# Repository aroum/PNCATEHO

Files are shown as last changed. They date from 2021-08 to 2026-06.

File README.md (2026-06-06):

<p align="center">
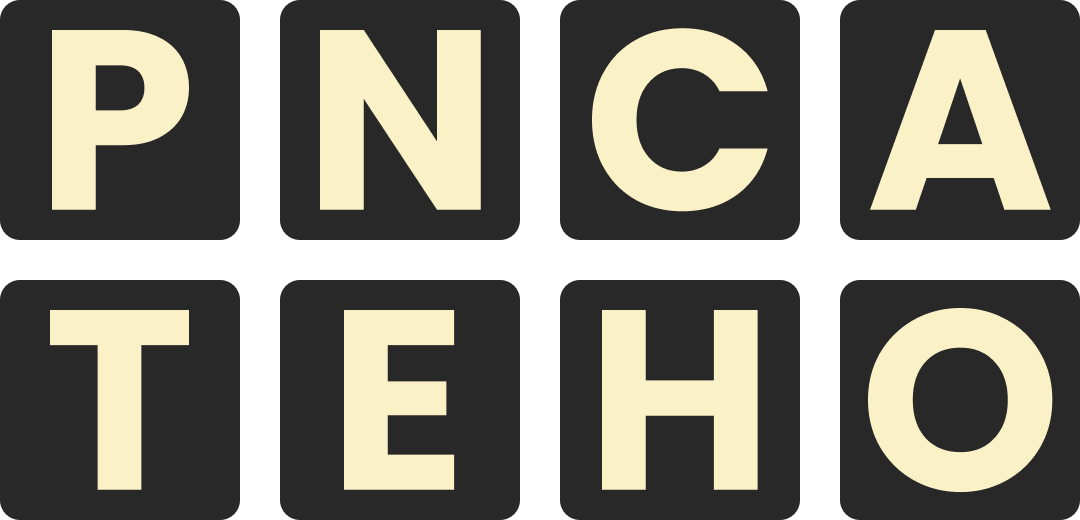
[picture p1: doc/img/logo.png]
  
</p>
<p align="center">
  
  
  
</p>
<p align="center">
  <a href="https://github.com/aroum/PNCATEHO/tree/master/firmware">Firmware | </a>
  <a href="https://github.com/aroum/PNCATEHO/releases">Gerber | </a>
  <a href="../doc/socket.md">About socket</a>
</p>

---

## About

РИСАТЕНО (__RISATENO__) - created as a rethinking of [ARTSEY](https://artsey.io/) for the Russian language. 10 keys, two for each finger. The name is made up of letters on the main layer. The letters on the base layer are selected according to the. The original idea was to create a compact keyboard for chord typing, but it can also be used as a macro pad. When using two halves of РИСАТЕНО connected via Bluetooth, you can use the [Kladenets layout](https://ibnteo.github.io/kladenets/). But over time, PNCATEHO became something more. It is a synthesizer, a sampler, a MIDI keyboard, and a vast playground for your other experiments.

## Eras

Eras are a way to classify different versions of a project. The Stone Era reflects original ideas. The Glass Era reflects the community's desires and experiments with new switches. The Light Era illuminates the vision of the creators who use this project as a platform for professional growth and attempt what others were afraid to do.

| Name | Alt Name  | Era | Swtiches | Hot-swap | LED | Wireless | MCU |
| --- | --- | ----- | --- | --- | --- | --- | --- |
| V4 | - | Stone | Choc V1 | ❌ | Per-key | Optional | proMicro like |
| V5 | - | Glass | Choc V1/V2 | ✅ | Per-key | Optional | proMicro like |
| MK_Dose | Dozateno  | Glass | MK Dose/MX | ✅ | 3 Led indication | Optional | proMicro like |
| Welcome | Nizkoteno | Light | PG1316S | ❌<br> | Per-key | ❌<br> | rp2040 |

### Stone

The standard version of PNCATEHO from the Stone era. Supports per-key backlighting, the option to use a wireless controller with an external power switch and reset button, and an open case. It does not support hot-swapping switches and only supports Choc V1. [more about stone](stone/readme.md)

> [!WARNING]  
> In version 0.3 of the board there is a bug with the backlight on the right-hand half.

#### V0.3

<p align="center">
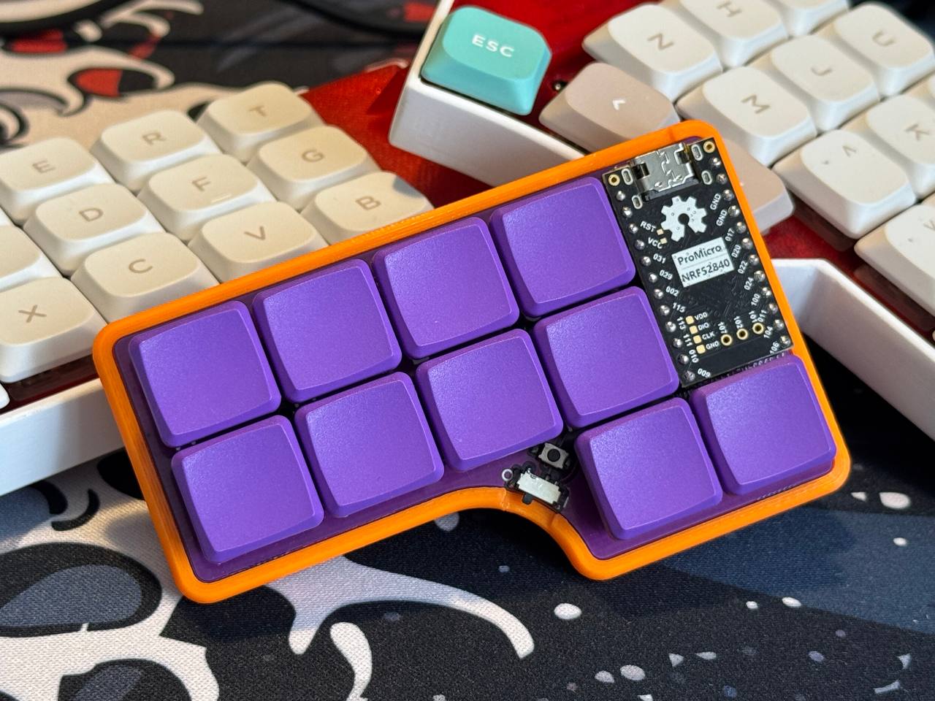
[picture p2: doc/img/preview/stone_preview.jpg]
  
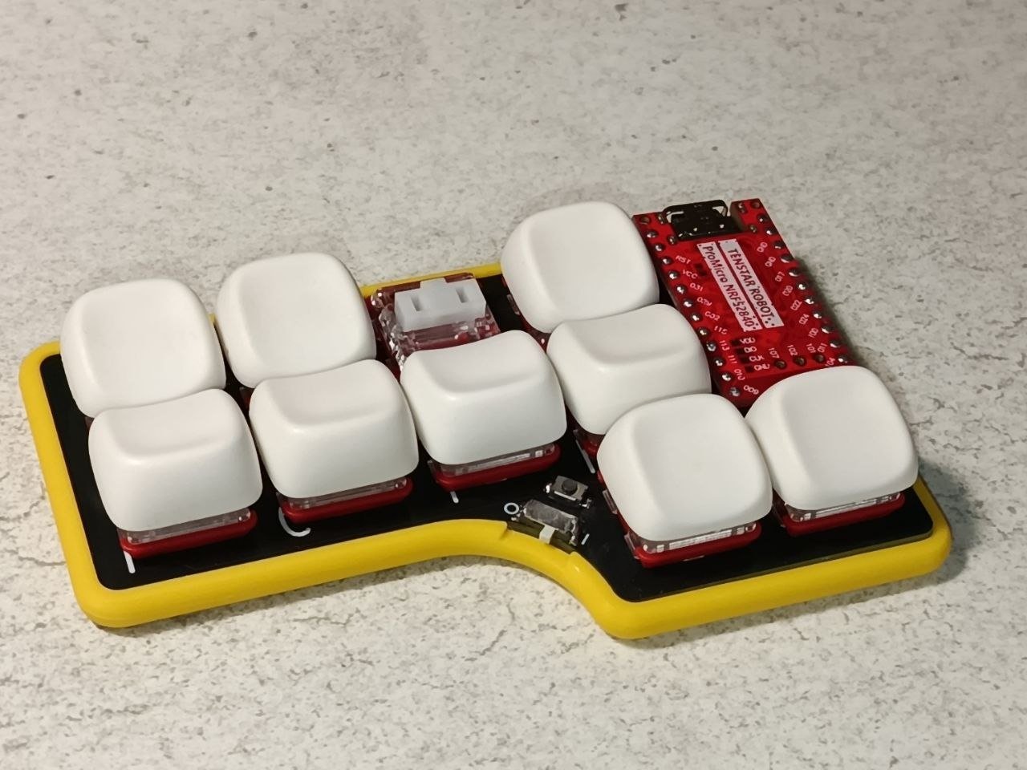
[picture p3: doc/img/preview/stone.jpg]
  
</p>

#### 3D

<p align="center">
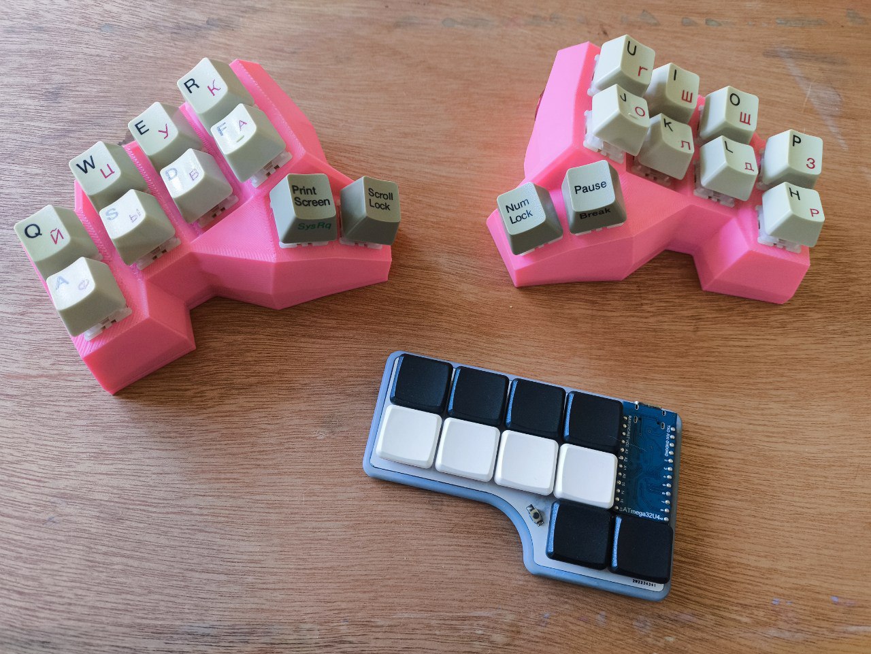
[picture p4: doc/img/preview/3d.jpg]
  
</p>

### Glass

The modern era of PNCATEHO development. It differs from the Stone era in that it supports hot-swappable keys and ChocV1/V2, MK Dose, and MX switches. It also uses closed cases and a new design approach by turtle_bazon. [more about Glass](glass/readme.md)

> [!TIP]
> If you want to build a PNCATEHO with MX switches, you can use the PCB from MK Dose.

#### V5

<p align="center">
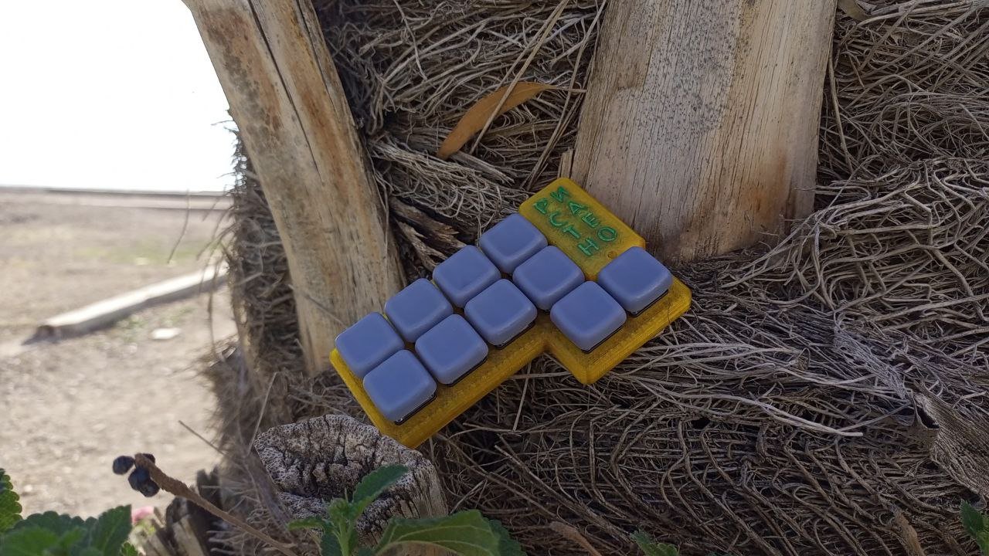
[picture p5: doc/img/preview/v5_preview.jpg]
  
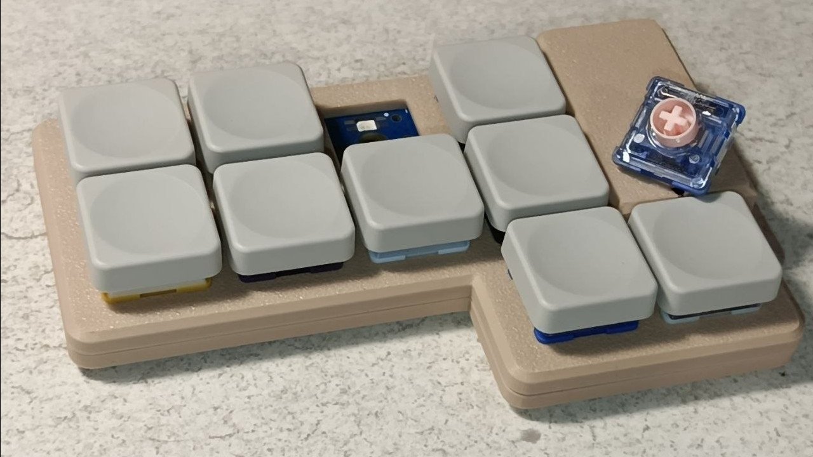
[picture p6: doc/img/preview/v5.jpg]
  
</p>

#### MK_Dose

<p align="center">
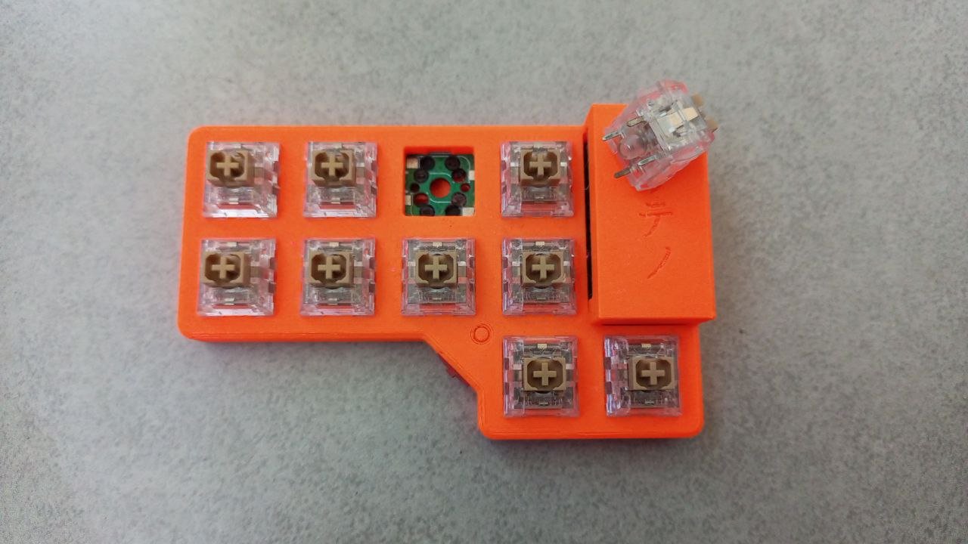
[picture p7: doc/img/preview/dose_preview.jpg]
  
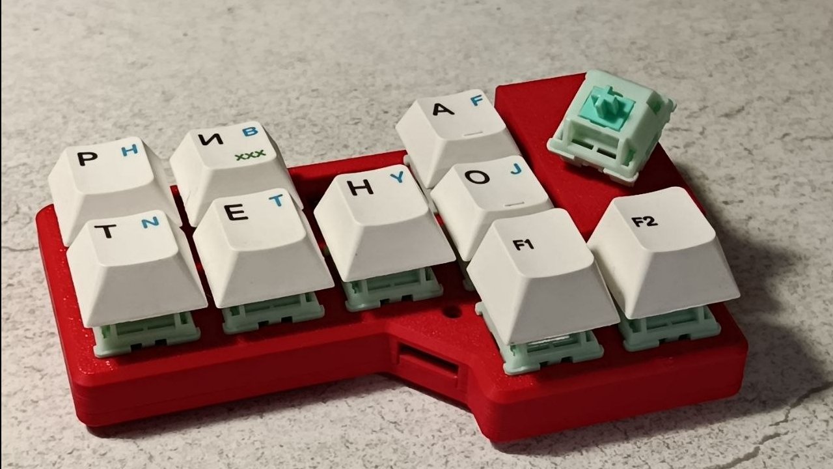
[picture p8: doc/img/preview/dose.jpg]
  
</p>

### Light

This is an era where the controller is soldered directly onto the PCB, exploring various form factors such as, for example, a PNCATEHO the size of a card. A project can become a flashlight, a development board, or even a portable gaming console. It all depends on the imagination of the community. The main contribution to this era has been made by the authors of the inpudiy community. [more about light](light/readme.md)

#### Welcome

<p align="center">
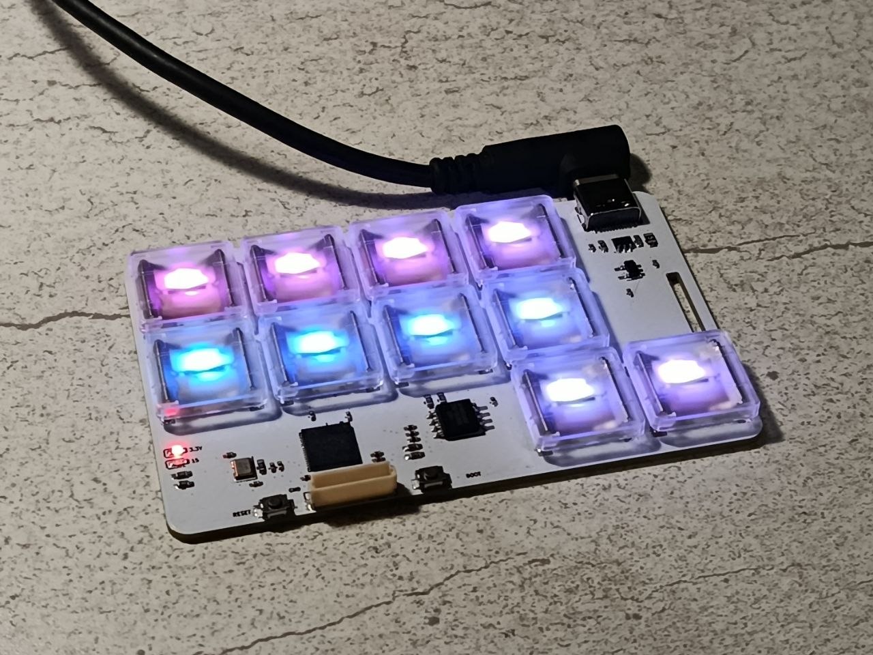
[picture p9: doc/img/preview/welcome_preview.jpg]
  
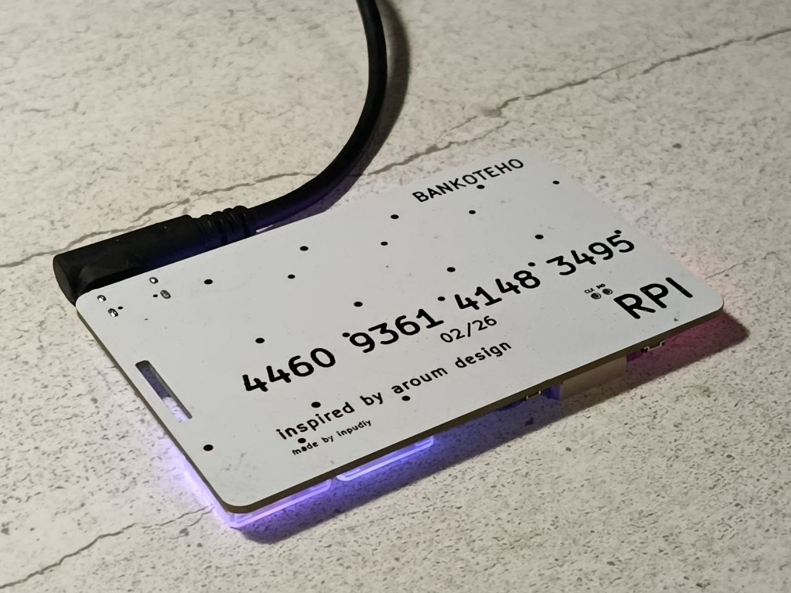
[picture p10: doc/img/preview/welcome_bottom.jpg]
  
</p>

## FAQ

### What is it for?

First and foremost, PNCATEHO is a fun project. It shouldn't be treated as an everyday keyboard—it’s more of a novelty, like a fridge magnet. That said, some people actually try to apply PNCATEHO's concepts to their daily-driver keyboards.

In many ways, the project served as a testing ground for experimenting with chording and exploring just how far you can minimize the number of keys. Of course, nothing stops you from using PNCATEHO as a macropad. There are also firmwares available to turn PNCATEHO into a sampler, synthesizer, or MIDI keyboard.

I wanted to design a layout that was simple and intuitive, yet still capable of acting as a near-full replacement for a standard keyboard. Unlike ARTSEY, I don’t use chords that require pressing more than two keys simultaneously. I also designed the layout based on letter frequency rather than just picking pleasant-sounding combinations. On top of that, I added two thumb keys—it felt odd to allocate two keys for every other finger while leaving the thumbs with nothing.

### Why PNCATEHO/RISATENO/РИСАТЕНО?

PNCATEHO is a loose transliteration of the Russian word "РИСАТЕНО" (RISATENO) into the Latin alphabet. The layout was designed based on letter frequency ([Wikipedia](https://ru.wikipedia.org/wiki/%D0%A7%D0%B0%D1%81%D1%82%D0%BE%D1%82%D0%BD%D0%BE%D1%81%D1%82%D1%8C)), where the first eight letters are four vowels ('И', 'А', 'Е', 'О') and four consonants ('Р', 'С', 'Т', 'Н'). To create a pronounceable name, they can be grouped into syllables: reading them one way gives __RISATENO__, and the other way gives __NOTESARI__ (options like "ONETASIR" were discarded as awkward-sounding). The second option felt a bit too "samurai," so I went with the first.

As a nice bonus, if you set aside the Cyrillic letter "И", the name transliterates perfectly into the Latin alphabet, and the letter "N" works great as a visual substitute for "И".

### Why no ergonomic stagger?

PNCATEHO was never meant to be an everyday keyboard—aesthetics take priority over ergonomics here, and in my opinion, ortholinear layouts look much cleaner. Besides, when you only have two keys per finger, column-staggering doesn't really make much of a difference anyway.

### How do you type on it?

Letter by letter, “dancing” your fingers to form chords. I tried to distribute chords by ease of pressing, so that the most common symbols use the simplest and most comfortable combinations. With some effort, you can learn all the common chords in a couple of days and, although slowly, fully type using just 10 keys with one hand.

It’s quite an unusual experience, especially if you’ve never used chords before. I strongly recommend printing the layout ([GitHub](https://github.com/aroum/PNCATEHO/tree/master/firmware)) and opening any beginner touch-typing app — even if you already know how to type on a regular keyboard, this will be a completely new and unique experience that you’ll likely never need anywhere else.

### Is this steno?

No, steno works completely differently ([example layout](https://github.com/openstenoproject/plover/files/247728/Russian.alphabet.and.layout.pdf)). It requires more keys and a different method. PNCATEHO, on the other hand, is letter-by-letter input based on frequency.

If you’re interested in steno, it’s worth starting with [Plover](https://www.openstenoproject.org/plover/).

## Inspiration

* [ARTSEY](https://artsey.io/)
* [The Paintbrush](https://github.com/artseyio/thepaintbrush)
* [Helix](https://github.com/MakotoKurauchi/helix)
* [wakizashi](https://klava.wiki/hypha/%D0%BA%D0%BB%D0%B0%D0%B2%D0%B8%D0%B0%D1%82%D1%83%D1%80%D1%8B/%D0%B2%D0%B0%D0%BA%D0%B8%D0%B4%D0%B7%D0%B0%D1%81%D0%B8) (saw after the release of PNCATEHO)

## Contribute list

* [aroum](https://github.com/aroum)
* [mayoroffk](https://github.com/mayoroffk)
* [turtle-bazon](https://github.com/turtle-bazon)
* [miwoho](https://github.com/miwoho)

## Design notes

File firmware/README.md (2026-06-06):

# Firmware

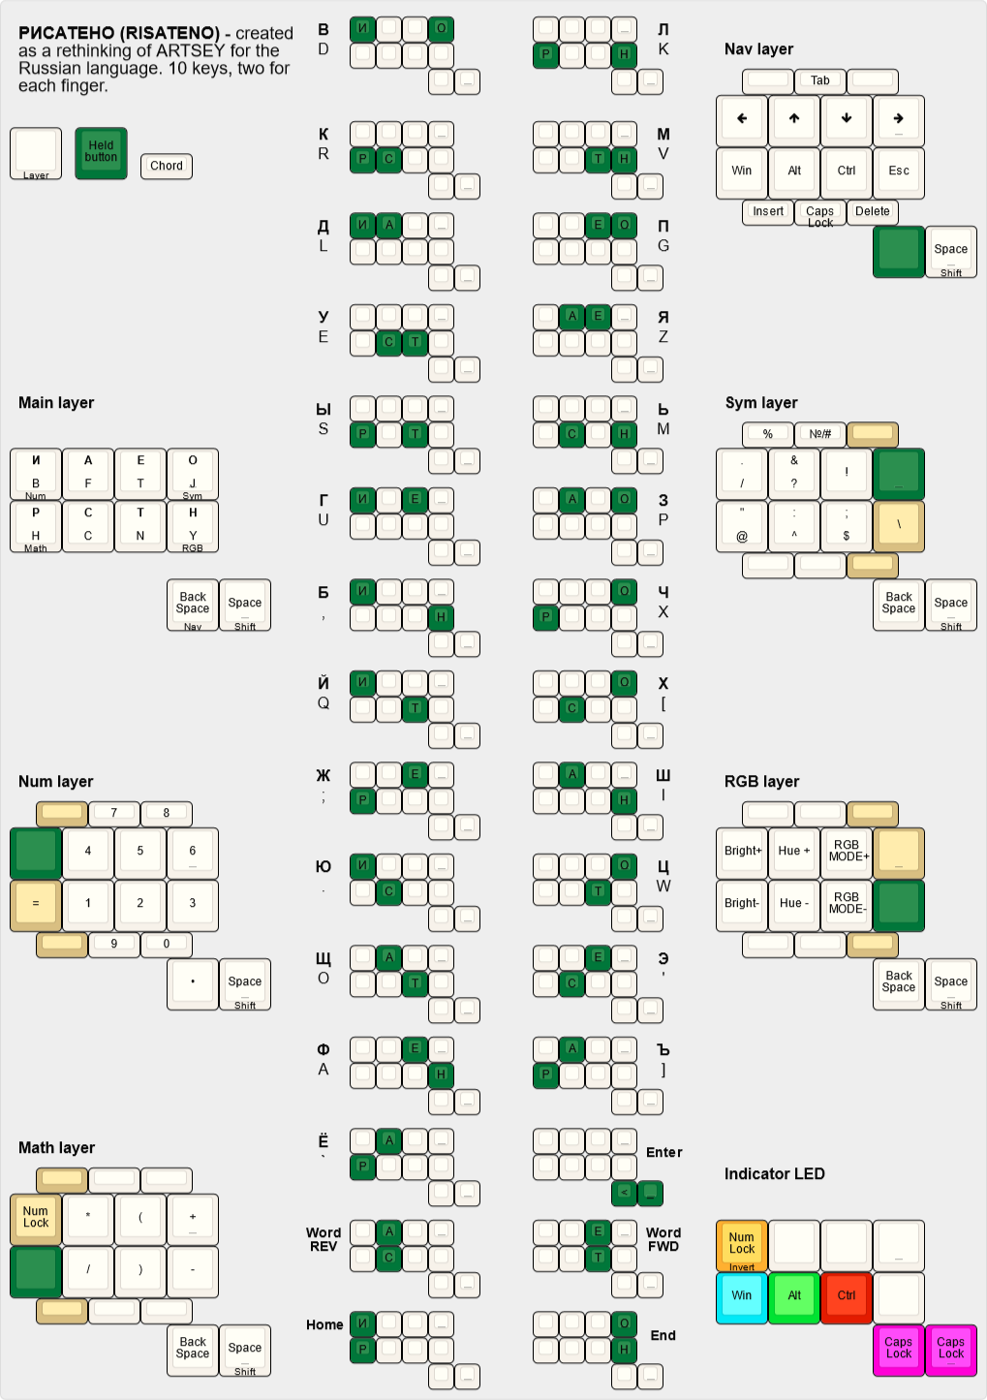
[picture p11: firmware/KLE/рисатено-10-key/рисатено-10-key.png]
layout


The core concept of PNCATEHO is to use only 2-key chords for all inputs, making it an efficient 10-key keyboard with extensive functionality.

## KLE

[Layout on the KLE website](http://www.keyboard-layout-editor.com/#/gists/019e404b4ab5db93cd75010ad90777a4)

[Unused chords on the KLE website](http://www.keyboard-layout-editor.com/#/gists/b4924b372f7e59832365545de1e1671c)

## QMK

QMK is the recommended firmware for most PNCATEHO variants. It provides full feature support including macros and layer switching.

**Installation:**

1. Copy the `QMK/PNCATEHO` folder to your QMK installation at `keyboards/pncateho`
2. Run `qmk compile -kb pncateho -km default`
3. Flash the resulting `.hex` file to your keyboard

Or download precompiled firmware from [releases](https://github.com/aroum/PNCATEHO/releases).

For more information, see [QMK documentation](https://docs.qmk.fm/).

## ZMK

ZMK is a lightweight firmware designed for wireless keyboards. Configuration and builds are available in separate repositories:

- **For nizkoteno**: [ZMK config for nizkore](https://github.com/inpudiy/zmk-PNCATEHO_Welcome_keyboard)
- **For other variants**: [ZMK config for PNCATEHO](https://github.com/aroum/zmk-PNCATEHO)

## RMK

RMK (Rust Mechanical Keyboard) is a Rust-based firmware for RP2040 microcontrollers. The implementation is optimized for nizkoteno but can be adapted to other PNCATEHO variants by modifying the pin configuration.

- Repository: [rmk-nizkoteno](https://github.com/aroum/rmk-nizkoteno/)
- **Compatibility:** Works with any PNCATEHO variant (except dozateno) when using an RP2040-based microcontroller

## MIDI

A simple MIDI keyboard implementation for nizkoteno. This firmware turns your PNCATEHO into a MIDI controller, perfect for music production and DAW integration.

- Repository: [midi-nizkoteno](https://github.com/aroum/midi-nizkoteno)
- **Compatibility:** Works with any PNCATEHO variant (except dozateno) when using an RP2040-based microcontroller with adjusted pin configuration

## nizkore

A sampler firmware port from pikocore, offering sound playback and sequencing capabilities. Originally created for nizkore but can be adapted to other PNCATEHO variants.

- Repository: [nizkore](https://github.com/aroum/nizkore/)
- **Compatibility:** Works with any PNCATEHO variant (except dozateno) when using an RP2040-based microcontroller with adjusted pin configuration

## pra32-u

A synthesizer firmware port optimized for the nizkoteno form factor. Enables real-time synthesis and parameter control directly from the keyboard.

- Repository: [pra32-u-pico-sdk](https://github.com/aroum/pra32-u-pico-sdk/)
- **Compatibility:** Works with any PNCATEHO variant (except dozateno) when using an RP2040-based microcontroller with adjusted pin configuration

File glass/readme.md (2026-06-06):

# glass

The modern era of PNCATEHO development. It differs from the Stone era in that it supports hot-swappable keys and ChocV1/V2, MK Dose, and MX switches. It also uses closed cases and a new design approach by turtle_bazon.

## v5

An updated version of the PCB by turtle_bazon. It retains the core features of the Stone era, while adding support for Choc V2, as well as hot-swappable switches, an enclosed case, and a PCB with a more refined design.

preview

<p align="center">
  <a href="case/v5/">Case | </a>
  <a href="build_v5.md">Build Guide</a>
</p>

### Features

* 10 keys, Kailh Choc **V1/V2** switches
* **Hot-Swap Socket**
* MX spacing
* Direct pins
* Three mounting screws
* One PCB for right and left versions
* Wireless (optional)
* Per switch RGB (optional)
* Power switch for wireless controllers (optional)
* Two halves placed on one 100x100mm pcb (optional)

### PCB

The current PCB version is 0.5.2. For manufacturing, it is recommended to use 100×100 mm Gerber files. This way, 5 boards become 10 halves (with an extra cute keychain in between).

<p align="center">
  
  
</p>

### Case

To assemble the case, you need to print the following files:

* PNCATEHO_MK_DOSE-case-bottom-left - top part of the case
* PNCATEHO_MK_DOSE-case-top-left.step -  bottom part of the case
* PNCATEHO_MK_DOSE-reset-button-pusher.step - reset button actuator
* PNCATEHO_MK_DOSE-case-top-cover-blank-left - controller cover

There are also different versions of the controller cover with katakana or lp. Additionally, the case [directory](../glass/case/MK_DOSE) includes an editable FreeCAD file: **PNCATEHO_v5.FCStd**.

### BOM

| Item | Quantity | Remarks |
| --- | ---: | --- |
| nice!nano | 1 | or any other pro micro compatible controller |
| Kailh Choc V1/2 | 10 | switches |
| Hot swap sockets | 10 | CPG135001S30 |
| YS-SK6812MINI-E | 10 | RGB leds |
| Machine Pin Socket with 2.54mm pitch | 12x2 | for controller |
| RGB Led pin or brass wire | 12x2 | for pin header |
| SMD button 3x4x2mm | 1 | for reset |
| MSK-12C02 | 1 | power switch  (wireless only) |
| 301230 3.7v li-po | 1 | battery  (wireless only) |
| Silicone rubber feet | 5 | 10x2 mm |
| M2х6 screw | 3 | for case |
| Keycaps | 10 | 1U |

## MK Dose (dozateno)

A version of the PCB designed for MK Dose format switches. It also supports standard MX switches. It differs by lacking per-switch backlighting, but includes indication using three SMD LEDs. Like V5, it features an enclosed case available in several variations.

preview

<p align="center">
  <a href="case/MK_DOSE/">Case | </a>
  <a href="build_mkdose.md">Build Guide</a>
</p>

### Features

* 10 keys, MK Dose/MX switches
* 3 Led indication
* **Hot-Swap Socket**
* MX spacing
* Three mounting screws
* One PCB for right and left versions
* Wireless (optional)
* Power switch for wireless controllers (optional)
* Two halves placed on one 100x100mm pcb (optional)

### PCB

it is recommended to use 100×100 mm Gerber files. This way, 5 boards become 10 halves (with an extra cute keychain in between).

<p align="center">
  
  
</p>

### Case

To assemble the case, you need to print the following files:

* PNCATEHO_v5-bottom-case-left - top part of the case
* PNCATEHO_v5-top-case-left.step -  bottom part of the case
* PNCATEHO_v5-power-switch-pusher.step - power switch actuator
* PNCATEHO_v5-reset-button-pusher.step - reset button actuator
* PNCATEHO_v5-top-cover-left-blank.step - controller cover

There are also different versions of the controller cover with the **PNCATEHO** label in *ReggageOne* or *RubikMonoOne* fonts.
Additionally, the case [directory](../glass/case/v5) includes an editable FreeCAD file: **PNCATEHO_MK_DOSE.FCStd*.

### BOM

| Item | Quantity | Remarks |
| --- | ---: | --- |
| nice!nano | 1 | or any other pro micro compatible controller |
| MK Dose or MX Swtich | 10 | switches |
| Hot swap sockets | 10 or 20 | CPG151101S11 |
| Diode 1N4148W | 10 or 20 | for matrix |
| 0603 led | 3 | for indication |
| 0603 1-10k resitsor | 3 | for led |
| Machine Pin Socket with 2.54mm pitch | 12x2 | for controller |
| RGB Led pin or brass wire | 12x2 | for pin header |
| SMD button 3x4x2mm | 1 | for reset |
| BSI-10H | 1 | power switch  (wireless only) |
| 301230 3.7v li-po | 1 | battery  (wireless only) |
| Silicone rubber feet | 5 | 8x2 mm |
| m2х8 screw | 3 | for case |
| Keycaps | 10 | 1U |

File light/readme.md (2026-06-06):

# light

This is an era where the controller is soldered directly onto the PCB, exploring various form factors such as, for example, a PNCATEHO the size of a card. A project can become a flashlight, a development board, or even a portable gaming console. It all depends on the imagination of the community. The main contribution to this era has been made by the authors of the inpudiy community.

## welcome (nizkoteno)

A credit card–sized RP2040-based PCB with a clean design, PG1316 low-profile switches, and integrated per-key RGB lighting.

preview

<p align="center">
  <a href="https://htmlpreview.github.io/?https://github.com/inpudiy/PNCATEHO/blob/master/light/welcome/doc/ibom.html" style="text-decoration: none;">IBOM |</a>
  <a href="welcome/doc/schematic.pdf" style="text-decoration: none;"> Schematic PDF | </a>
  <a href="welcome/doc/build.md" style="text-decoration: none;"> Build guide</a>
</p>

### Features

* 10 low profile keys, PG1316 switches
* Debit card dimensions (ISO/IEC 7810 ID-1)
* Per switch WS2812 2020 led
* Soldered directly onto the RP2040 board
* ESD protection
* 16 MB flash memory
* cutout for a strap
* exposed 10-pin JST connector for connecting modules

### PCB

The current PCB version is v1.1. For ordering, specify a board thickness of 1.6 mm and a stencil for the top side of the board.

<p align="center">
  
  
</p>

### JST

A BM10B-SRSS-TB connector is installed on the board. This is a 10-pin JST connector with a 1 mm pitch. The leftmost pin is connected to ground, and the rightmost pin provides 3.3V. Between them, the following GPIOs are exposed: 29, 28, 27, 26, 24, 21, 20, 19.

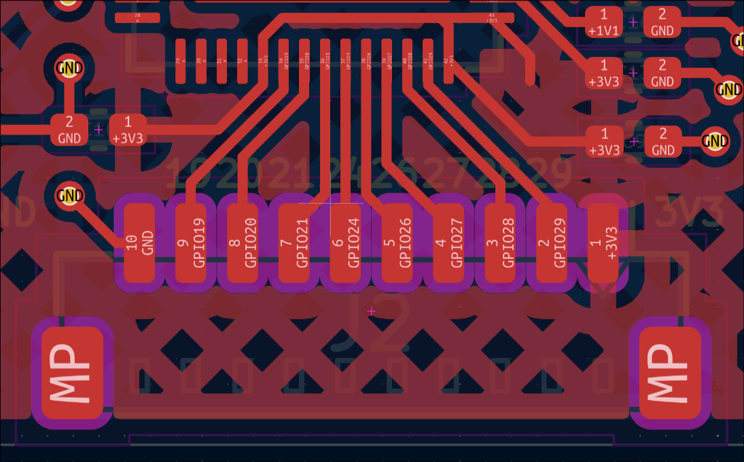
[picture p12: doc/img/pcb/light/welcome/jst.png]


To run the controller, a stable 3.3V supply is required, while the RGB pins should receive 5V.

> [!WARNING]  
> DO NOT attempt to connect an external 3.3V supply while simultaneously powering the board via USB.

### Firmwares

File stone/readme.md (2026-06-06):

# STONE

The standard version of PNCATEHO from the Stone era. Supports per-key backlighting, the option to use a wireless controller with an external power switch and reset button, and an open case. It does not support hot-swapping switches and only supports Choc V1.

preview

<p align="center">
  <a href="case/case_v4.stp">Case | </a>
  <a href="build.md">Build Guide</a>
</p>

## V0.3

### Features

* 10 keys, Kailh Choc V1 switches
* Choc spacing
* Direct pins
* Three mounting screws
* One PCB for right and left versions
* Wireless (optional)
* Per switch RGB (optional)
* Power switch for wireless controllers (optional)
* Two halves placed on one 100x100mm pcb (optional)

### PCB

There are several versions of the PCB. In version 0.3, the right half has an error in the LED footprints, so the backlighting can only be installed facing downward. This issue, along with other minor ones, was fixed in version 0.4.

For manufacturing, it is recommended to use 100×100 mm Gerber files. This way, 5 boards become 10 halves (5 right and 5 left).

### Case

In the case directory, there are two STEP files. case_v4.stp does not have cutouts for rubber feet, while case_v4_flex.stp includes 7 cutouts for rubber feet.

<p align="center">
  
  
</p>

### Plate

No plate is needed for choc, but if you want you can order PCB or laser cut. These don't fit version 3 boards because you can't add screw cutouts.

### BOM

| Item | Quantity | Remarks |
| --- | ---: | --- |
| nice!nano | 1 | or any other compatible controller |
| Kailh Choc V1 | 10 | switches |
| Keycaps | 10 | 1U |
| YS-SK6812MINI-E | 10 | RGB leds |
| Magnets | 2-6 | disc 7x2 mm (for case) |
| Sockets PH5.0mm | 12x2 | for controller |
| SMD button 3x4x2mm | 1 | for reset |
| MSK-12C02 | 1 | power switch  (wireless only) |
| 301230 3.7v li-po | 1 | battery  (wireless only) |
| Silicone rubber feet | 7 | 5x2 mm |
| M2 nuts | 3 | for case v3+ |
| M2x4 sqrews | 3 | for case v3+ |

## 3D

preview

### Case

The case folder contains a STEP file. The controller, circuitry, and mounting method are entirely up to you.

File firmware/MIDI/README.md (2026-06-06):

# MIDI Firmware

This firmware transforms your PNCATEHO into a MIDI controller, enabling seamless integration with Digital Audio Workstations (DAWs), synthesizers, and other MIDI-compatible devices.

## Overview

A straightforward MIDI keyboard implementation originally developed for nizkore. The firmware can be adapted to other PNCATEHO variants by reconfiguring pin assignments.

## Repository

- [midi-nizkoteno](https://github.com/aroum/midi-nizkoteno)

## MIDI Channel Assignment

Each key combination can be configured to transmit on different MIDI channels. Refer to the source code or firmware documentation for detailed channel mapping.

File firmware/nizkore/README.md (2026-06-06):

# nizkore Firmware

nizkore is a powerful sampler firmware for PNCATEHO, enabling playback of audio samples and real-time control over playback parameters. It's a port of the pikocore sampler, optimized for the PNCATEHO form factor and 2-key chord interface.

## Overview

This firmware transforms your PNCATEHO into a portable audio sampler with intuitive 2-key chord-based control. Originally developed for nizkore, it can be adapted to other PNCATEHO variants using RP2040-based microcontrollers.

## Repository

- [nizkore](https://github.com/aroum/nizkore/)

## Compatibility

- **Supported:** nizkore and other PNCATEHO variants with RP2040-based microcontrollers
- **Unsupported:** dozateno (different microcontroller architecture)

For more information about pikocore, visit the [original project](https://github.com/schollz/pikocore).

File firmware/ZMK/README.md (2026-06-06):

# ZMK Firmware

ZMK is a modern, wireless-first firmware for mechanical keyboards, built on the Zephyr RTOS. It provides excellent battery life and advanced features for PNCATEHO variants.

## Configuration

Different PNCATEHO variants require different ZMK configurations:

### nizkoteno

For nizkoteno, use this dedicated configuration:

- [ZMK Config for nizkoteno](https://github.com/inpudiy/zmk-PNCATEHO_Welcome_keyboard)

### Other Variants

For all other PNCATEHO variants:

- [ZMK Config for PNCATEHO](https://github.com/aroum/zmk-PNCATEHO)

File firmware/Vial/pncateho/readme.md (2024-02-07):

# pncateho

*A short description of the keyboard/project*

* Firmware Maintainer: [Mayorov Kirill](https://github.com/FT256) [@Mayoroffk](https://t.me/mayoroffk)

Make example for this keyboard (after setting up your build environment):

    make pncateho:vial

Flashing example for this keyboard:

    make pncatehom:vial:flash

See the [build environment setup](https://docs.qmk.fm/#/getting_started_build_tools) and the [make instructions](https://docs.qmk.fm/#/getting_started_make_guide) for more information. Brand new to QMK? Start with our [Complete Newbs Guide](https://docs.qmk.fm/#/newbs).

## Bootloader

Enter the bootloader in 3 ways:

* **Bootmagic reset**: Hold down the top left up key and plug in the keyboard
* **Physical reset button**: Briefly press the button on the PCB
* **Keycode in layout**: Press the key mapped to `QK_BOOT` if it is available

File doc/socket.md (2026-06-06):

## Introduction

In order for a keyboard to register keystrokes, a microcontroller is used. Besides the microcontroller itself, it also requires supporting circuitry. Routing and soldering a board with a microcontroller significantly complicates the design and assembly process. To address this issue, development boards are used, which already have the microcontroller with the necessary supporting circuitry installed, as well as a charging module, a connection port, an antenna, and the required controller pins brought out, where the keyboard switches are directly connected.

In order to connect the keyboard switches to the development board, sockets are needed. Each creator uses their own solutions, so it is important to explain the differences between these approaches.

> [!IMPORTANT]
> The battery thickness may also depend on how the controller is installed. In most keyboards, controllers are mounted facing downward, so you need to subtract the height of the tallest component (the antenna or connector) from the socket height to determine the available space for the battery.

> [!WARNING]  
> PAY CLOSE ATTENTION TO THE SOCKET INFORMATION IN THE OFFICIAL REPOSITORY OF THE KEYBOARD YOU ARE BUILDING. DIFFERENT CONFIGURATIONS MAY BE USED FOR DIFFERENT CASE TYPES, EVEN WITHIN THE SAME PROJECT BUT IN DIFFERENT VERSIONS

## Main data

Let's start by defining the main data.

You might ask: why do we need a socket? Wouldn't it be simpler to just solder the boards together? Let’s imagine a situation where the development board fails, or conversely, the controller board is fine but the keyboard switches section is damaged. In such a case, you would have to desolder around 24 pins at once, or carefully remove solder from each pin individually. Trust me, you don’t want to do that—and if you do, it will take a lot of time and the chances of damaging the board increase significantly.

The solution to this problem is the use of sockets: female sockets are installed on the keyboard board, and male pins are soldered to the controller.

- Most likely, just like in PNCATEHO, your keyboard uses a Pro Micro–format board, which has 24 pins, and the board thickness is 1.6 mm (excluding components).
- On the vast majority of development boards, the pin spacing (pitch) is 2.54 mm.
- In popular wireless keyboard models, the battery most often used has dimensions H=3 mm, W=12 mm, and L=30 mm (301230).

## Dupont

### Square male pin header

A microcontroller development board comes with a row of **SQUARE** pins. These are sets of square posts held together by plastic, from which they can be easily removed. They can also be purchased separately in strips of 40 pins in different colors.

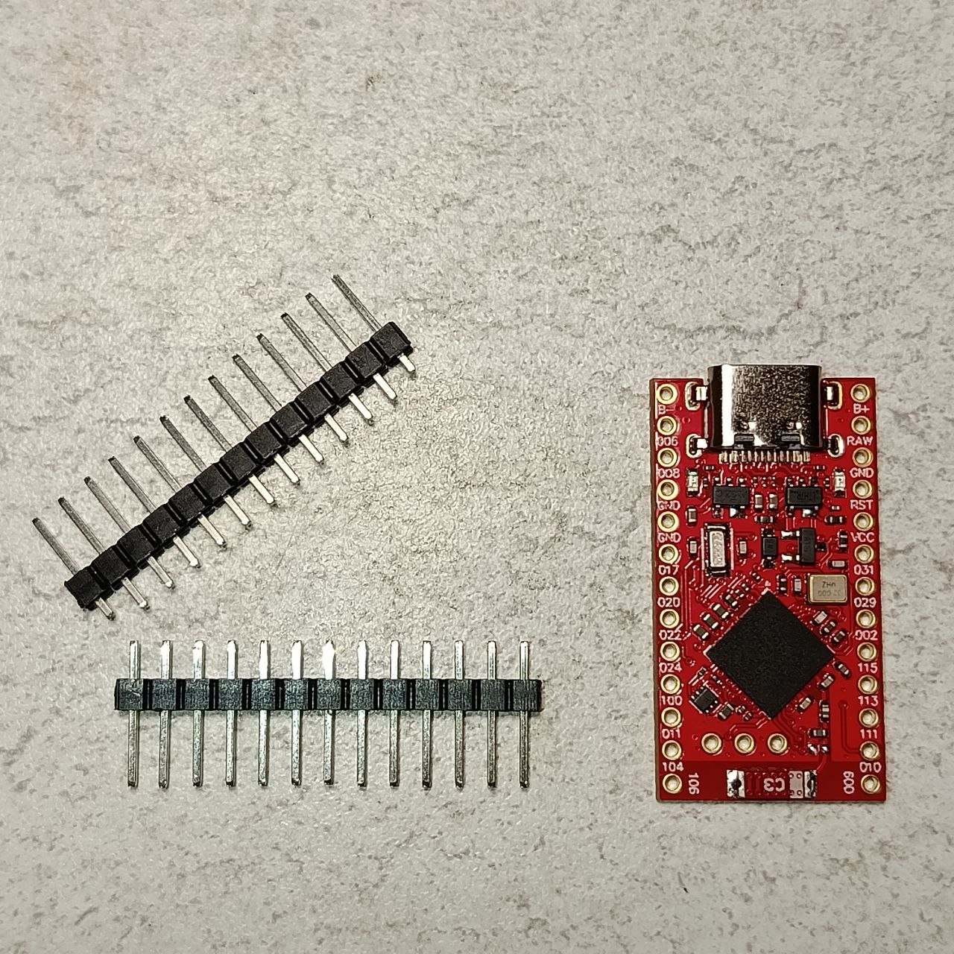
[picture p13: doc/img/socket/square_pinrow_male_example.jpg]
square


Due to the large number of manufacturers and the lack of strict quality control, the dimensions of these pins may differ from the datasheet by ±0.20 mm. For example, in my case, the plastic thickness is as much as 2.4 mm, while the pin length is only 11.32 mm instead of 11.5 mm.

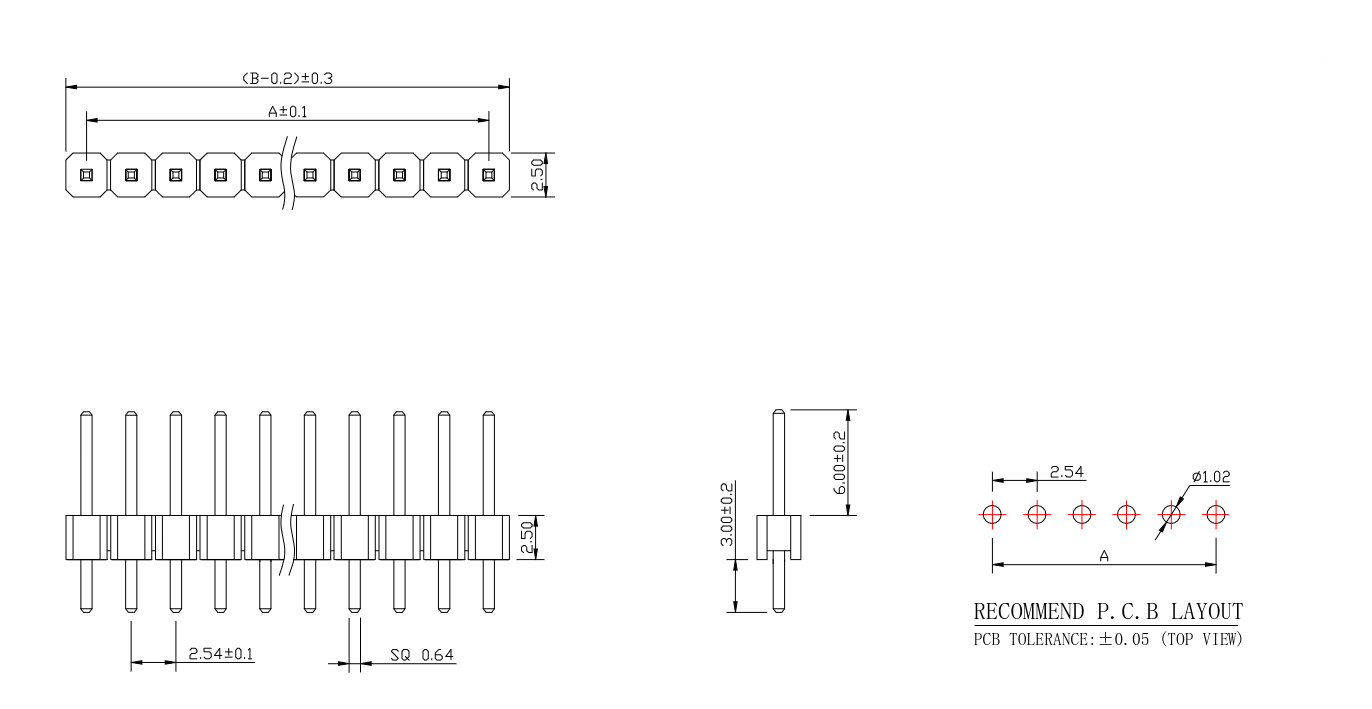
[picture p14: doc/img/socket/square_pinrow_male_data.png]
square


### Square female pin header

To use the pins that come in the kit, you need to purchase square pin headers. For keyboards, different height options are used; the most popular ones are 3.5 mm, 5 mm, and 5.7 mm anything taller is generally excessive.

The main issue is that the required sizes can be harder to find on common marketplaces (AliExpress and others). However, their strength and compatibility with the included pins make this option more practical compared to machine pin sockets.

Among the most common configurations, the following approaches can be highlighted:

#### First option

There are also configurations where the controller is installed with the flat side facing inward, allowing for a thicker battery. The examples below use a configuration where the controller is facing the PCB.

Install the sockets into the controller, cut off the top part, and remove the plastic. Then insert them into 5 mm or 5.7 mm pin headers. This spacing between the board and the controller allows the use of a 3+ mm thick battery.

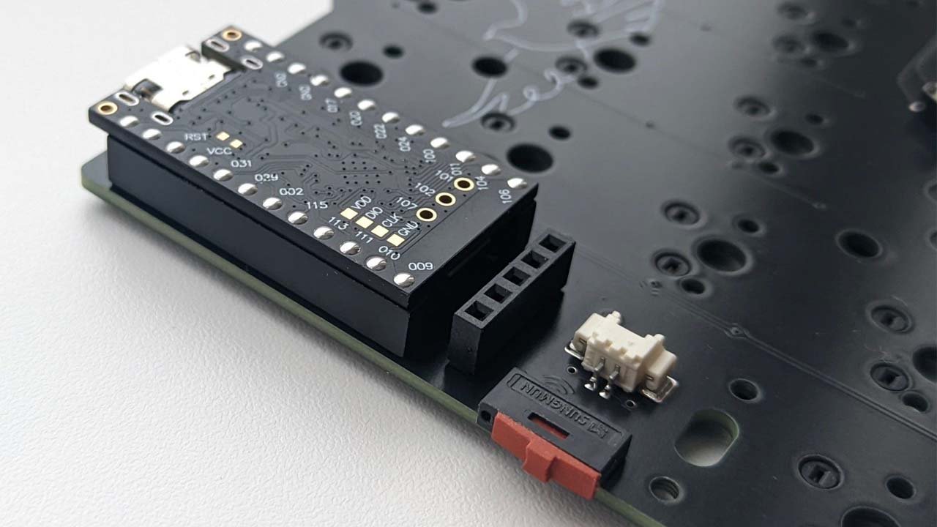
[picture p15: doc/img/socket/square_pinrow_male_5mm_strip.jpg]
square

*The keyboard in the photo: [Mriya](https://github.com/themaxbang/MRIYA)*

#### Second option

Use 3.5 mm pin headers, and install the stock sockets into the controller without removing the plastic only trim the pins above the controller. This also allows using a 31 mm thick battery.

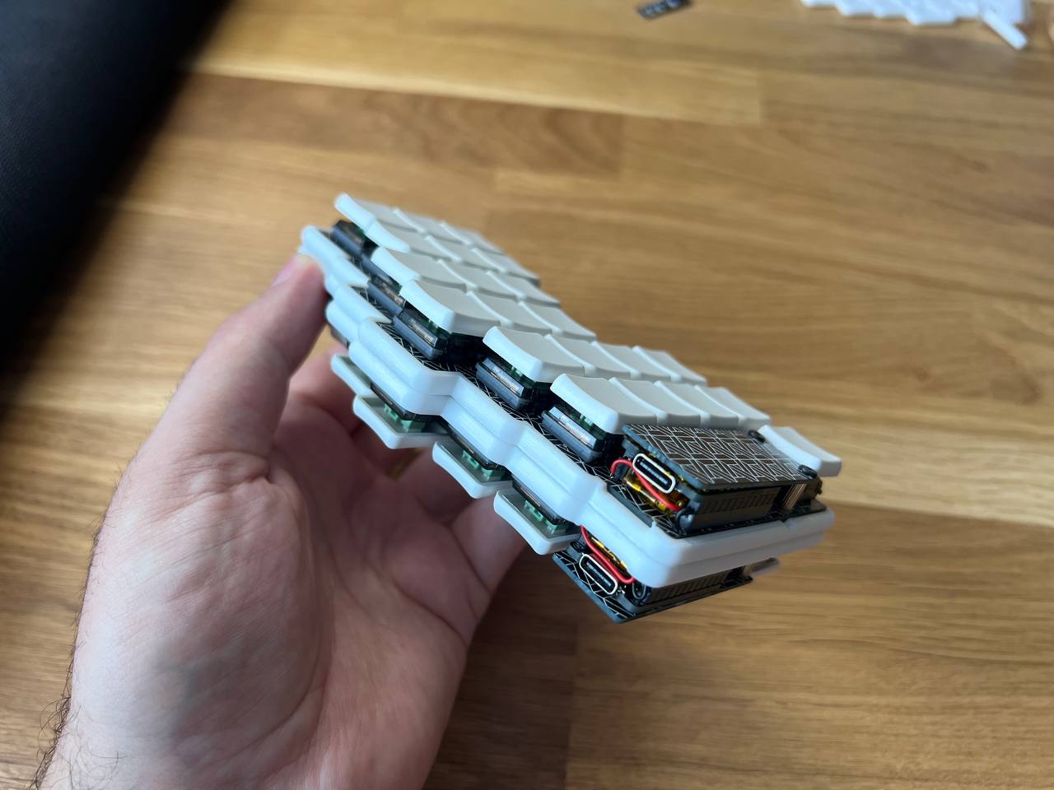
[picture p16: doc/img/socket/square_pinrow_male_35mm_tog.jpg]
square

*The keyboard in the photo: [gbEnki](https://github.com/aroum/gbEnki)*

#### Third option

Use 3.5 mm pin headers, remove the plastic from the stock sockets, and place a battery between the controller and the shield above it.

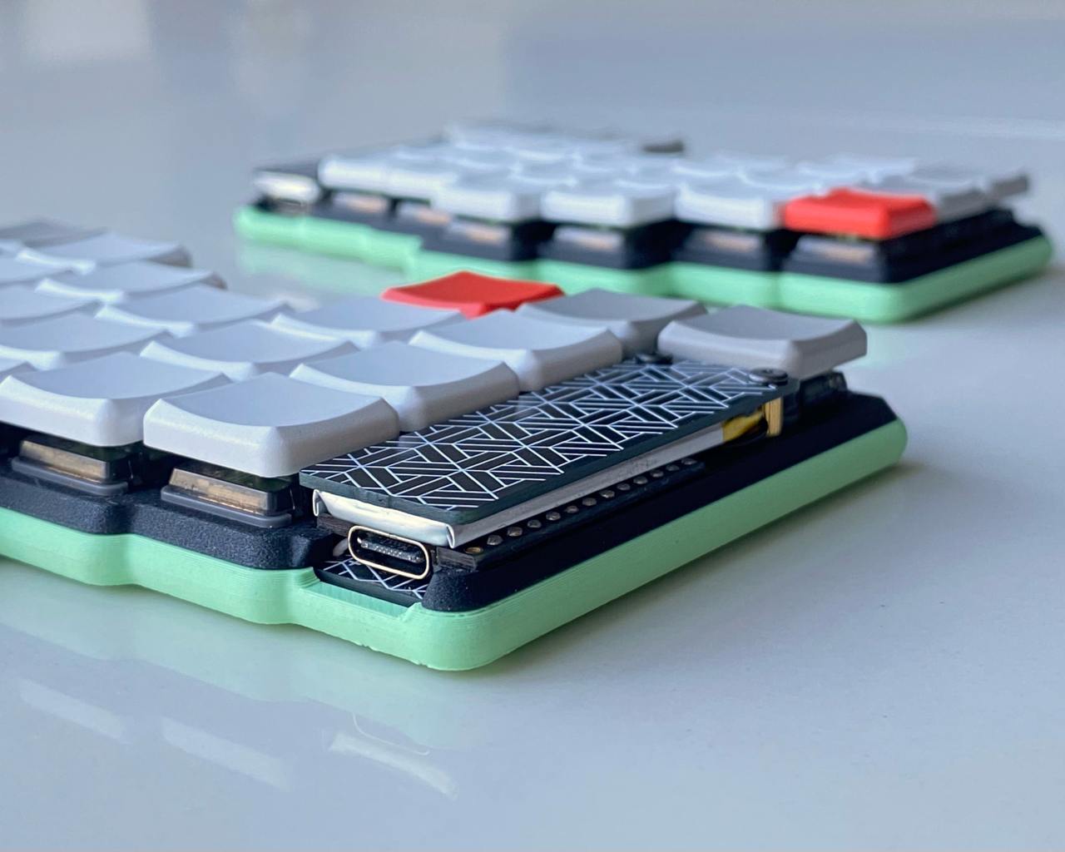
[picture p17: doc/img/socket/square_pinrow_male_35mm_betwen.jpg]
square


## Machine

### Square female pin header

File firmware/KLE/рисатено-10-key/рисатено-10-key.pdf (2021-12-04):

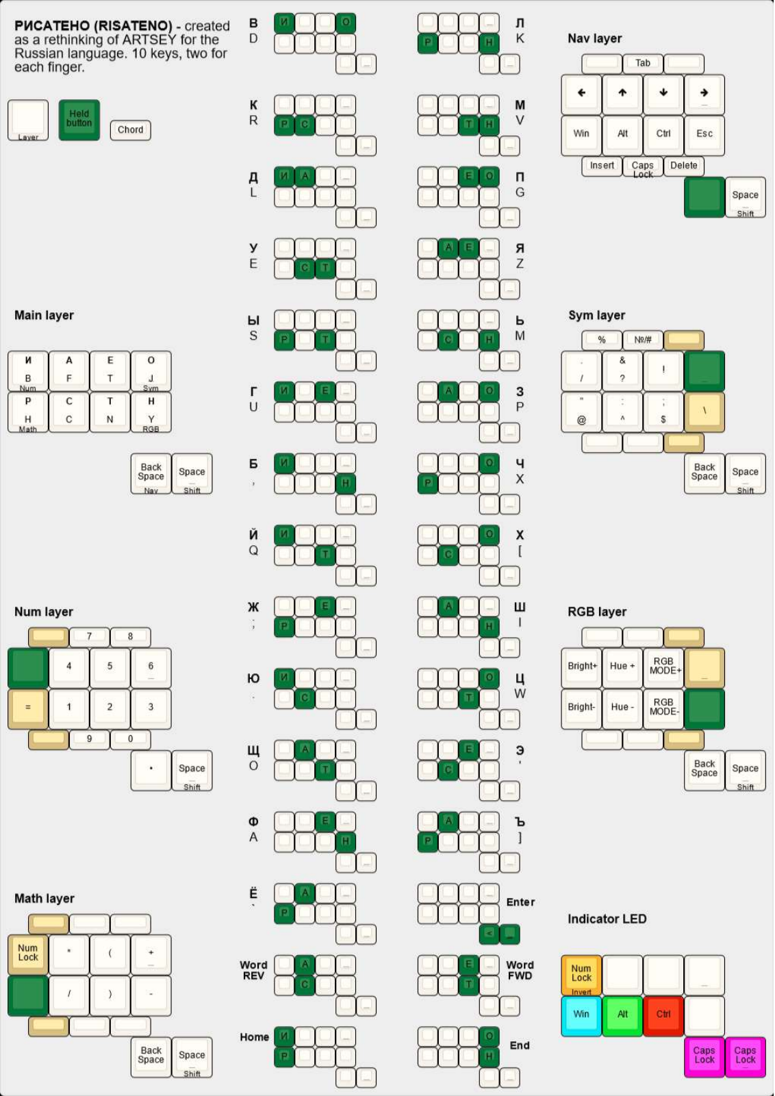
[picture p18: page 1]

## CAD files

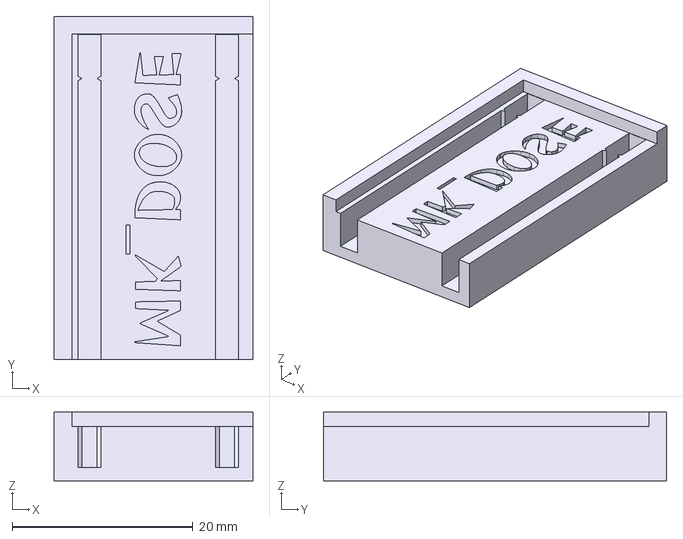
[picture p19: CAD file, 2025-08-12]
glass/case/MK_DOSE/helper/PNCATEHO_MK_DOSE-pin-headers-soldering-helper-left.step
22.0 x 38.0 x 7.60 mm

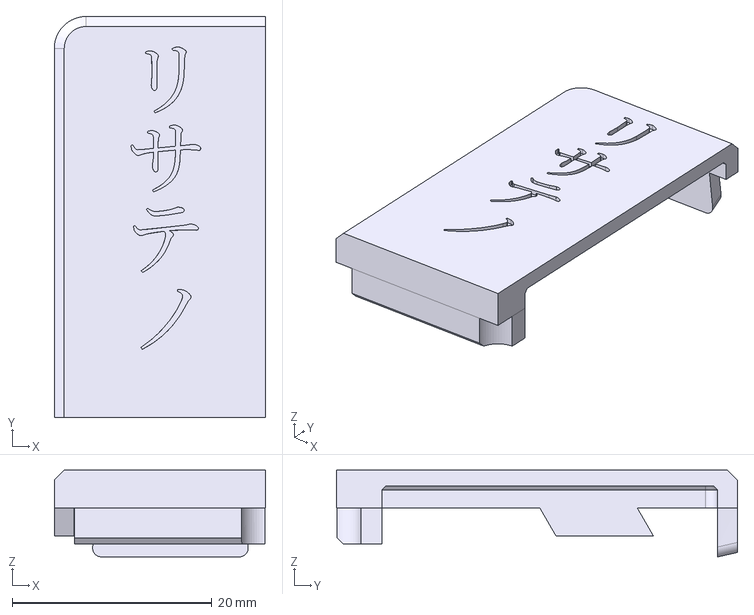
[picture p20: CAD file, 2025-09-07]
glass/case/MK_DOSE/PNCATEHO_MK_DOSE-case-top-cover-JP-katakana-right-lp.step
21.2 x 40.2 x 8.71 mm

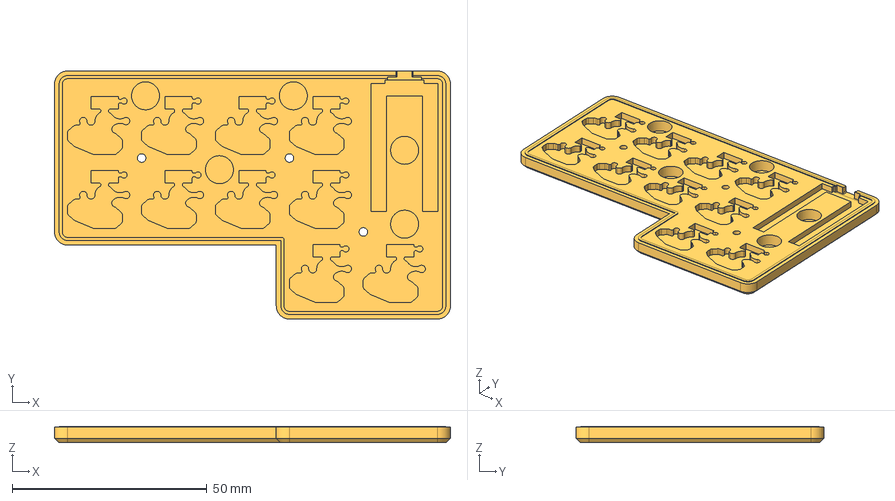
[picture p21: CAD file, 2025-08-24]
glass/case/v5/PNCATEHO_v5-bottom-case-left.step
101.8 x 63.8 x 4.20 mm

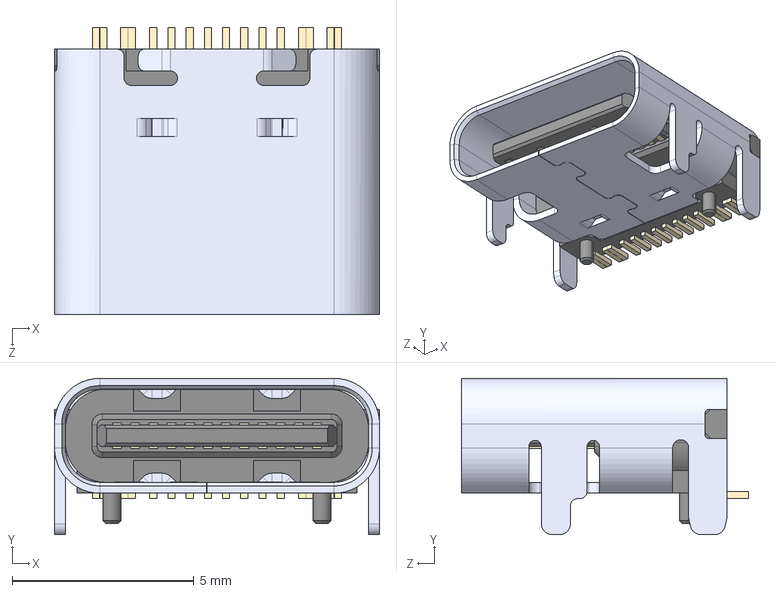
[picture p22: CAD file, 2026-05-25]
light/welcome/pcb/PNCATEHO_lib/step/TYPE-C-31-M-12--3DModel-STEP-56544.STEP
8.94 x 4.30 x 7.90 mm

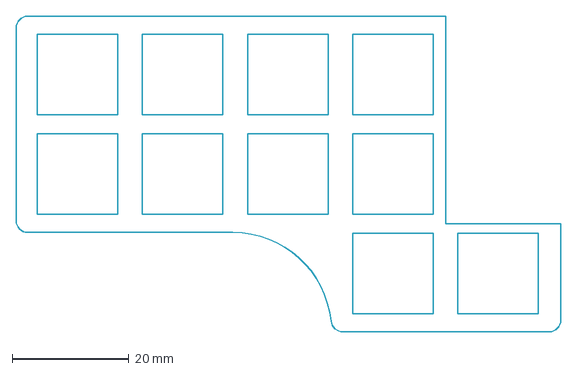
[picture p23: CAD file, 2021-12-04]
plate/cutting/plate.dxf
93.5 x 54.2 mm

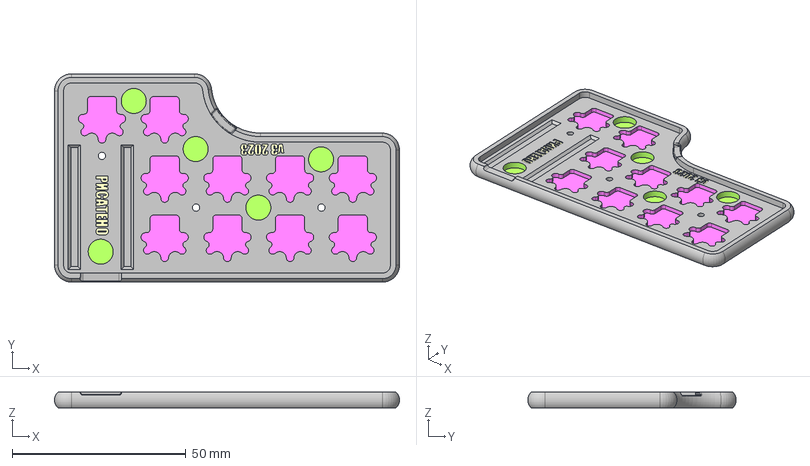
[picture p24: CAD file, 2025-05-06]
stone/case/case_v4.stp
99.3 x 60.0 x 4.60 mm

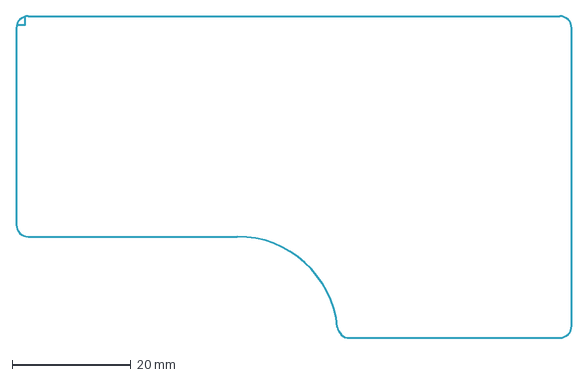
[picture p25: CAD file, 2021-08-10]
stone/pcb/shape.dxf
93.5 x 54.2 mm

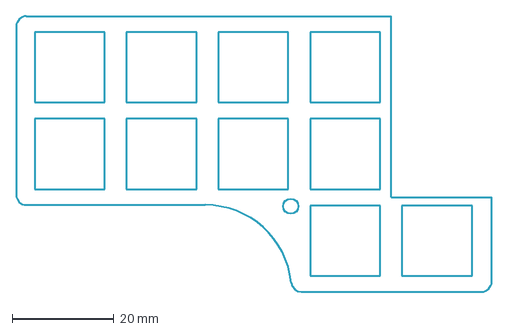
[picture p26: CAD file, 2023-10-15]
stone/plate/cutting/PNCATEHO_plate_v3.dxf
93.5 x 54.2 mm

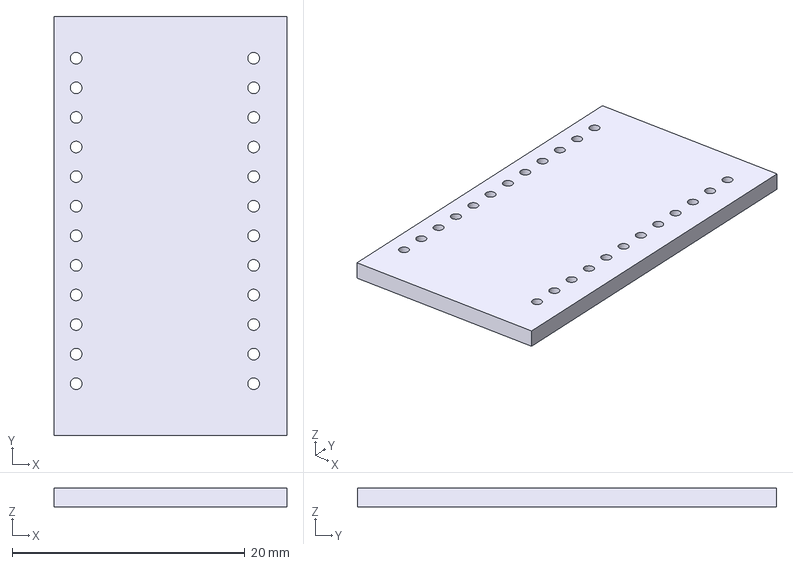
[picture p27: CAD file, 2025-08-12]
glass/case/MK_DOSE/helper/PNCATEHO_MK_DOSE-mcu-legs-cutting-helper-left.step
20.0 x 36.0 x 1.60 mm

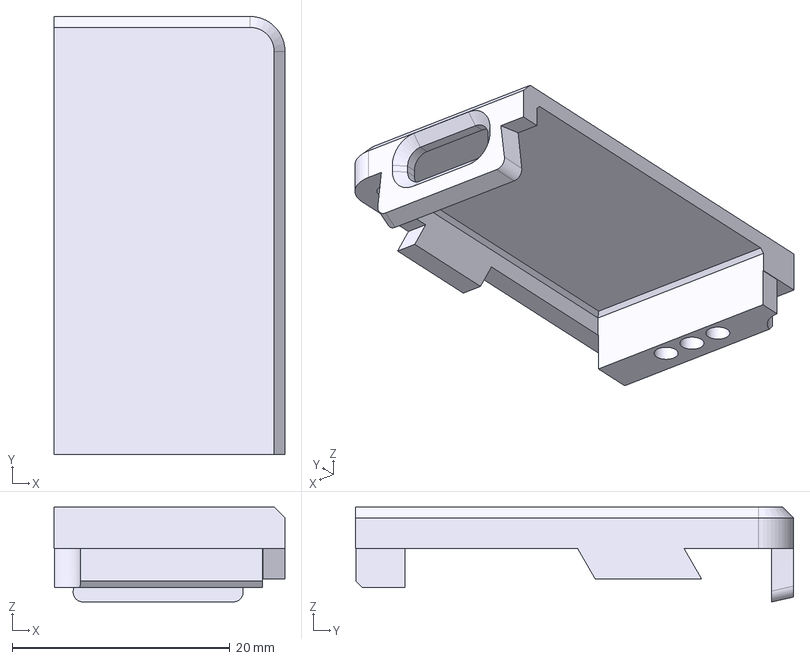
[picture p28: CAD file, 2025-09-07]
glass/case/MK_DOSE/PNCATEHO_MK_DOSE-case-top-cover-blank-left-lp.step
21.2 x 40.2 x 8.71 mm

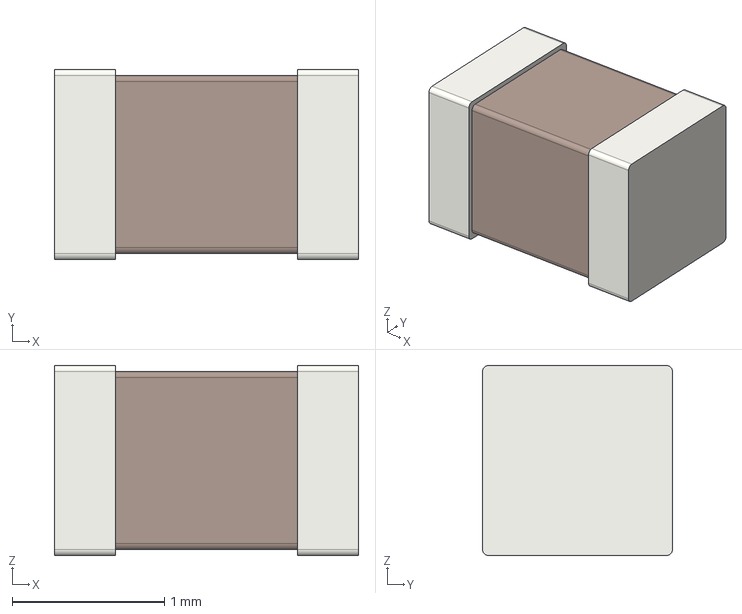
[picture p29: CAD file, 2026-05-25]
light/welcome/pcb/PNCATEHO_lib/step/C_0805_2012Metric.step
2.00 x 1.25 x 1.25 mm

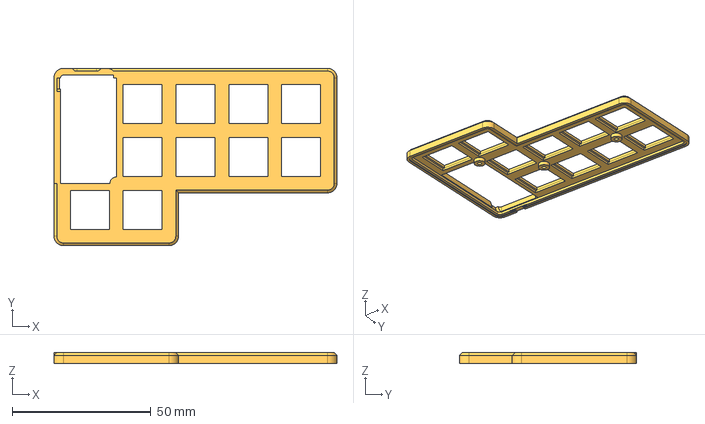
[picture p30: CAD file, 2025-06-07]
glass/case/v5/PNCATEHO_v5-top-case-right.step
101.8 x 63.8 x 3.80 mm

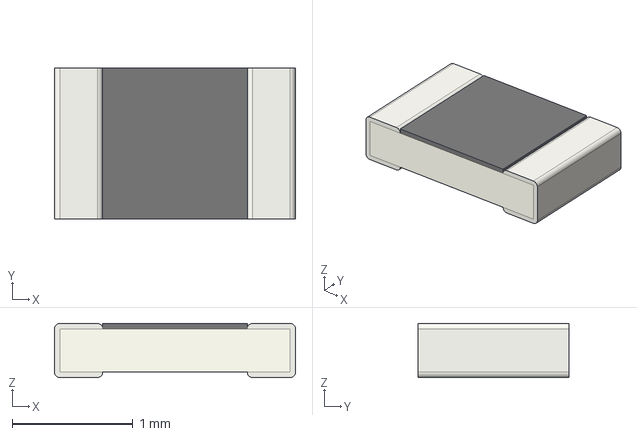
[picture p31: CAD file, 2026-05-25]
light/welcome/pcb/PNCATEHO_lib/step/Fuse_0805_2012Metric.step
2.00 x 1.25 x 0.45 mm

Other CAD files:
glass/case/v5/PNCATEHO_v5-bottom-case-right.step
stone/case/case_v4_flex.stp
glass/case/MK_DOSE/helper/PNCATEHO_MK_DOSE-mcu-legs-cutting-helper-right.step
glass/case/MK_DOSE/PNCATEHO_MK_DOSE-case-top-cover-JP-katakana-left-lp.step
glass/case/MK_DOSE/helper/PNCATEHO_MK_DOSE-pin-headers-soldering-helper-right.step
glass/case/MK_DOSE/PNCATEHO_MK_DOSE-case-bottom-left.step
glass/case/MK_DOSE/PNCATEHO_MK_DOSE-case-bottom-right.step
glass/case/MK_DOSE/PNCATEHO_MK_DOSE-case-top-cover-JP-katakana-left.step
glass/case/MK_DOSE/PNCATEHO_MK_DOSE-case-top-cover-JP-katakana-right.step
glass/case/MK_DOSE/PNCATEHO_MK_DOSE-case-top-cover-blank-left.step
glass/case/MK_DOSE/PNCATEHO_MK_DOSE-case-top-cover-blank-right-lp.step
glass/case/MK_DOSE/PNCATEHO_MK_DOSE-case-top-cover-blank-right.step
glass/case/MK_DOSE/PNCATEHO_MK_DOSE-case-top-left.step
glass/case/MK_DOSE/PNCATEHO_MK_DOSE-case-top-right.step
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

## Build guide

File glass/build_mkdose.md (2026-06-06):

## Diode

Solder the diodes, aligning the stripe on each diode with the stripe marked on the PCB.

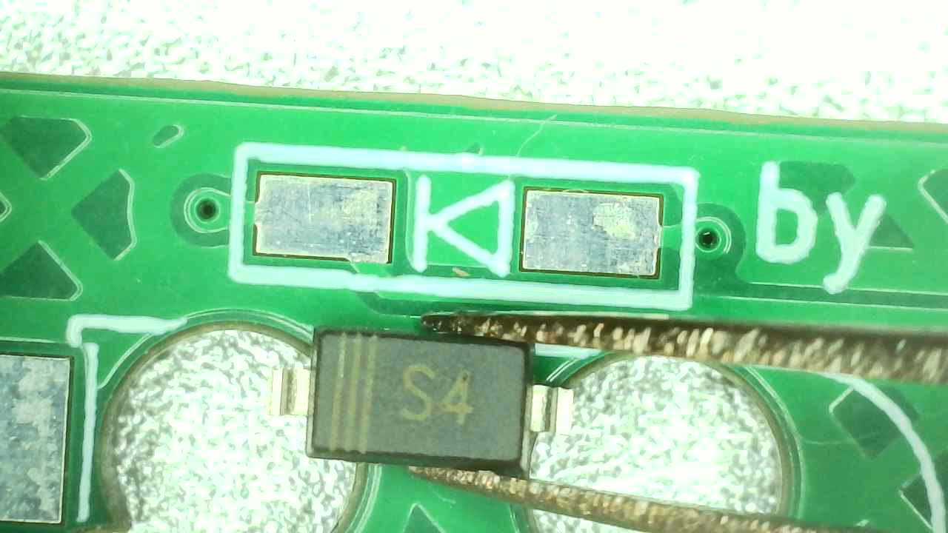
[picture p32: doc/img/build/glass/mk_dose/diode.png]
diode


## Hotswap

For the MX version, solder one hot-swap socket on the underside of the PCB. Install the socket next to the previously soldered diode. For the MK Dose version, solder both hot-swap sockets.

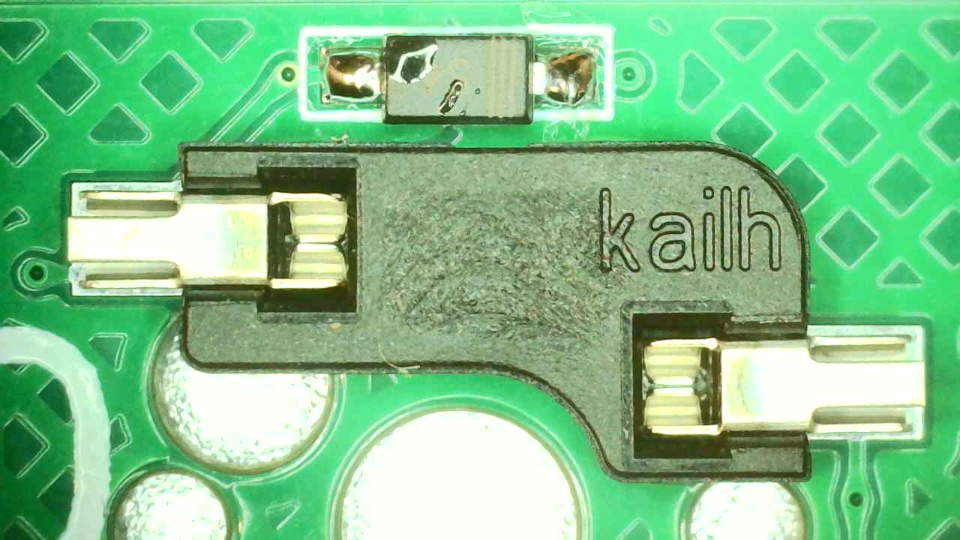
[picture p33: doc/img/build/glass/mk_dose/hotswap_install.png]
hotswap

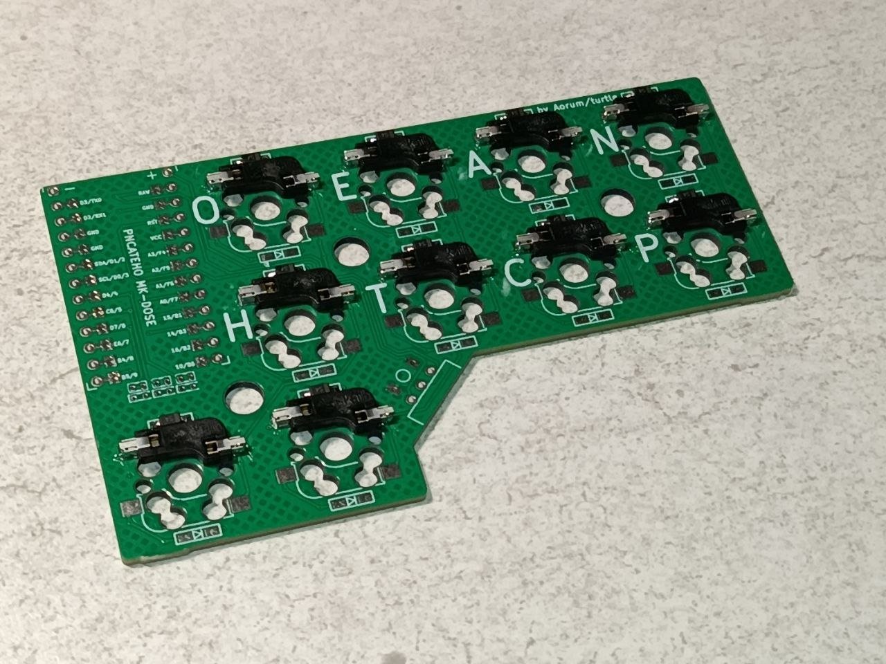
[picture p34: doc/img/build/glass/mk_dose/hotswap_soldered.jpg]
hotswap


## Led

In the controller area, install 3 resistors on the pads above and 3 LEDs on the pads below. Position the cathode toward the bracket marking.

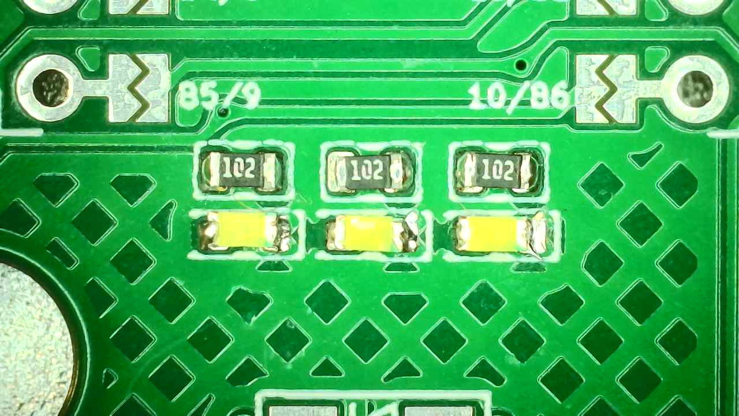
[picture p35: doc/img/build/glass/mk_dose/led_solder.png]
led_solder


## MCU Board
>
> [!WARNING]
> BE CAREFUL AND USE EYE PROTECTION WHEN CUTTING PLASTIC AND PINS. When trimming, cover the area with your hand to reduce the risk of small pieces of plastic or metal pins flying off toward your face or monitor.

Solder the jumpers on the underside of the PCB near the controller pins.

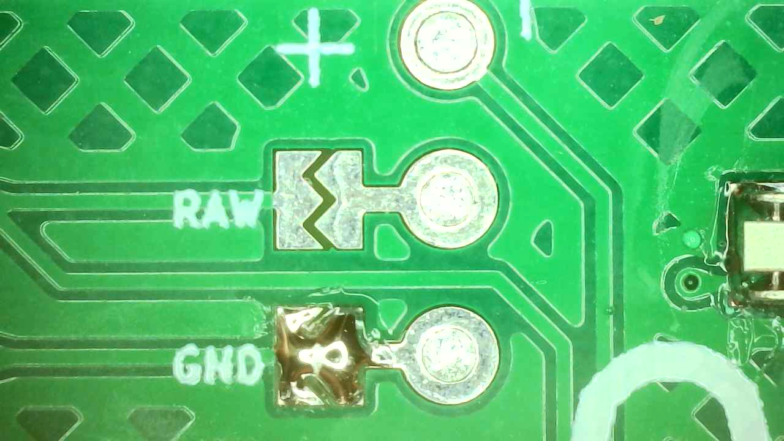
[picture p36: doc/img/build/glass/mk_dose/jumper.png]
jumper


Then install the headers with the socket facing upward and solder the pin supports (also from the underside). Leave the space for the battery pins empty and do not install any pins there.

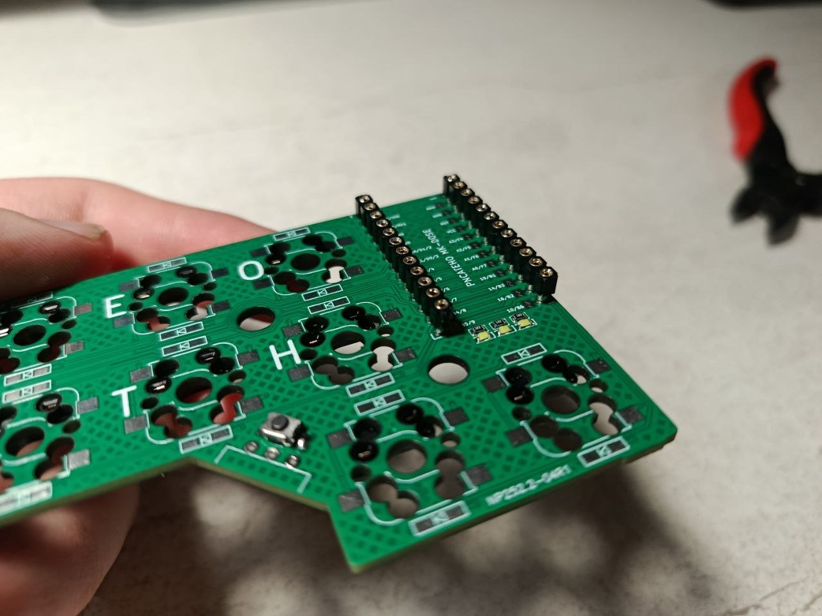
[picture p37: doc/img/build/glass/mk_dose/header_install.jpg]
header_install

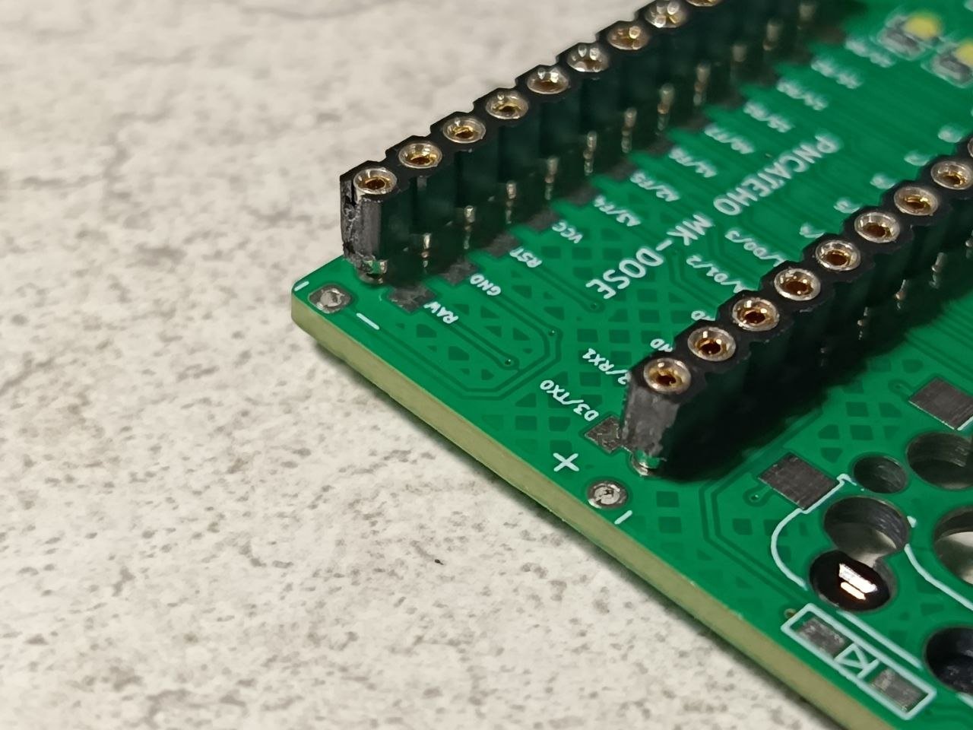
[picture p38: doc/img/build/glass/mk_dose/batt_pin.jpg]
bat_pin


Install the controller on top of the sockets. Then take a piece of wire or an RGB pin and cut it flush with the controller [see details here](../doc/socket.md). After that, solder all the pins to the controller.

To check that all pins are properly soldered, try to gently remove the controller from the sockets using something long and straight to avoid bending the pins.

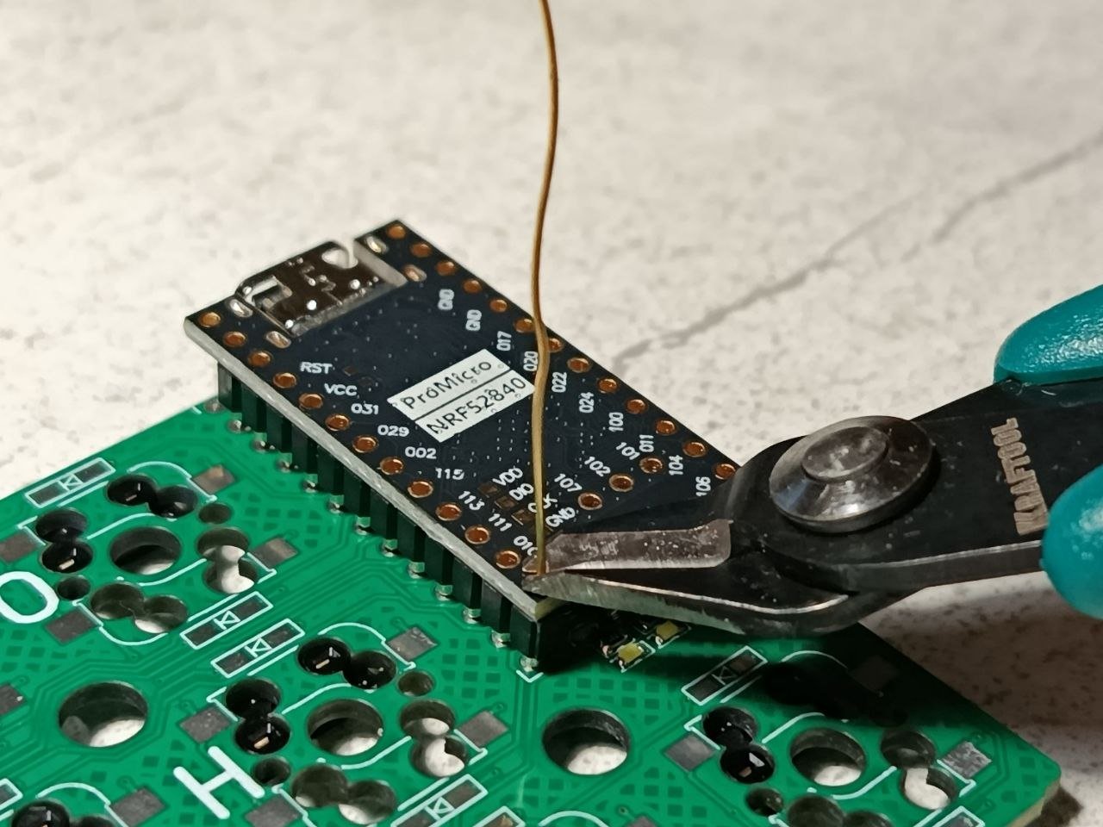
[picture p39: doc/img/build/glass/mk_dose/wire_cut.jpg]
wire_cut

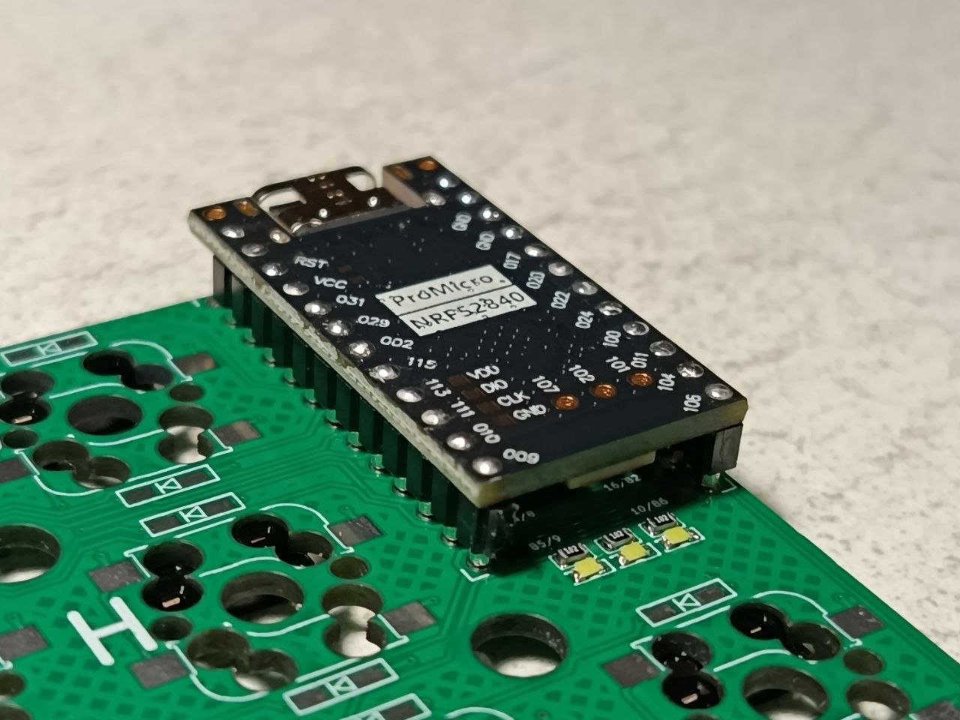
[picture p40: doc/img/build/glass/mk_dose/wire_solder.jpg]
wire_soldered


## Button and slider

Install the reset button and the BSI-10H connector. Trim the legs of the BSI on the underside of the PCB before soldering.

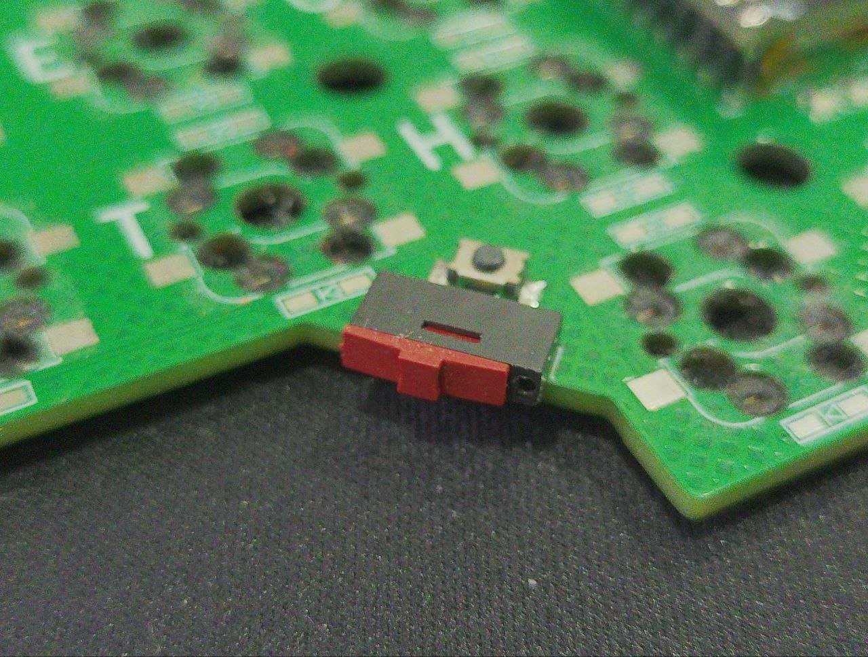
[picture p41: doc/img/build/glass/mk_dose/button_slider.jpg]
button_solder


## Case

Insert the PCB into the case. Tighten the case with screws from the bottom, then attach the feet.

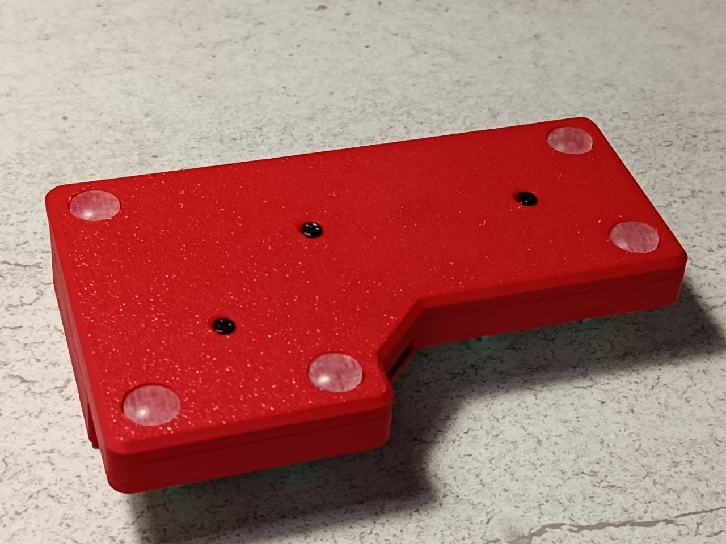
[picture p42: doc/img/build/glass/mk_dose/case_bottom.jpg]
case_bottom


## Finish

Install the keycaps. Then connect the controller to your computer with a cable, press the reset button twice, and flash the firmware.

**Congratulations, you’ve assembled your РИСАТЕНО!**

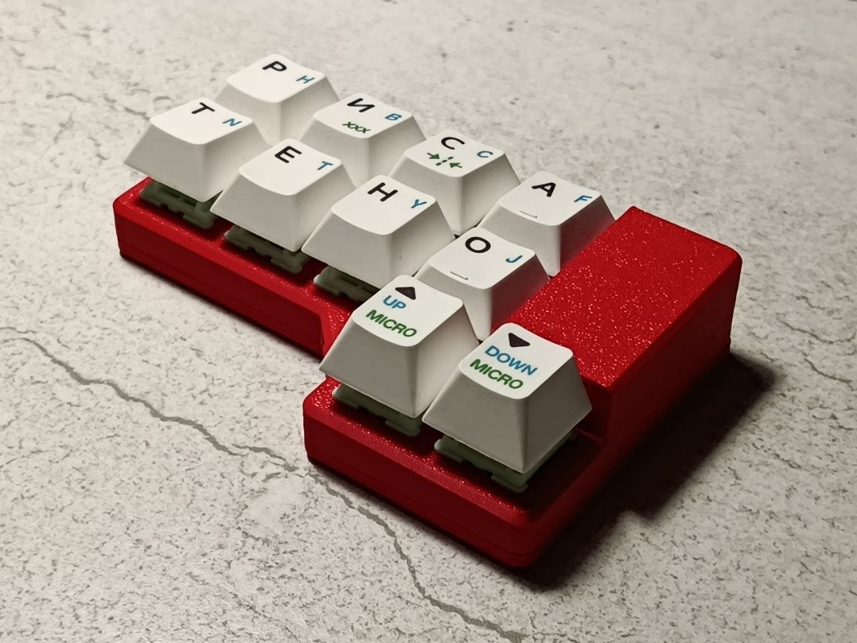
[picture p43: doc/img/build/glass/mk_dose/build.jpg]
build


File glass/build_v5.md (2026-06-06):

## Hotswap

Install all the hot-swap sockets and solder them in place. Carefully check the silkscreen on the PCB and align each socket accordingly.

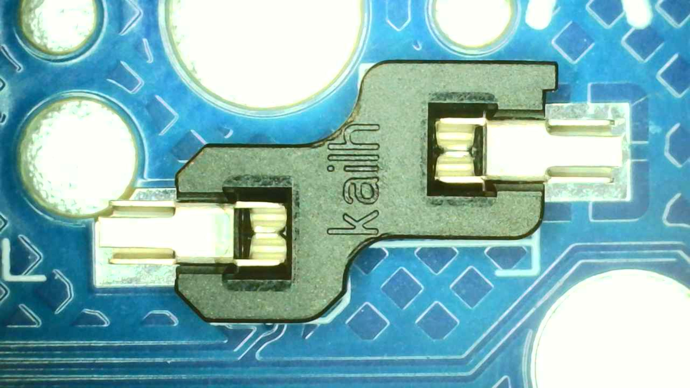
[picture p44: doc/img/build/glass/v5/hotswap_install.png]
hotswap


## Led

Install the YS-SK6812MINI-E LEDs by aligning the angled pin of the LED with the dot on the PCB. Repeat this for all LEDs, then solder them in place.

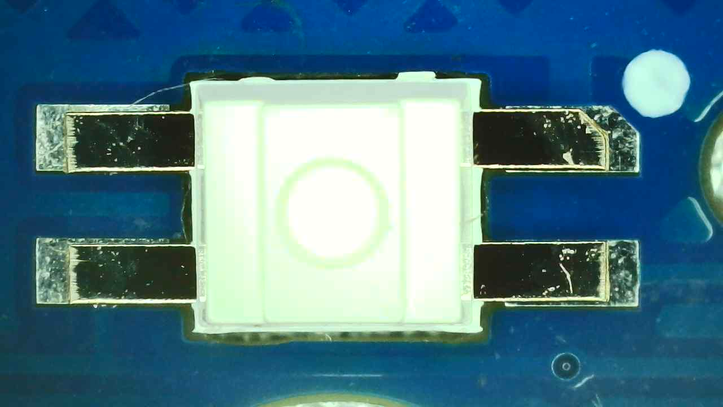
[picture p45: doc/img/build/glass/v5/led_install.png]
led_install


## MCU Board
>
> [!WARNING]
> BE CAREFUL AND USE EYE PROTECTION WHEN CUTTING PLASTIC AND PINS. When trimming, cover the area with your hand to reduce the risk of small pieces of plastic or metal pins flying off toward your face or monitor.

Solder the jumpers on the underside of the PCB near the controller pins.

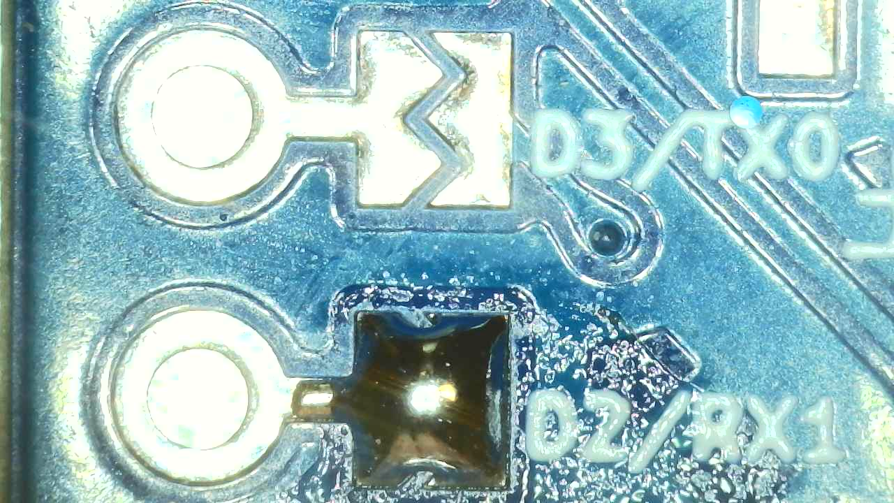
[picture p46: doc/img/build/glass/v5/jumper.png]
jumper

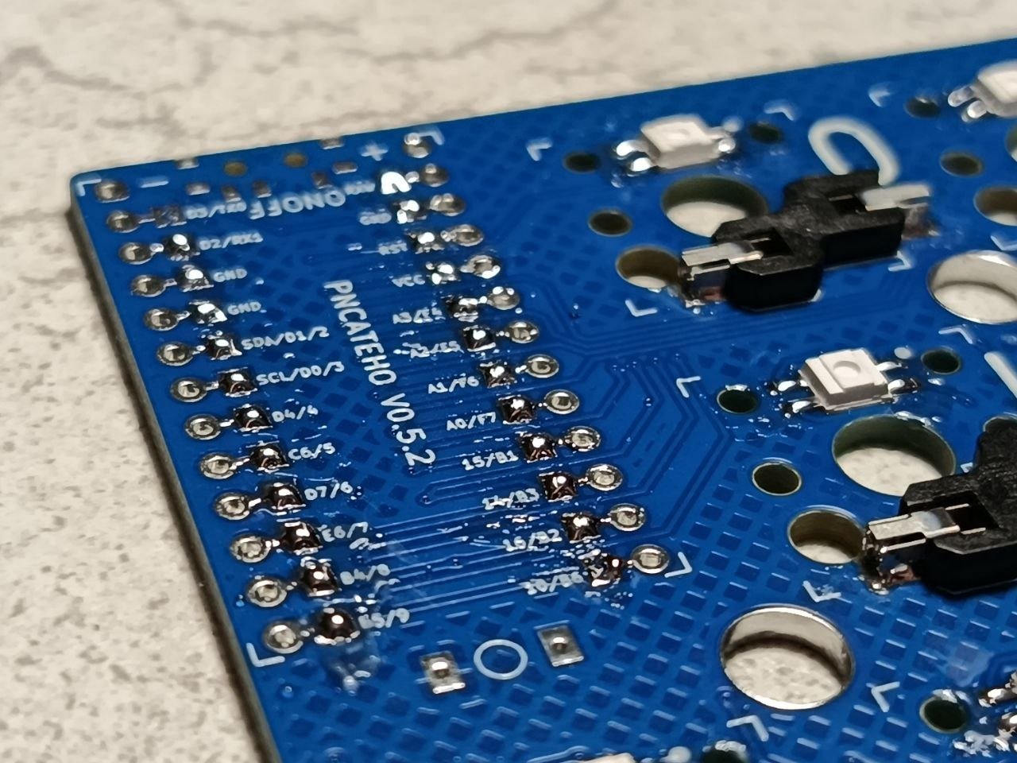
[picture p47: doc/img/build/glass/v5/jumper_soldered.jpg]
jumper_soldered


Then install the headers with the socket facing upward and solder the pin supports (also from the underside). Leave the space for the battery pins empty and do not install any pins there.

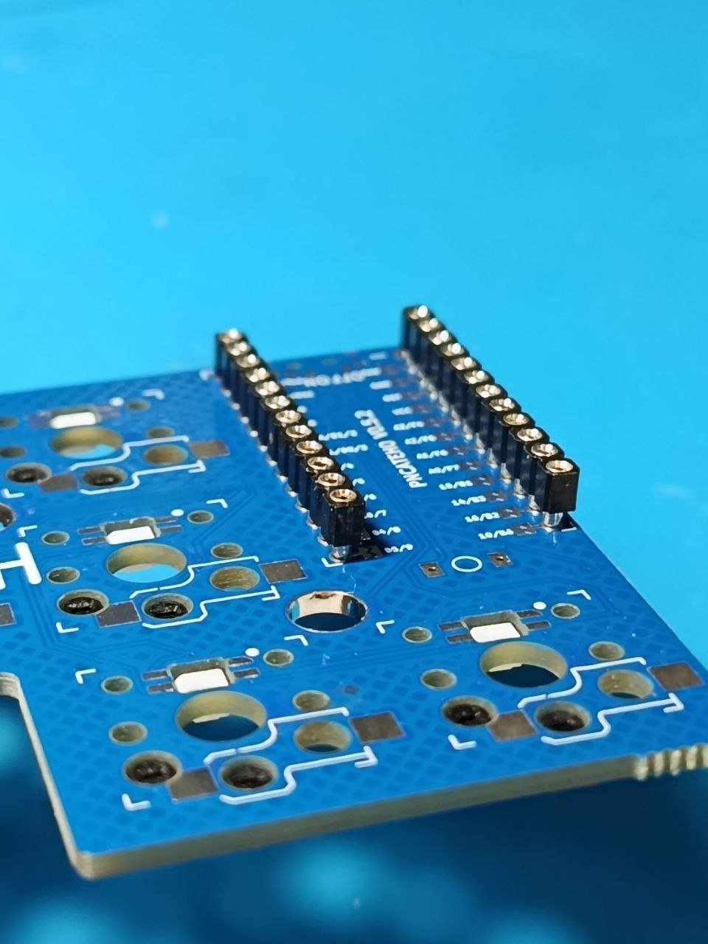
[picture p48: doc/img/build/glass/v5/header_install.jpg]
header_install

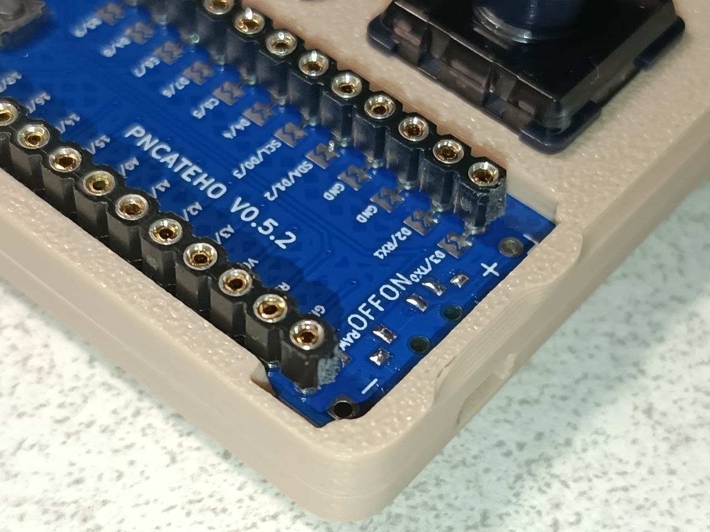
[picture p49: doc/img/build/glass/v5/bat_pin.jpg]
bat_pin


Install the controller on top of the sockets. Then take a piece of wire or an RGB pin and cut it flush with the controller [see details here](../doc/socket.md). After that, solder all the pins to the controller.

To check that all pins are properly soldered, try to gently remove the controller from the sockets using something long and straight to avoid bending the pins.

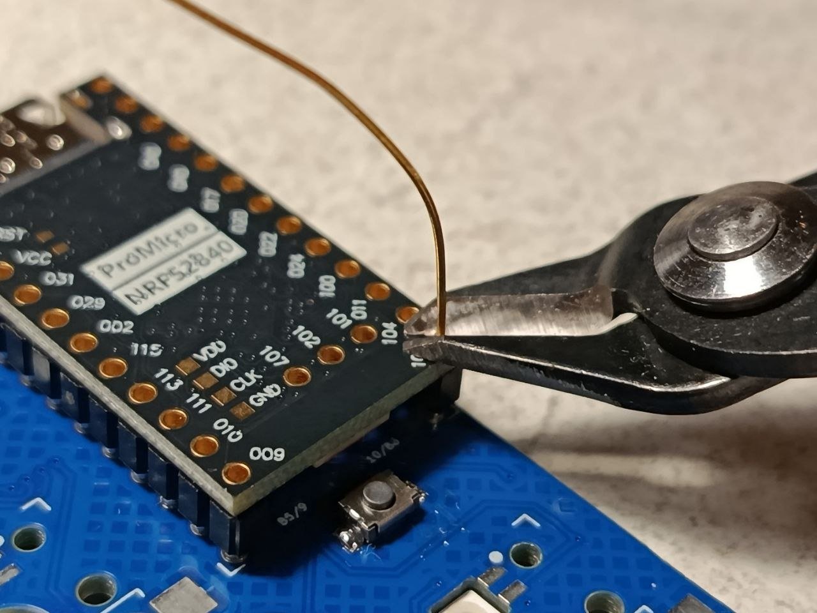
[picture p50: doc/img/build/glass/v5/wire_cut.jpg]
wire_cut

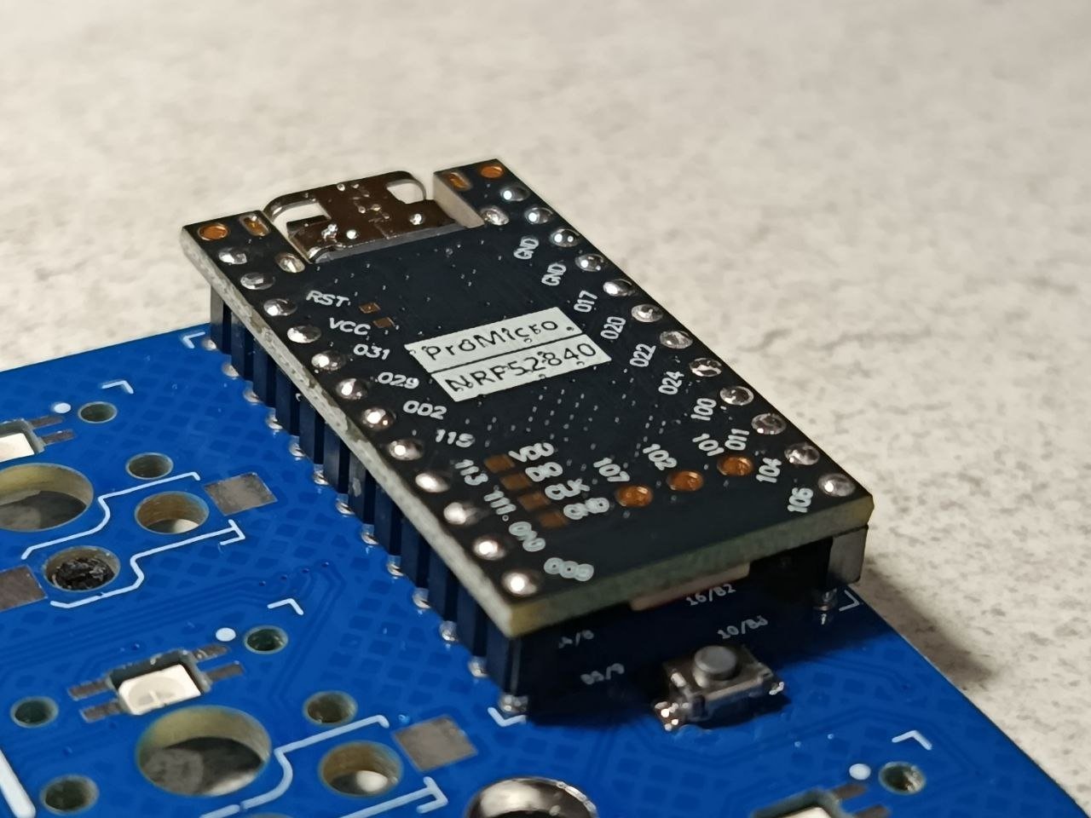
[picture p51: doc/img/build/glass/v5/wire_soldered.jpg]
wire_soldered


## Button and slider

Solder the reset button on the top side of the PCB, and the power switch on the bottom side.

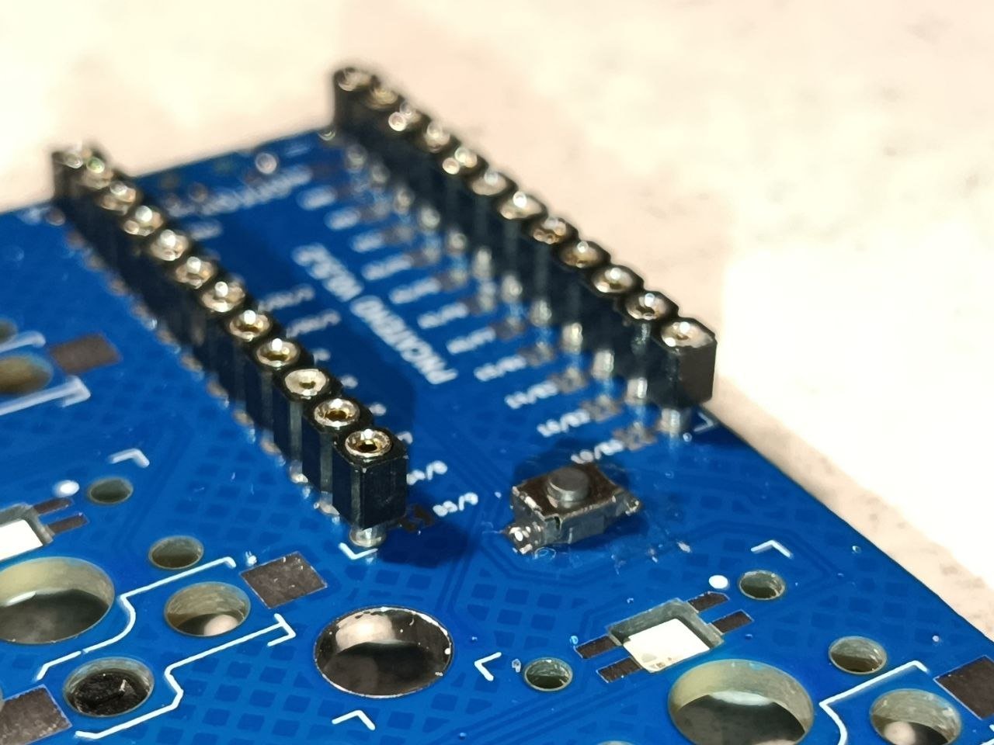
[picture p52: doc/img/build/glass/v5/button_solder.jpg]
button_solder

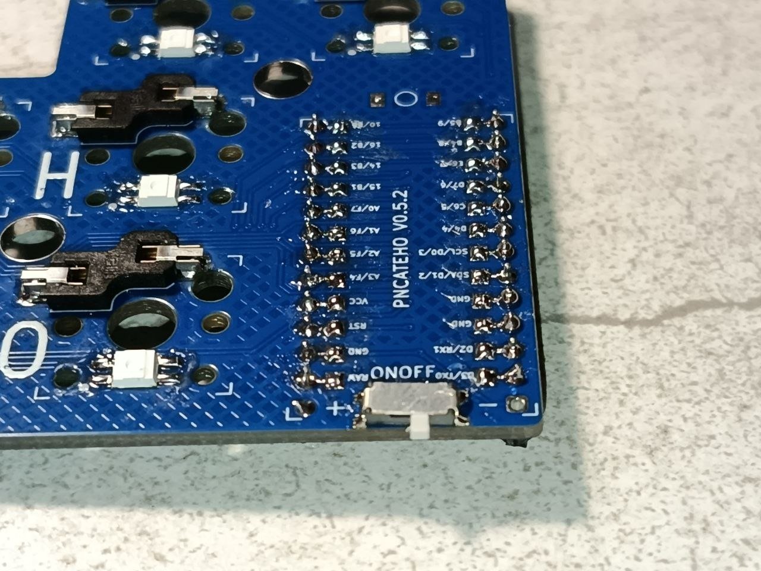
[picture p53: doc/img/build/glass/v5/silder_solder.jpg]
slider_solder


## Case

Insert the PCB into the case and install the actuators for the power switch and the reset button. Tighten the case with screws from the bottom, then attach the feet.

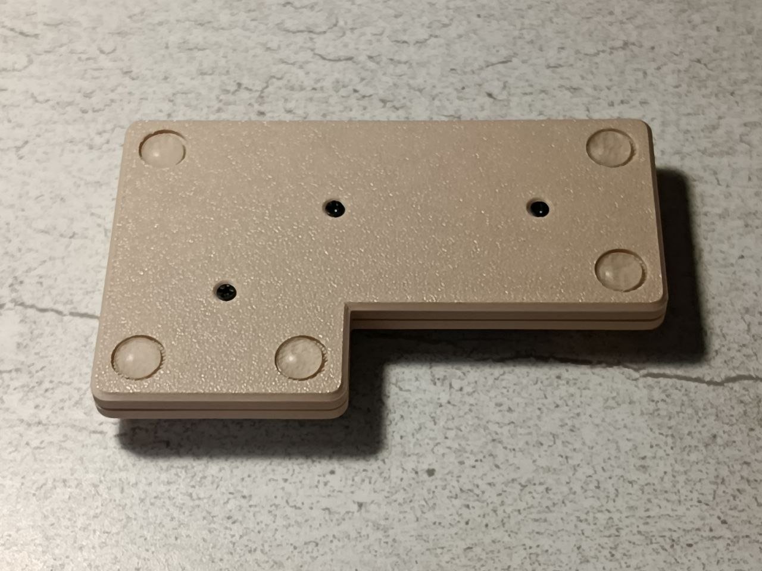
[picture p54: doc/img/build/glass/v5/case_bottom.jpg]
case_bottom


## Finish

Install the keycaps. Then connect the controller to your computer with a cable, press the reset button twice, and flash the firmware.

**Congratulations, you’ve assembled your РИСАТЕНО!**

build

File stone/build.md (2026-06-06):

## Led

The LEDs must be installed on the bottom side of the PCB with the light guide facing upward. Align the angled (cut) pin on the LED with the round pad on the board, and repeat this step for all LEDs. After that, simply solder them in place.

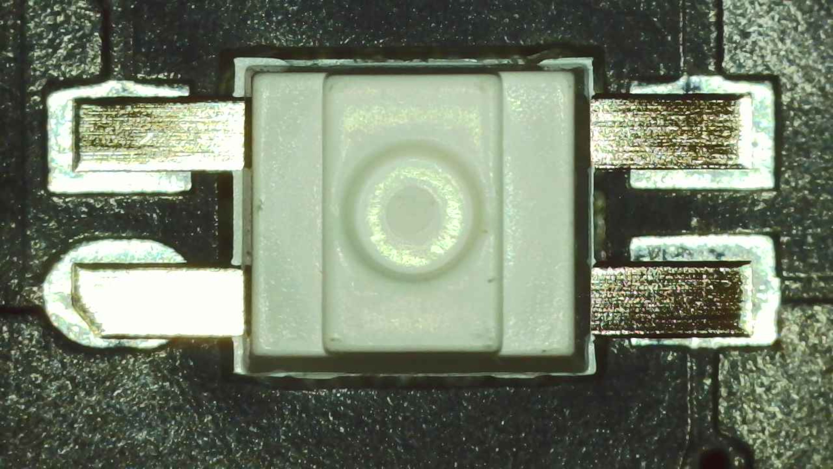
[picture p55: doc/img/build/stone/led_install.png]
led_instal

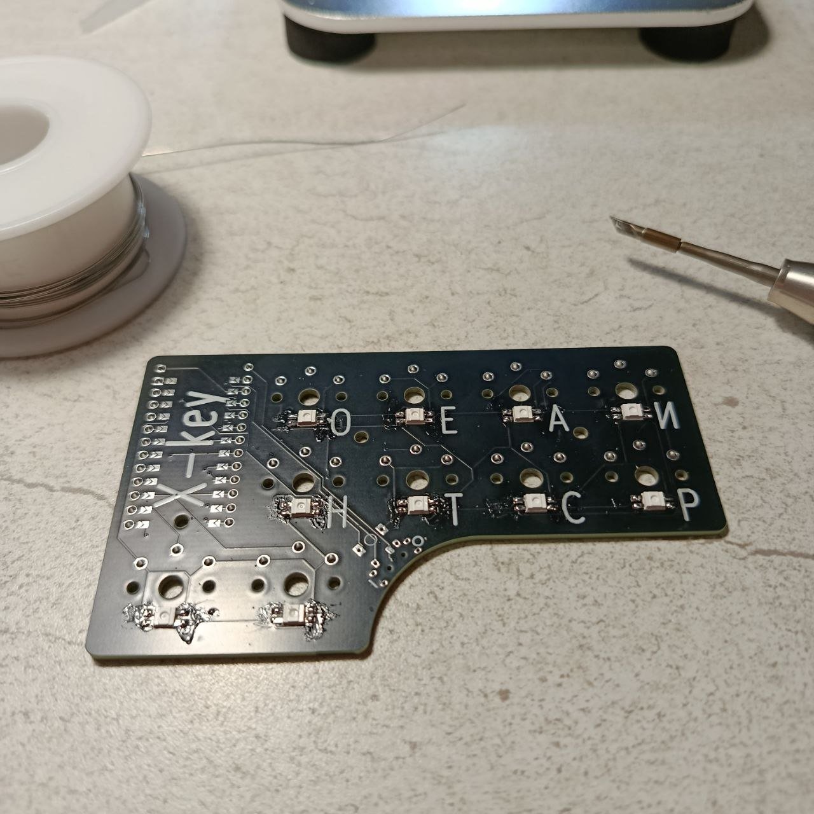
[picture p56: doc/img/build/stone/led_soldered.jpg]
led_soldered


## MCU Board
>
> [!WARNING]
> BE CAREFUL AND USE EYE PROTECTION WHEN CUTTING PLASTIC AND PINS. When trimming, cover the area with your hand to reduce the risk of small pieces of plastic or metal pins flying off toward your face or monitor.

Solder the jumpers on the underside of the PCB near the controller pins.

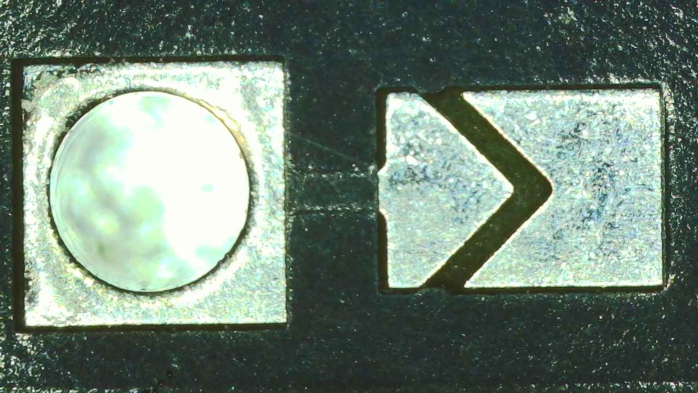
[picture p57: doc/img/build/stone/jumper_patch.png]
jumper_patch.

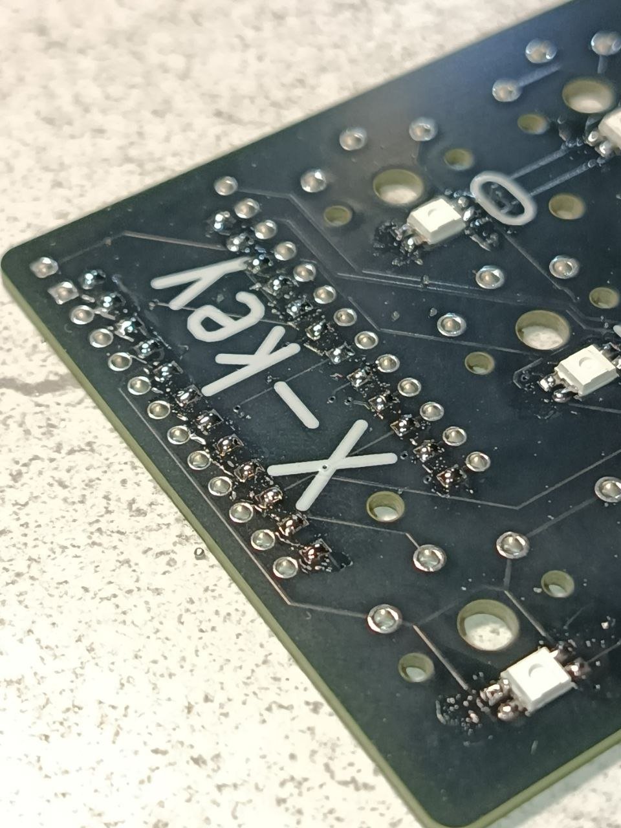
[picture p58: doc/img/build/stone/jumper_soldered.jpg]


Then install the headers with the socket facing upward and solder the pin supports (also from the underside). Leave the space for the battery pins empty and do not install any pins there.

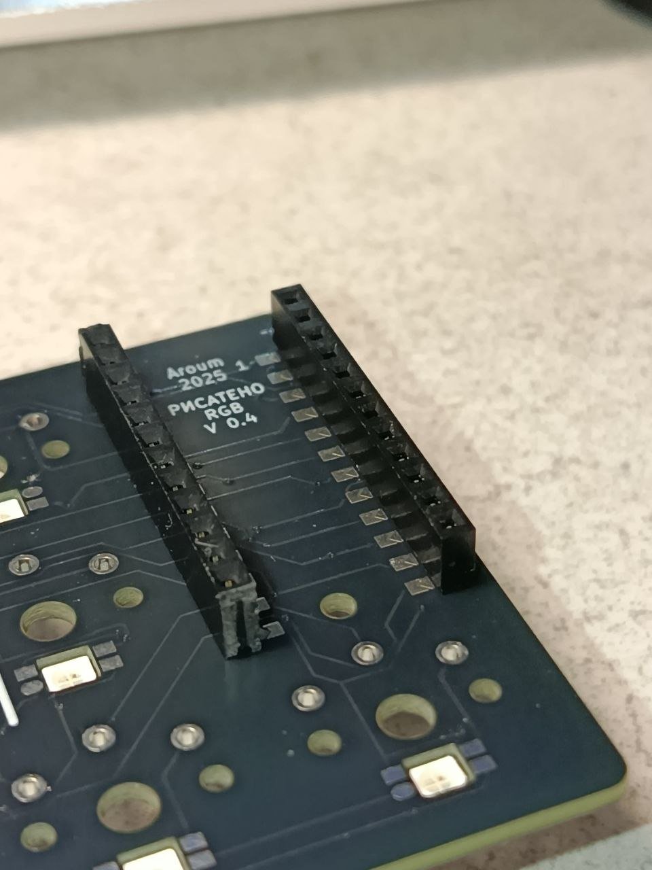
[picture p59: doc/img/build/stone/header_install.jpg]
header_install

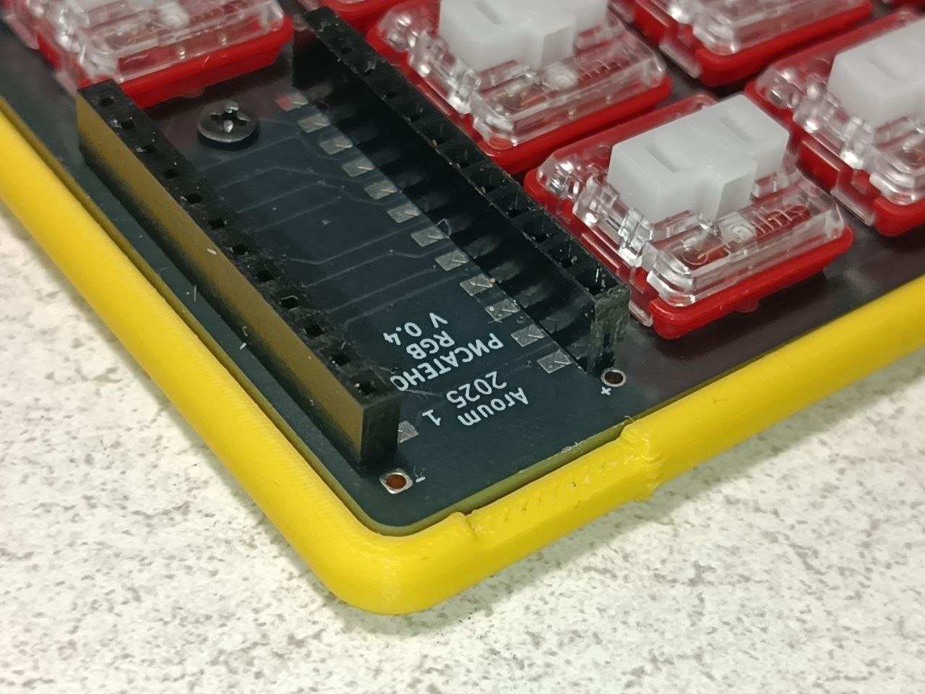
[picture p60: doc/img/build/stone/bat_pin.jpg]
bat_pin


Next, take a strip of pins and remove them from the plastic. Install the controller and insert the separated pins into the headers. Using side cutters, trim the pins flush with the controller, then solder them in place. [see details here](../doc/socket.md)

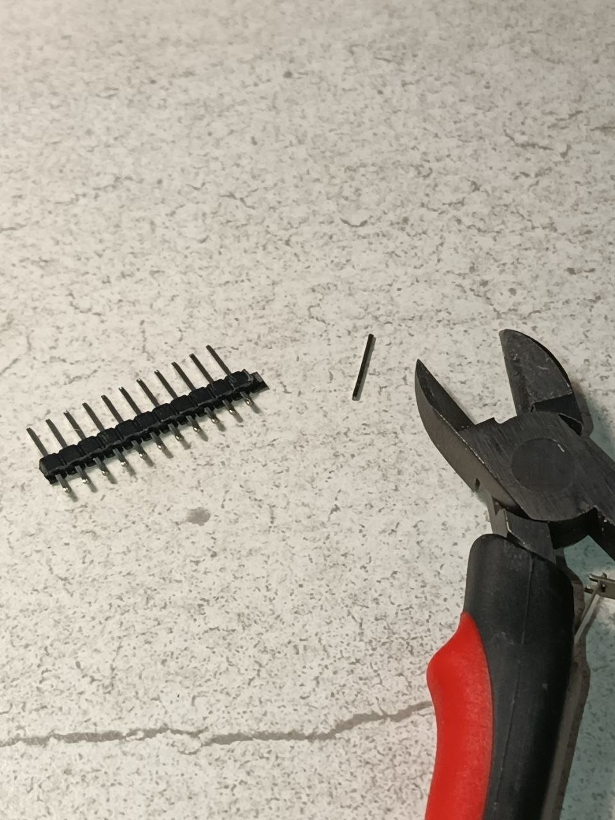
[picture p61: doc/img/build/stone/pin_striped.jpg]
pin_striped

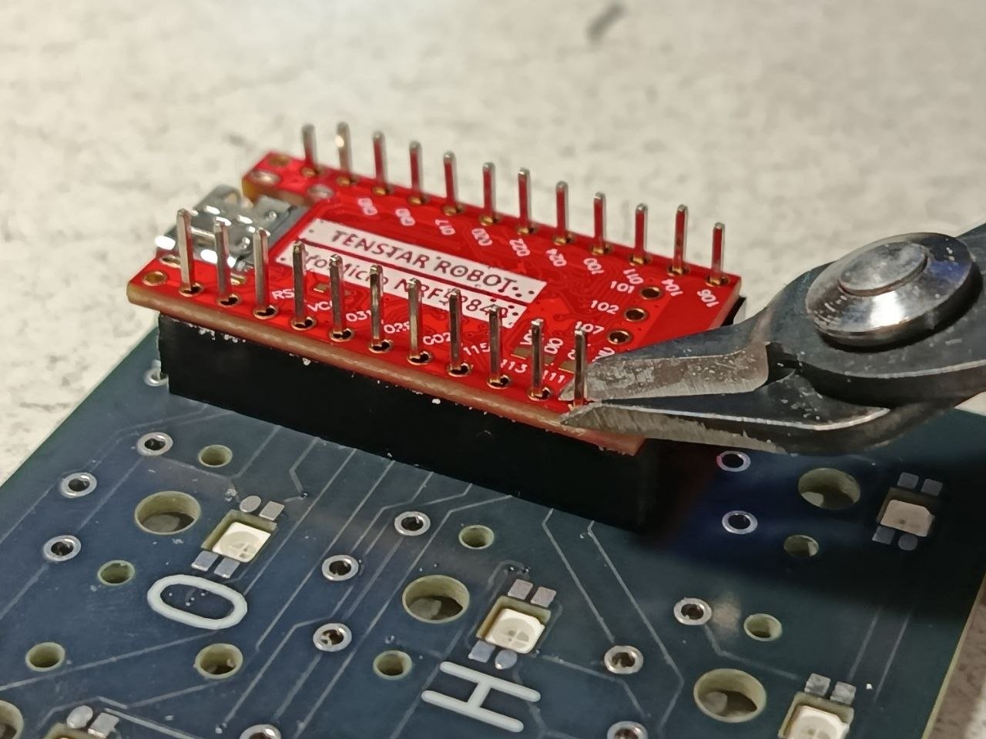
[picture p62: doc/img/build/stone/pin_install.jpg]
pin_install

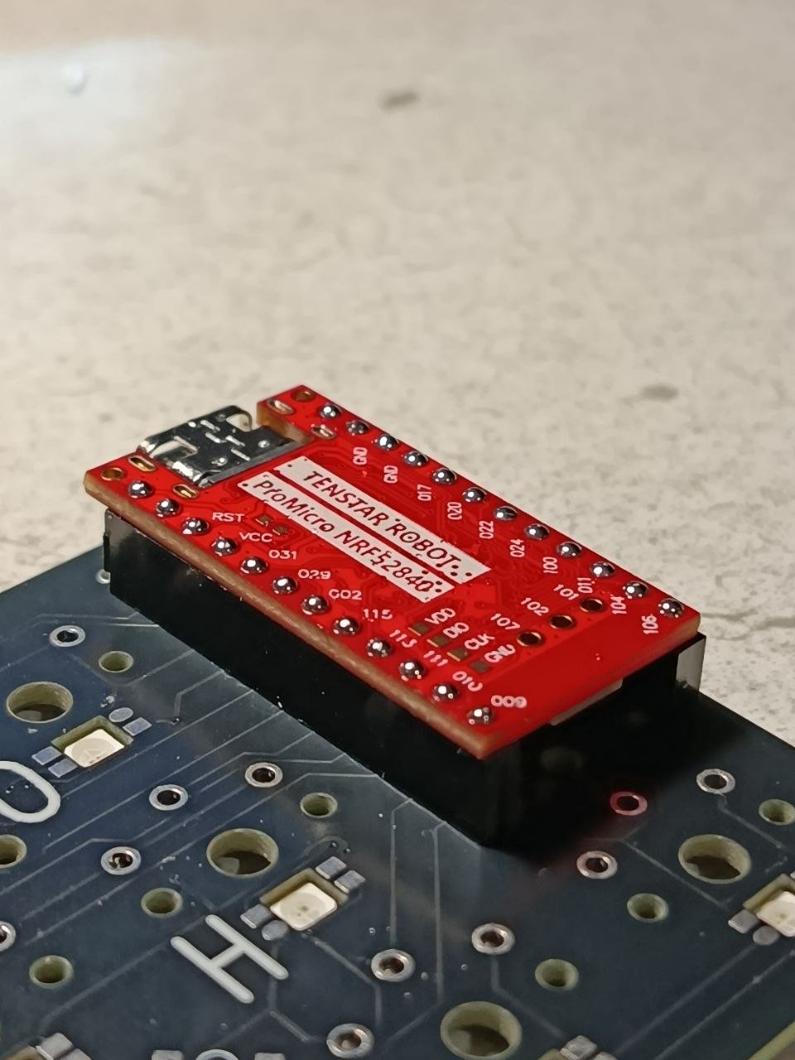
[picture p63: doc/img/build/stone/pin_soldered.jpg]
pin_soldered


## Button and slider

Install the reset button and the power switch, then simply solder them in place. For convenience, solder the switch first and then the button.

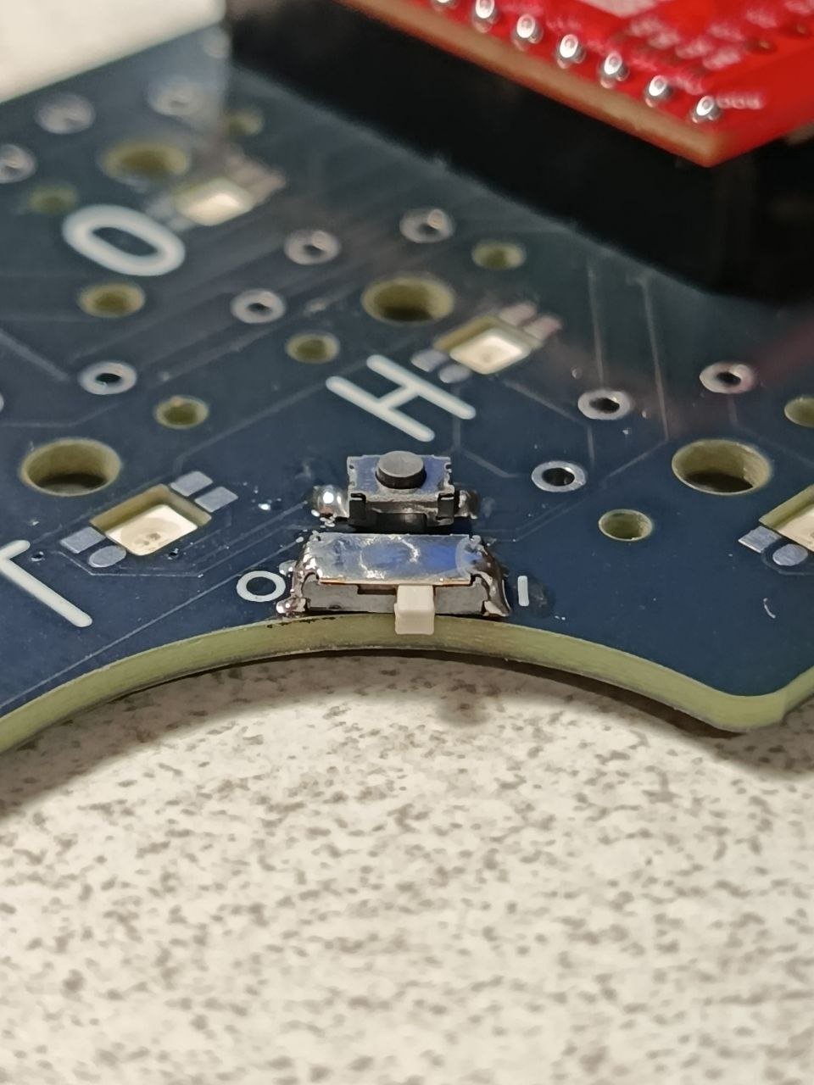
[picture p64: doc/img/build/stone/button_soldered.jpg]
button_soldered


## Switch

Install the switches on the top side and solder them from the underside of the PCB.

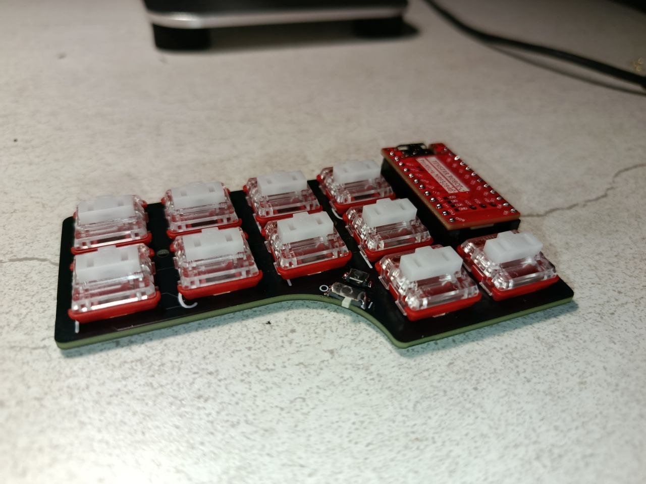
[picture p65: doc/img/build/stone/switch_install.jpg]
switch_install


## Case

Insert the magnets into the case, then place the nuts from the opposite side. Install the PCB and tighten the screws.

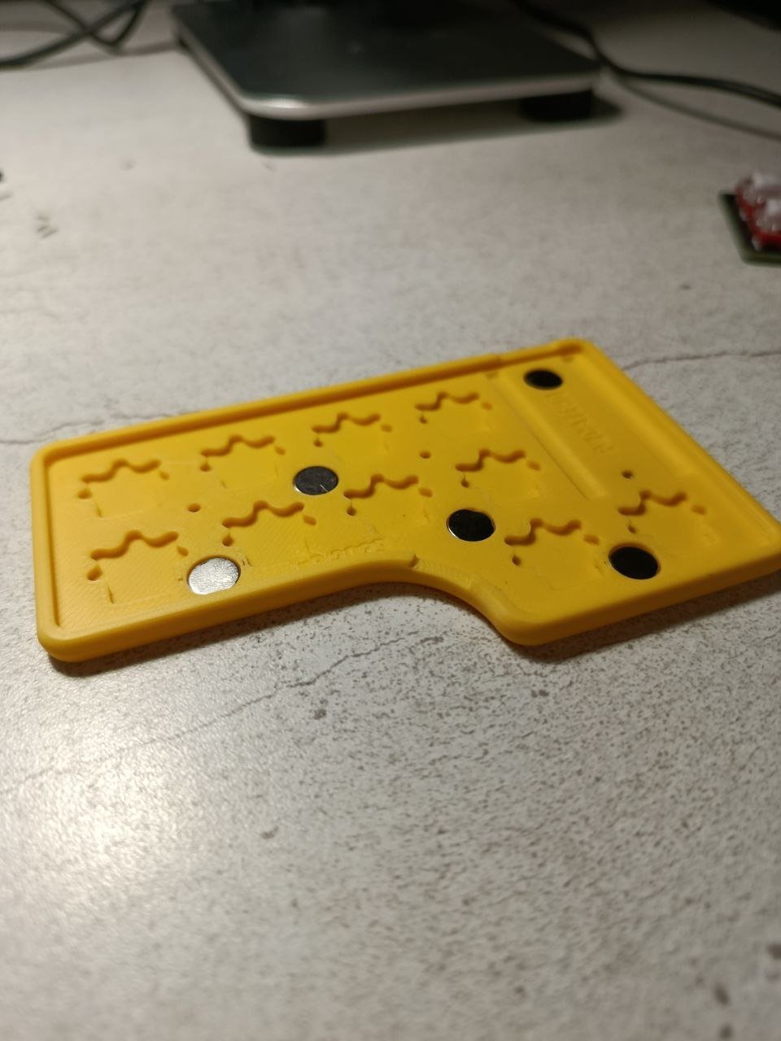
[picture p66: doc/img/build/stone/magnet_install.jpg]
magnet_install

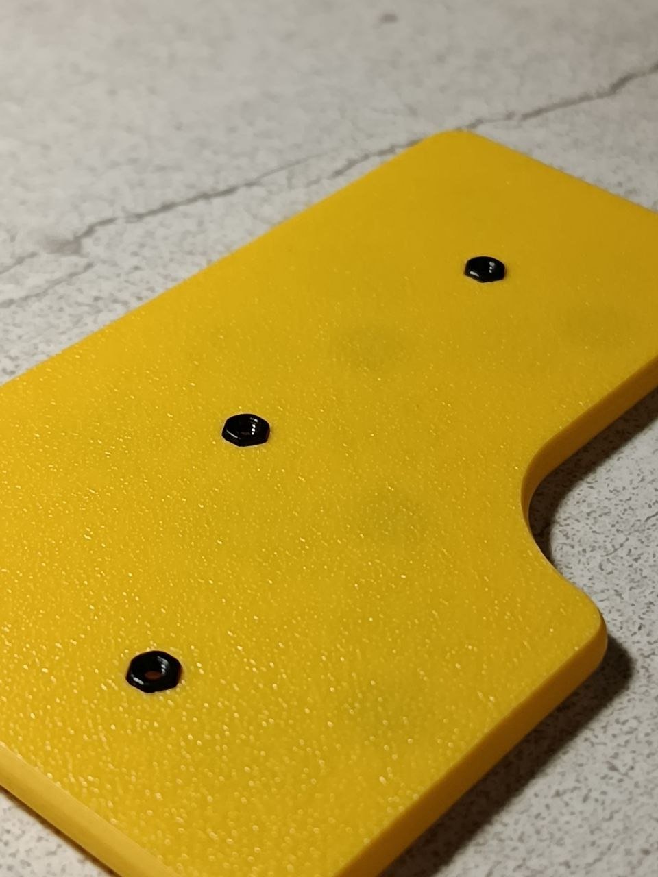
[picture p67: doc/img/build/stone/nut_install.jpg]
nut_install

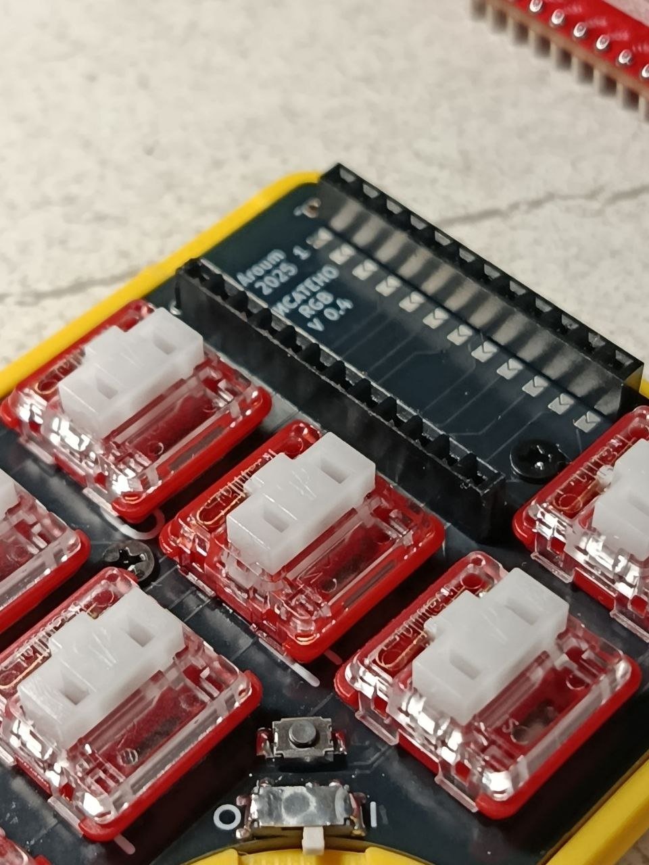
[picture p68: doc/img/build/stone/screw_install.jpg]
screw_install


## Finish

Install the keycaps. Then connect the controller to your computer with a cable, press the reset button twice, and flash the firmware.

**Congratulations, you’ve assembled your РИСАТЕНО!**

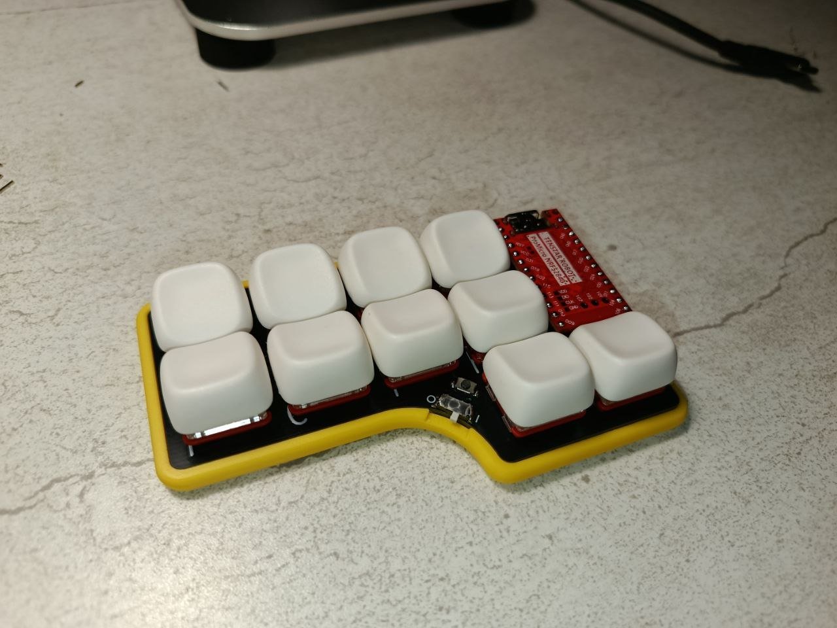
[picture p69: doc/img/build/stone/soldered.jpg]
soldered


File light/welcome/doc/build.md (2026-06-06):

## Tool

For assembly, you will need a soldering iron, flux, solder paste, tweezers, and either a hot air gun or a hot plate. For convenience, it is also recommended to have a microscope to check for solder bridges and a stencil for applying the paste.

## IBOM

<p align="center">
  <a href="https://htmlpreview.github.io/?https://github.com/inpudiy/PNCATEHO/blob/master/light/welcome/doc/ibom.html" style="text-decoration: none;">IBOM |</a>
  <a href="doc/schematic.pdf" style="text-decoration: none;"> Schematic PDF</a>
</p>

Using the links above, go to the page with the interactive BOM. When you hover over a component or a footprint, a pair will be highlighted the component and the location where it needs to be installed. For resistors, capacitors, and fuses, polarity does not matter. For all other components, use the markings on both the component and the PCB, matching them accordingly.

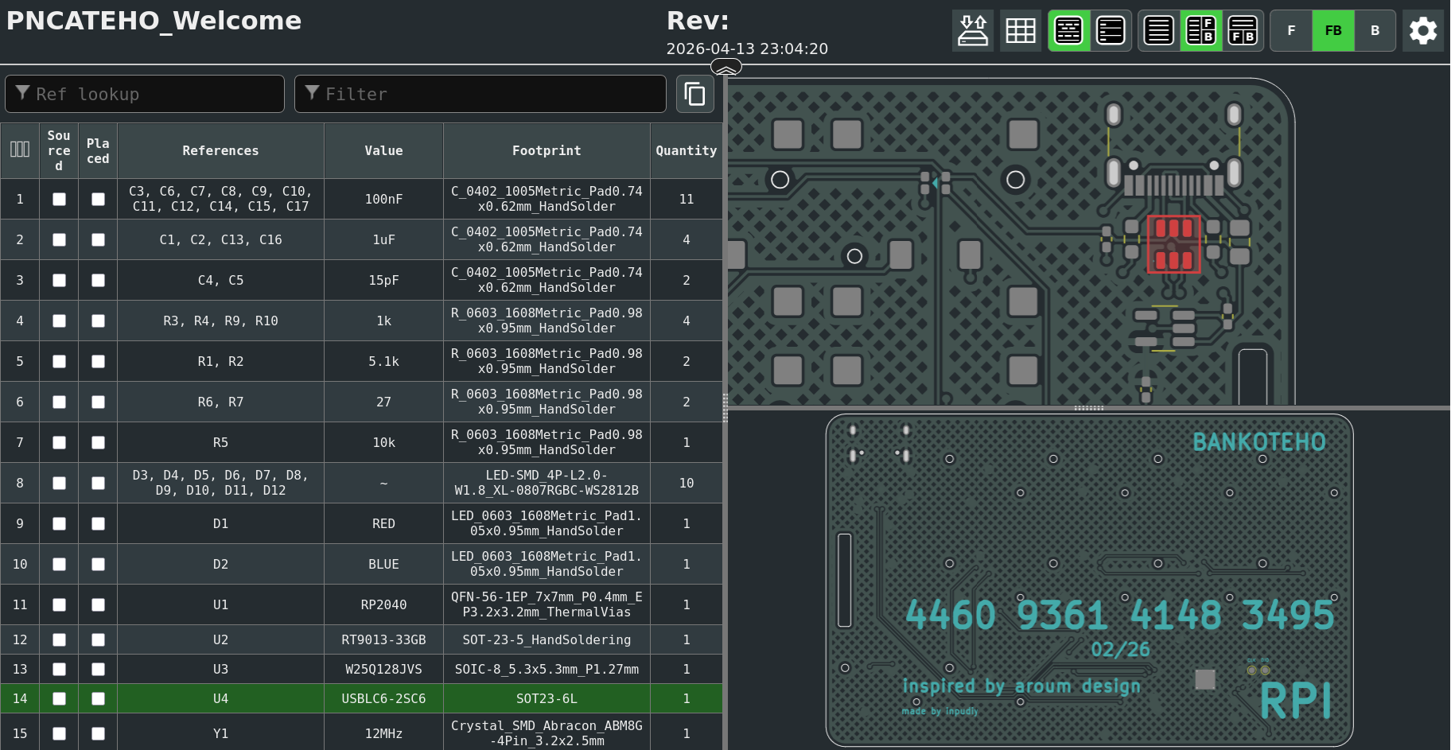
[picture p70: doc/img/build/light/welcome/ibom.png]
ibom


## Led

Find the side of the LED marked in green, and rotate that side inward toward the bracket on the PCB, as shown in the photo.

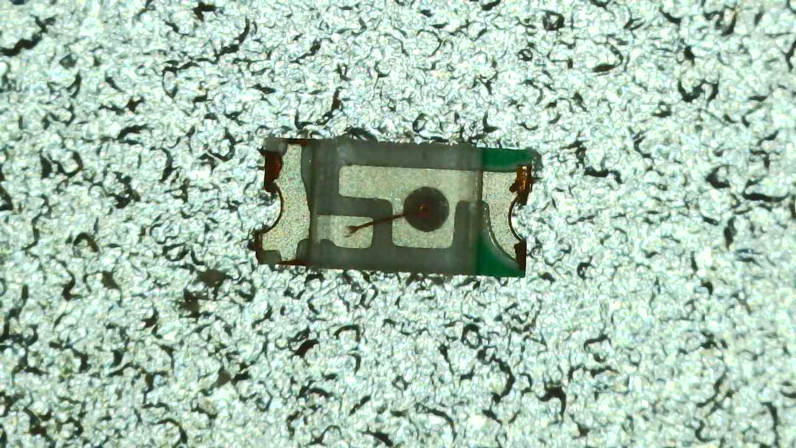
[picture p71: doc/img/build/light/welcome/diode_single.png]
diode

diode

## Flash and USBLC6-2SC6

There are small, barely noticeable dots in the corner of both components. Install them so that these dots align with the markings on the PCB.

diode
diode

## Crystal (Y1)

On the underside of the crystal oscillator, there is a pin with a cut corner. When placing it with the pins facing down, this corner should align with the marked corner on the PCB, as shown in the photo. Use either a hot air rework station or a hot plate.

quartz_single
quartz_pcb

## RP2040

Tin the pads for installing the controller with a small amount of solder paste, and do the same with the controller itself. Make sure you’ve also tinned the side pins of the controller, and that there is only a minimal amount of solder on the central pad of both the PCB and the controller. If you apply too much paste in the center, the controller will sit too high above the board.

Then apply flux and place the controller, aligning the dot on the controller with the marking on the PCB. Personally, I pre-tin the contacts with a soldering iron, then place the controller using a hot plate and align it during the soldering process.

After soldering, remove the flux and inspect the side pins of the controller. For extra assurance, you can reapply flux and run a soldering iron with a small amount of solder paste along the edges of the controller. If you notice any obvious misalignment, reheat the solder joints and carefully adjust the component with tweezers.

rp_foot
rp_bottom
rp_side
rp_top_pcb
rp_side_pcb

## TYPE-C-31-M-12

Apply solder paste or solder with flux and go over the pads. Make sure that no contacts are shorted together. Also, be sure to flip the board and solder the through-holes the solder should flow fully inside and bond with the connector housing; otherwise, it can be easily broken off.

rp_top_pcb
rp_side_pcb

## Flashing

> [!WARNING]  
> Before connecting the board to your computer, visually inspect it: make sure all components are present, check for the absence of solder bridges between pins, and remove any excess solder, flux, or solder paste.

At the stage where everything is installed except the backlight, switches, connector, and control buttons, it’s a good time to flash the firmware so that further work is easier.

When you plug in the cable, a good sign is that the red 3.3V LED turns on. On first connection, the board should appear as a USB flash drive—copy the UF2 firmware file onto it.

After flashing, reconnect the board and check whether it is detected using Device Manager or lsusb.

If the board is not detected when connected, or stops being detected after flashing, return to the visual inspection stage. In 99.9% of cases, the issue is due to an incorrect component, wrong polarity, or poor connections between the pins and the PCB pads.

Start by applying flux everywhere and go over all components with a soldering iron and solder (or solder paste).

pcb_power
pcb_flash
pcb_mcu

## WS2812B

> [!WARNING]  
> Disconnect the power supply before starting to solder the backlight.

After flashing, it’s time to install the backlight. On the diode, you’ll find an edge marked in green, and on the PCB there is a triangle indicating direction. Install the diode so that the green-marked edge faces the same direction as the triangle, as shown in the photo below.

Before soldering, tin the pads and apply flux. Heat the area using a hot air station or hot plate, then place the diode. Be careful using a soldering iron or tweezers can easily damage it, so handle it with care.

2020_single
2020_foot
2020_pcb

The data line of the LEDs is shown in the image below. If any part of the LEDs is not working, try re-soldering the first non-functioning LED in the chain.

2020_path

## CPG1316S01D02-01

Before soldering the switches, it is recommended to check everything else first. Connect the keyboard and, using tweezers, short the switch pins one by one to test them.

If each pin registers a key press correctly when shorted, install the switches as shown in the photo and solder them in place using a hot air station and solder paste.

> [!WARNING]  
> Before installing the keycaps, make sure all switches are functioning properly, as they are almost impossible to remove without damaging the switch.

switch

## JST and button (optional)

For quick flashing and access to 8 GPIO pins, you can install a JST connector and buttons.

jst

## Congratulations

Congratulations you’ve assembled your РИСАТЕНО Welcome!

welcome

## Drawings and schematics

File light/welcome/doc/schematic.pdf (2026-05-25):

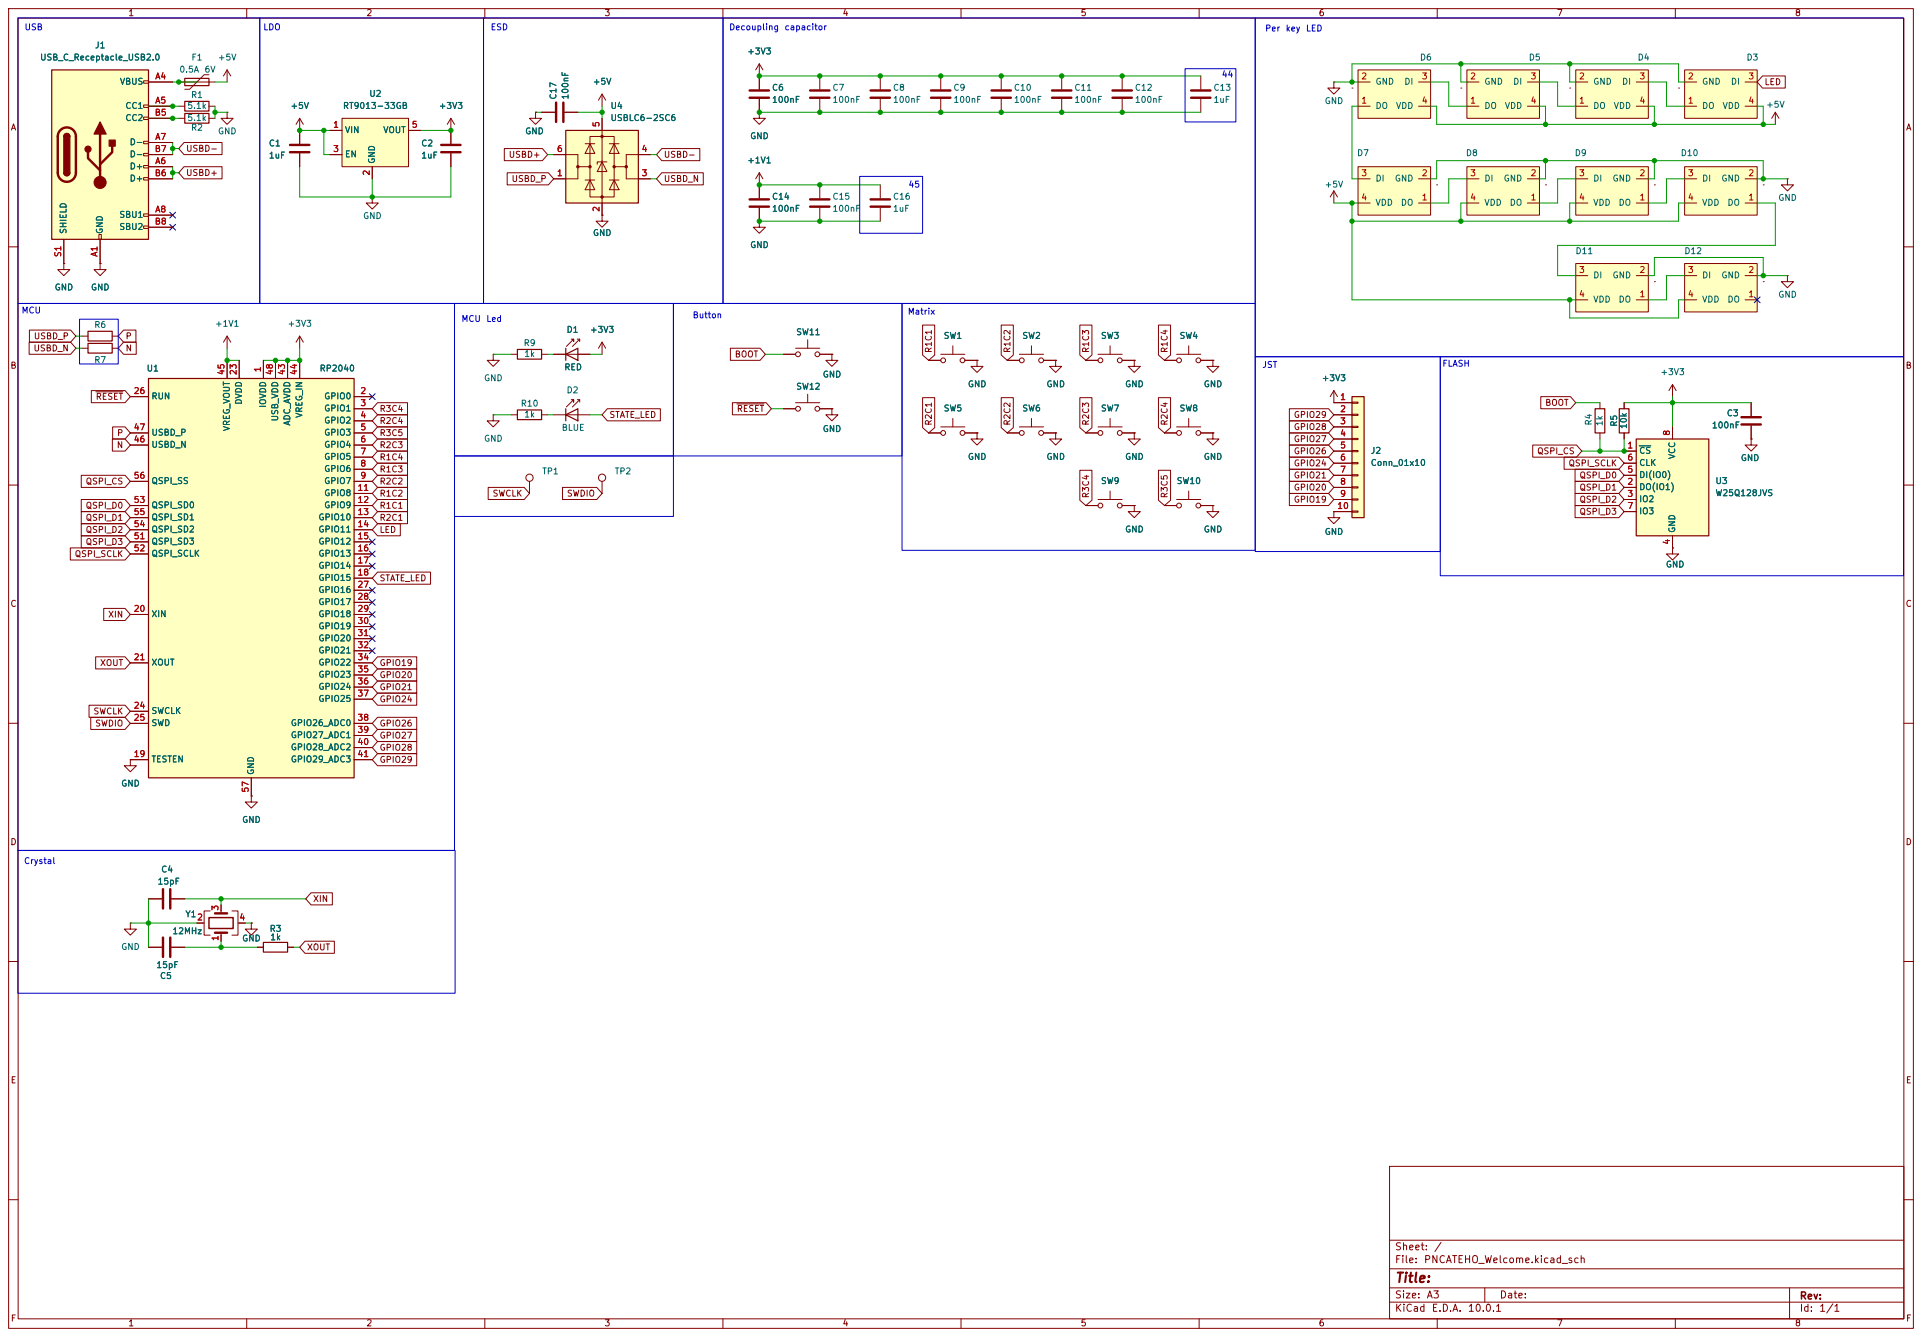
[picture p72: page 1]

JST MCU Led R3 GND 1k C4

Size: A3 | Rev: | F Date:
KiCad E.D.A. 10.0.1 | Id: 1/1

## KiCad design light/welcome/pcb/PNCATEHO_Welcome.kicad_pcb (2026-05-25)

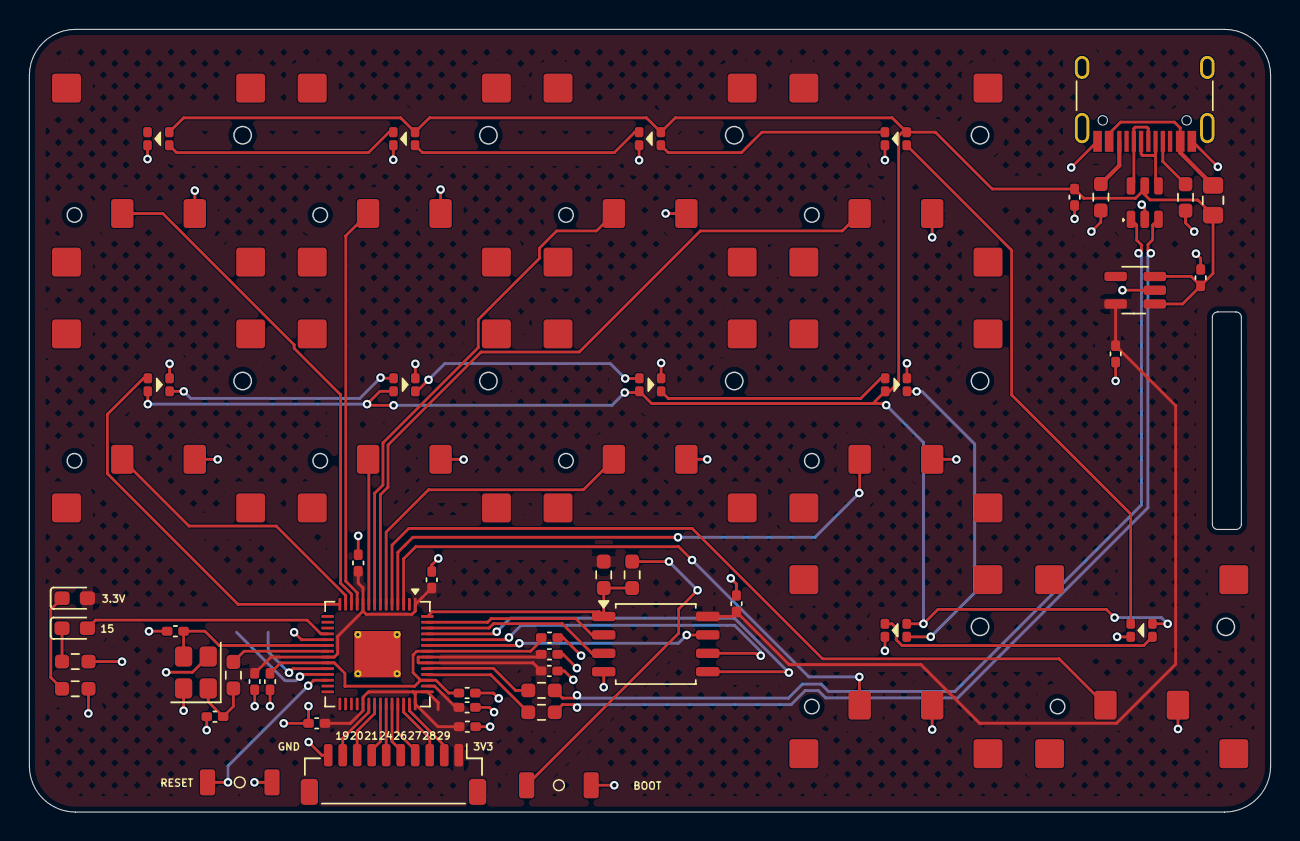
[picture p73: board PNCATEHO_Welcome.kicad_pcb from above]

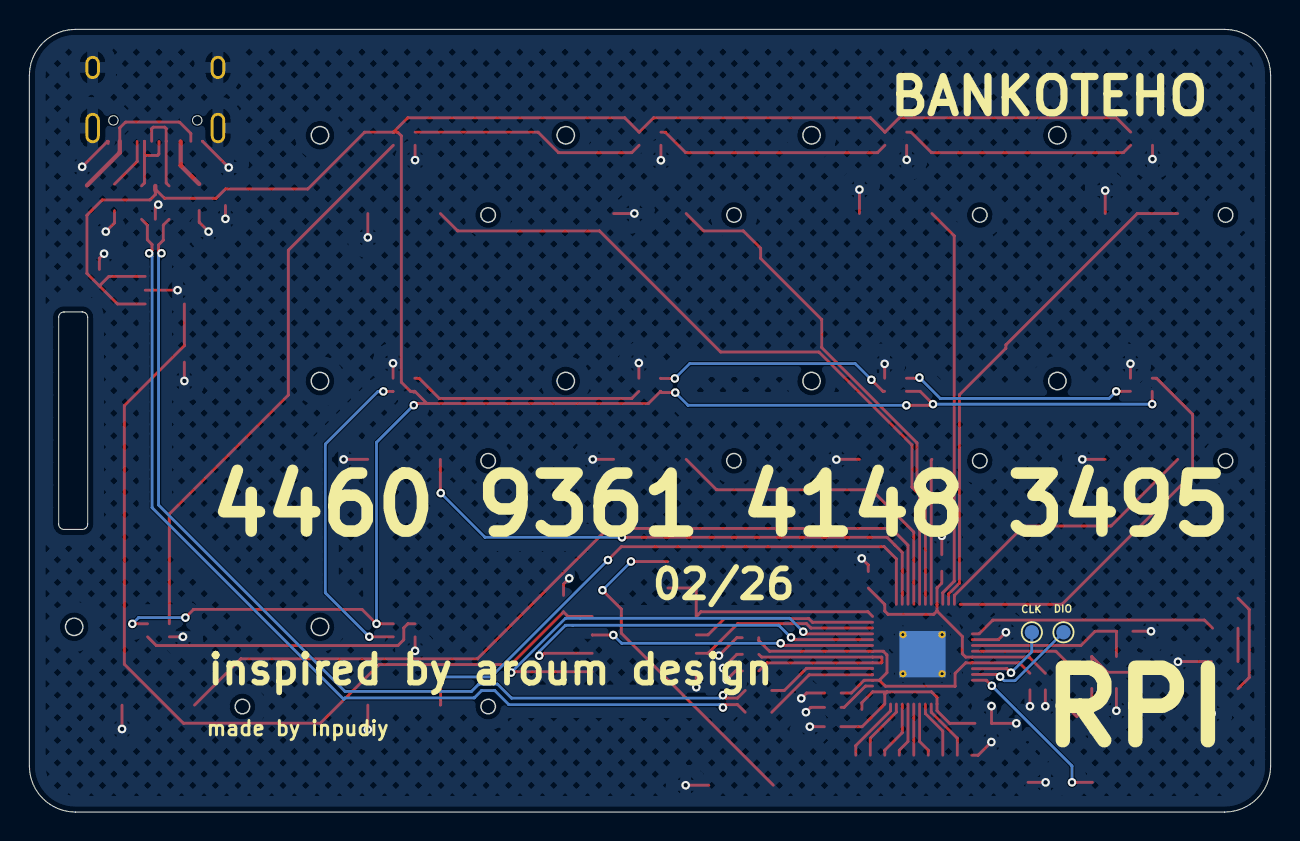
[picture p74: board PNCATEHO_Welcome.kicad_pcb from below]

Board: 2 copper layers, 85.6 x 54.0 mm, 60 parts (2 on the bottom side), 57 nets.

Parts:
C1, C2, C13, C16: 1uF; C_0402_1005Metric_Pad0.74x0.62mm_HandSolder
C3, C6, C7, C8, C9, C10, C11, C12, C14, C15, C17: 100nF; C_0402_1005Metric_Pad0.74x0.62mm_HandSolder
C4, C5: 15pF; C_0402_1005Metric_Pad0.74x0.62mm_HandSolder
D1: RED; LED_0603_1608Metric_Pad1.05x0.95mm_HandSolder
D2: BLUE; LED_0603_1608Metric_Pad1.05x0.95mm_HandSolder
D3, D4, D5, D6, D7, D8, D9, D10, D11, D12: LED-SMD_4P-L2.0-W1.8_XL-0807RGBC-WS2812B
F1: 0.5А 6V; Fuse_0805_2012Metric_Pad1.15x1.40mm_HandSolder
J1: USB_C_Receptacle_USB2.0; USB_C_Receptacle_HRO_TYPE-C-31-M-12
J2: Conn_01x10; JST_SH_BM10B-SRSS-TB_1x10-1MP_P1.00mm_Vertical
R1, R2: 5.1k; R_0603_1608Metric_Pad0.98x0.95mm_HandSolder
R3, R4, R9, R10: 1k; R_0603_1608Metric_Pad0.98x0.95mm_HandSolder
R5: 10k; R_0603_1608Metric_Pad0.98x0.95mm_HandSolder
R6, R7: 27; R_0603_1608Metric_Pad0.98x0.95mm_HandSolder
SW1, SW2, SW3, SW4, SW5, SW6, SW7, SW8, SW9, SW10: CPG1316S01D02-01
SW11: Boot; TS342A2P
SW12: Reset; TS342A2P
TP1, TP2: TestPoint; TestPoint_Pad_D1.0mm
U1: RP2040; QFN-56-1EP_7x7mm_P0.4mm_EP3.2x3.2mm_ThermalVias
U2: RT9013-33GB; SOT-23-5_HandSoldering
U3: W25Q128JVS; SOIC-8_5.3x5.3mm_P1.27mm
U4: USBLC6-2SC6; SOT23-6L
Y1: 12MHz; Crystal_SMD_Abracon_ABM8G-4Pin_3.2x2.5mm

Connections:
+1V1: C14.1, C15.1, C16.1, U1.23 (DVDD), U1.45 (VREG_VOUT), U1.50 (DVDD)
+3V3: C2.1, C3.1, C6.1, C7.1, C8.1, C9.1, C10.1, C11.1, C12.1, C13.1, D1.2 (A), J2.1, R5.2, U1.1 (IOVDD), U1.10 (IOVDD), U1.22 (IOVDD), U1.33 (IOVDD), U1.42 (IOVDD), U1.43 (ADC_AVDD), U1.44 (VREG_IN), U1.48 (USB_VDD), U1.49 (IOVDD), U2.5 (VOUT), U3.8 (VCC)
+5V: C1.1, C17.2, D3.4 (VDD), D4.4 (VDD), D5.4 (VDD), D6.4 (VDD), D7.4 (VDD), D8.4 (VDD), D9.4 (VDD), D10.4 (VDD), D11.4 (VDD), D12.4 (VDD), F1.2, U2.1 (VIN), U2.3 (EN), U4.5 (VBUS)
BOOT: R4.2, SW11.2
GND: C1.2, C2.2, C3.2, C4.2, C5.2, C6.2, C7.2, C8.2, C9.2, C10.2, C11.2, C12.2, C13.2, C14.2, C15.2, C16.2, C17.1, D3.2 (GND), D4.2 (GND), D5.2 (GND), D6.2 (GND), D7.2 (GND), D8.2 (GND), D9.2 (GND), D10.2 (GND), D11.2 (GND), D12.2 (GND), J1.A1 (GND), J1.A12 (GND), J1.B1 (GND), J1.B12 (GND), J1.S1 (SHIELD), J2.10, R1.2, R2.2, R9.1, R10.1, SW1.2, SW2.2, SW3.2, SW4.2, SW5.2, SW6.2, SW7.2, SW8.2, SW9.2, SW10.2, SW11.1, SW12.1, U1.19 (TESTEN), U1.57 (GND), U2.2 (GND), U3.4 (GND), U4.2 (GND), Y1.2, Y1.4
GPIO19: J2.9, U1.34 (GPIO22)
GPIO20: J2.8, U1.35 (GPIO23)
GPIO21: J2.7, U1.36 (GPIO24)
GPIO24: J2.6, U1.37 (GPIO25)
GPIO26: J2.5, U1.38 (GPIO26_ADC0)
GPIO27: J2.4, U1.39 (GPIO27_ADC1)
GPIO28: J2.3, U1.40 (GPIO28_ADC2)
GPIO29: J2.2, U1.41 (GPIO29_ADC3)
LED: D3.3 (DI), U1.14 (GPIO11)
N: R7.2, U1.46 (USBD_N)
unnamed: C5.1, R3.1, Y1.1
unnamed: D1.1 (K), R9.2
unnamed: D2.1 (K), R10.2
unnamed: D3.1 (DO), D4.3 (DI)
unnamed: D4.1 (DO), D5.3 (DI)
unnamed: D5.1 (DO), D6.3 (DI)
unnamed: D6.1 (DO), D7.3 (DI)
unnamed: D7.1 (DO), D8.3 (DI)
unnamed: D8.1 (DO), D9.3 (DI)
unnamed: D9.1 (DO), D10.3 (DI)
unnamed: D10.1 (DO), D11.3 (DI)
unnamed: D11.1 (DO), D12.3 (DI)
unnamed: F1.1, J1.A4 (VBUS), J1.A9 (VBUS), J1.B4 (VBUS), J1.B9 (VBUS)
unnamed: J1.A5 (CC1), R1.1
unnamed: J1.B5 (CC2), R2.1
P: R6.2, U1.47 (USBD_P)
QSPI_CS: R4.1, R5.1, U1.56 (QSPI_SS), U3.1 (~CS)
QSPI_D0: U1.53 (QSPI_SD0), U3.5 (DI(IO0))
QSPI_D1: U1.55 (QSPI_SD1), U3.2 (DO(IO1))
QSPI_D2: U1.54 (QSPI_SD2), U3.3 (IO2)
QSPI_D3: U1.51 (QSPI_SD3), U3.7 (IO3)
QSPI_SCLK: U1.52 (QSPI_SCLK), U3.6 (CLK)
R1C1: SW1.1, U1.12 (GPIO9)
R1C2: SW2.1, U1.11 (GPIO8)
R1C3: SW3.1, U1.8 (GPIO6)
R1C4: SW4.1, U1.7 (GPIO5)
R2C1: SW5.1, U1.13 (GPIO10)
R2C2: SW6.1, U1.9 (GPIO7)
R2C3: SW7.1, U1.6 (GPIO4)
R2C4: SW8.1, U1.4 (GPIO2)
R3C4: SW9.1, U1.3 (GPIO1)
R3C5: SW10.1, U1.5 (GPIO3)
STATE_LED: D2.2 (A), U1.18 (GPIO15)
SWCLK: TP1.1 (1_1), U1.24 (SWCLK)
SWDIO: TP2.1 (1_1), U1.25 (SWD)
USBD+: J1.A6 (D+), J1.B6 (D+), U4.6 (I/O1)
USBD-: J1.A7 (D-), J1.B7 (D-), U4.4 (I/O2)
USBD_N: R7.1, U4.3 (I/O2)
USBD_P: R6.1, U4.1 (I/O1)
XIN: C4.1, U1.20 (XIN), Y1.3
XOUT: R3.2, U1.21 (XOUT)
~RESET: SW12.2, U1.26 (RUN)

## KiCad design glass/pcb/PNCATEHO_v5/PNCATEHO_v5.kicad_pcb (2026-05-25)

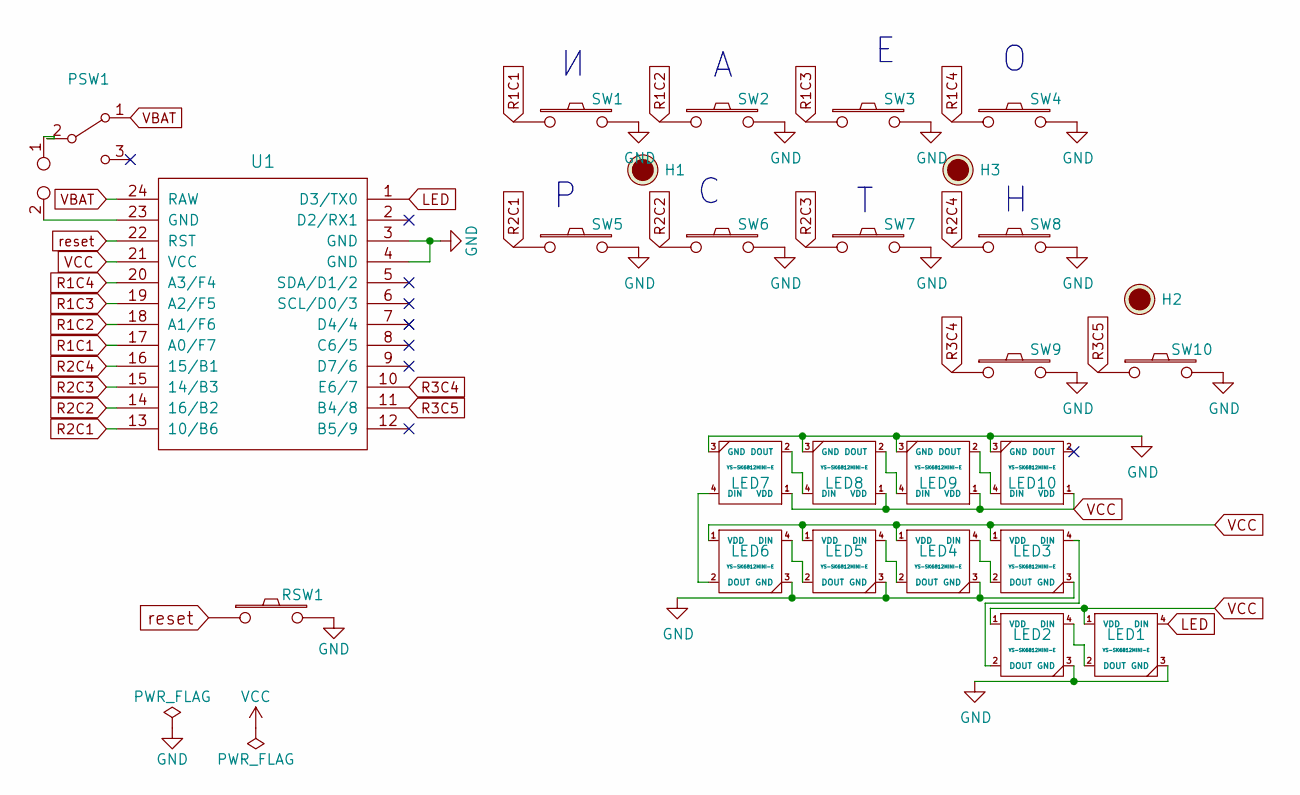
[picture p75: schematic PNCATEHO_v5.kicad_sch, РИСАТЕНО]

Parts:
H1, H2, H3: Hole
J1: TestPoint_2Pole; battery_conn_duplex
LED1, LED2, LED3, LED4, LED5, LED6, LED7, LED8, LED9, LED10: YS-SK6812MINI-E; YS-SK6812MINI-E_duplex
PSW1: SW_SPDT; MSK-12C02_DUAL
RSW1: SW_PUSH; SW_3x4x2_2legs_duplex
SW1, SW2, SW3, SW4, SW5, SW6, SW7, SW8, SW9, SW10: SW_PUSH; Kailh_socket_PG1350_reversible
U1: ProMicro_r; ProMicro_duplex_mirrored

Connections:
GND: LED1.3 (GND), LED2.3 (GND), LED3.3 (GND), LED4.3 (GND), LED5.3 (GND), LED6.3 (GND), LED7.3 (GND), LED8.3 (GND), LED9.3 (GND), LED10.3 (GND), RSW1.2, SW1.2, SW2.2, SW3.2, SW4.2, SW5.2, SW6.2, SW7.2, SW8.2, SW9.2, SW10.2, U1.3 (GND), U1.4 (GND)
LED: LED1.4 (DIN), U1.1 (D3/TX0)
unnamed: J1.2, U1.23 (GND)
unnamed: LED1.2 (DOUT), LED2.4 (DIN)
unnamed: LED2.2 (DOUT), LED3.4 (DIN)
unnamed: LED3.2 (DOUT), LED4.4 (DIN)
unnamed: LED4.2 (DOUT), LED5.4 (DIN)
unnamed: LED5.2 (DOUT), LED6.4 (DIN)
unnamed: LED6.2 (DOUT), LED7.4 (DIN)
unnamed: LED7.2 (DOUT), LED8.4 (DIN)
unnamed: LED8.2 (DOUT), LED9.4 (DIN)
unnamed: LED9.2 (DOUT), LED10.4 (DIN)
unnamed: J1.1, PSW1.2 (B)
R1C1: SW1.1, U1.17 (A0/F7)
R1C2: SW2.1, U1.18 (A1/F6)
R1C3: SW3.1, U1.19 (A2/F5)
R1C4: SW4.1, U1.20 (A3/F4)
R2C1: SW5.1, U1.13 (10/B6)
R2C2: SW6.1, U1.14 (16/B2)
R2C3: SW7.1, U1.15 (14/B3)
R2C4: SW8.1, U1.16 (15/B1)
R3C4: SW9.1, U1.10 (E6/7)
R3C5: SW10.1, U1.11 (B4/8)
VBAT: PSW1.1 (A), U1.24 (RAW)
VCC: LED1.1 (VDD), LED2.1 (VDD), LED3.1 (VDD), LED4.1 (VDD), LED5.1 (VDD), LED6.1 (VDD), LED7.1 (VDD), LED8.1 (VDD), LED9.1 (VDD), LED10.1 (VDD), U1.21 (VCC)
reset: RSW1.1, U1.22 (RST)

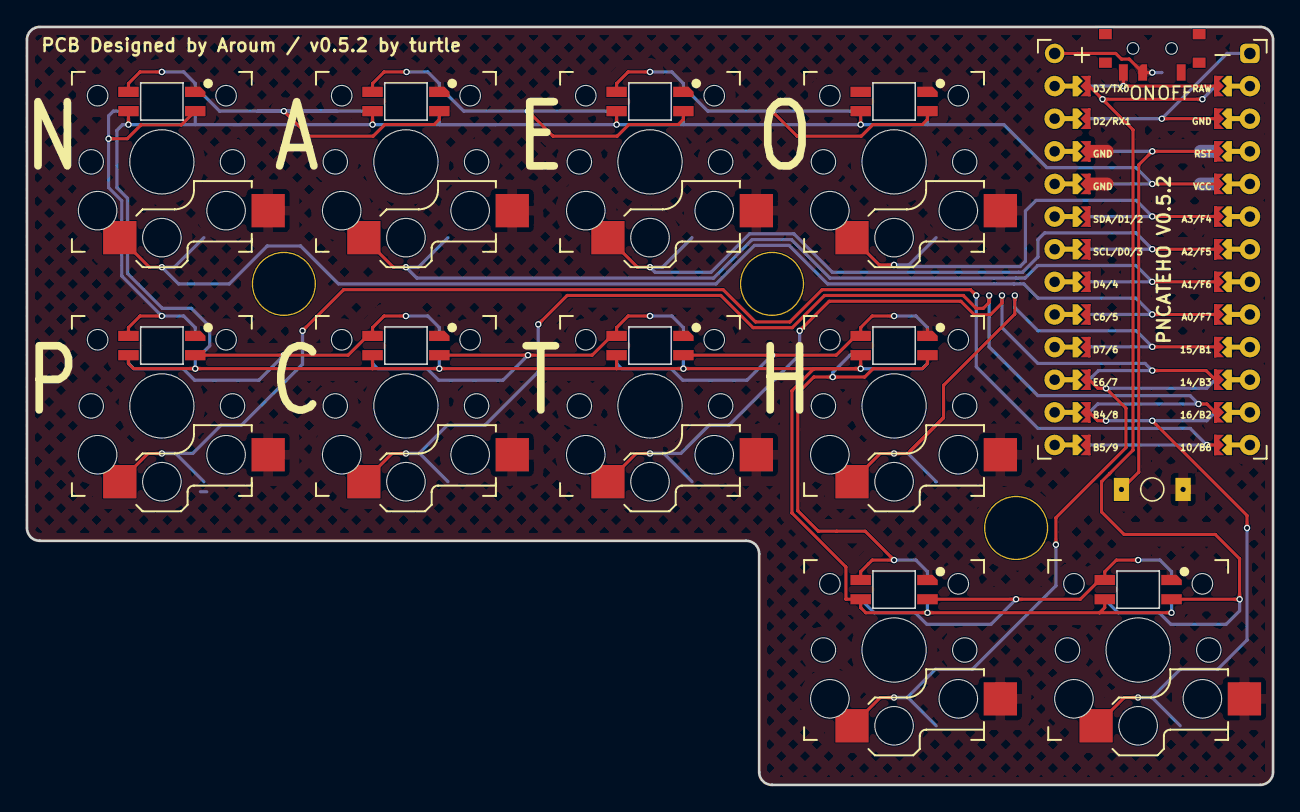
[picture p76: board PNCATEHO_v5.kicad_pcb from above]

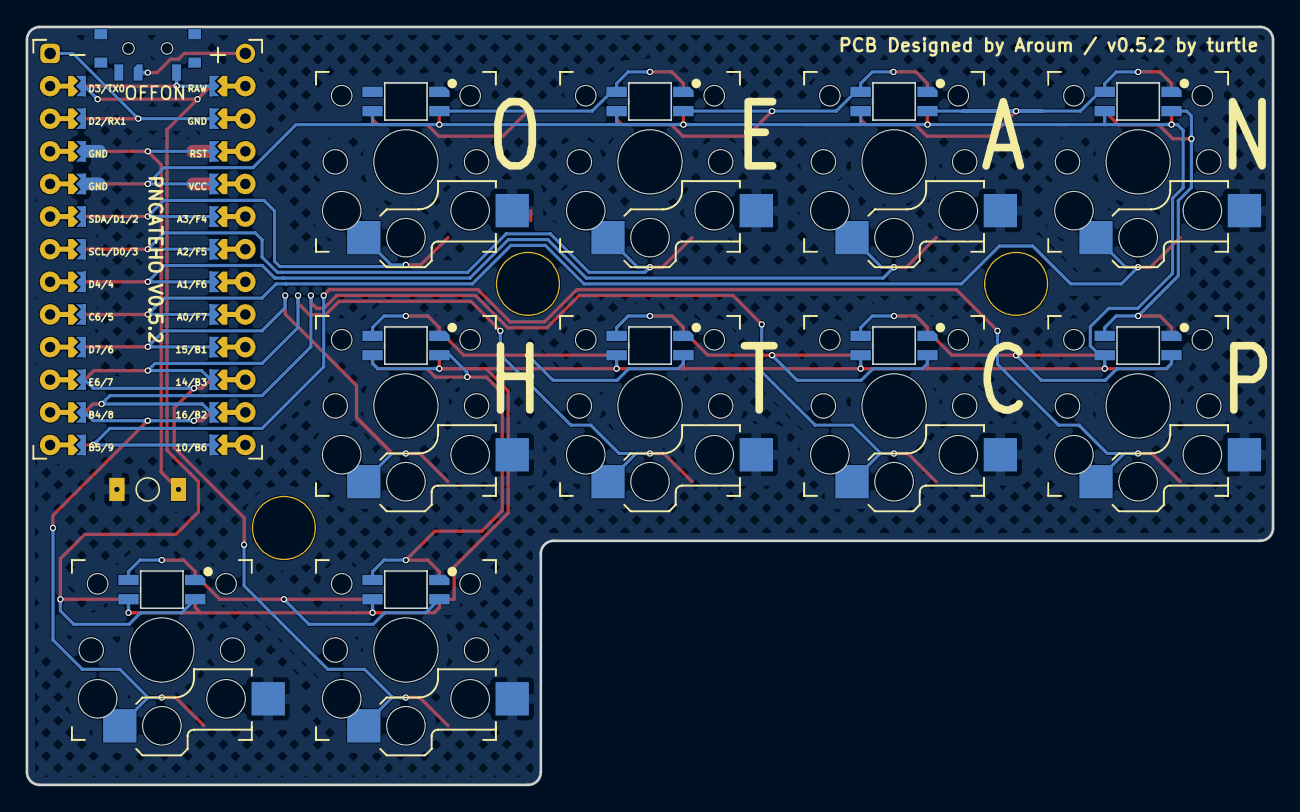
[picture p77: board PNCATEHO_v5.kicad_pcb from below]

Board: 2 copper layers, 97.0 x 59.0 mm, 27 parts (10 on the bottom side), 26 nets.

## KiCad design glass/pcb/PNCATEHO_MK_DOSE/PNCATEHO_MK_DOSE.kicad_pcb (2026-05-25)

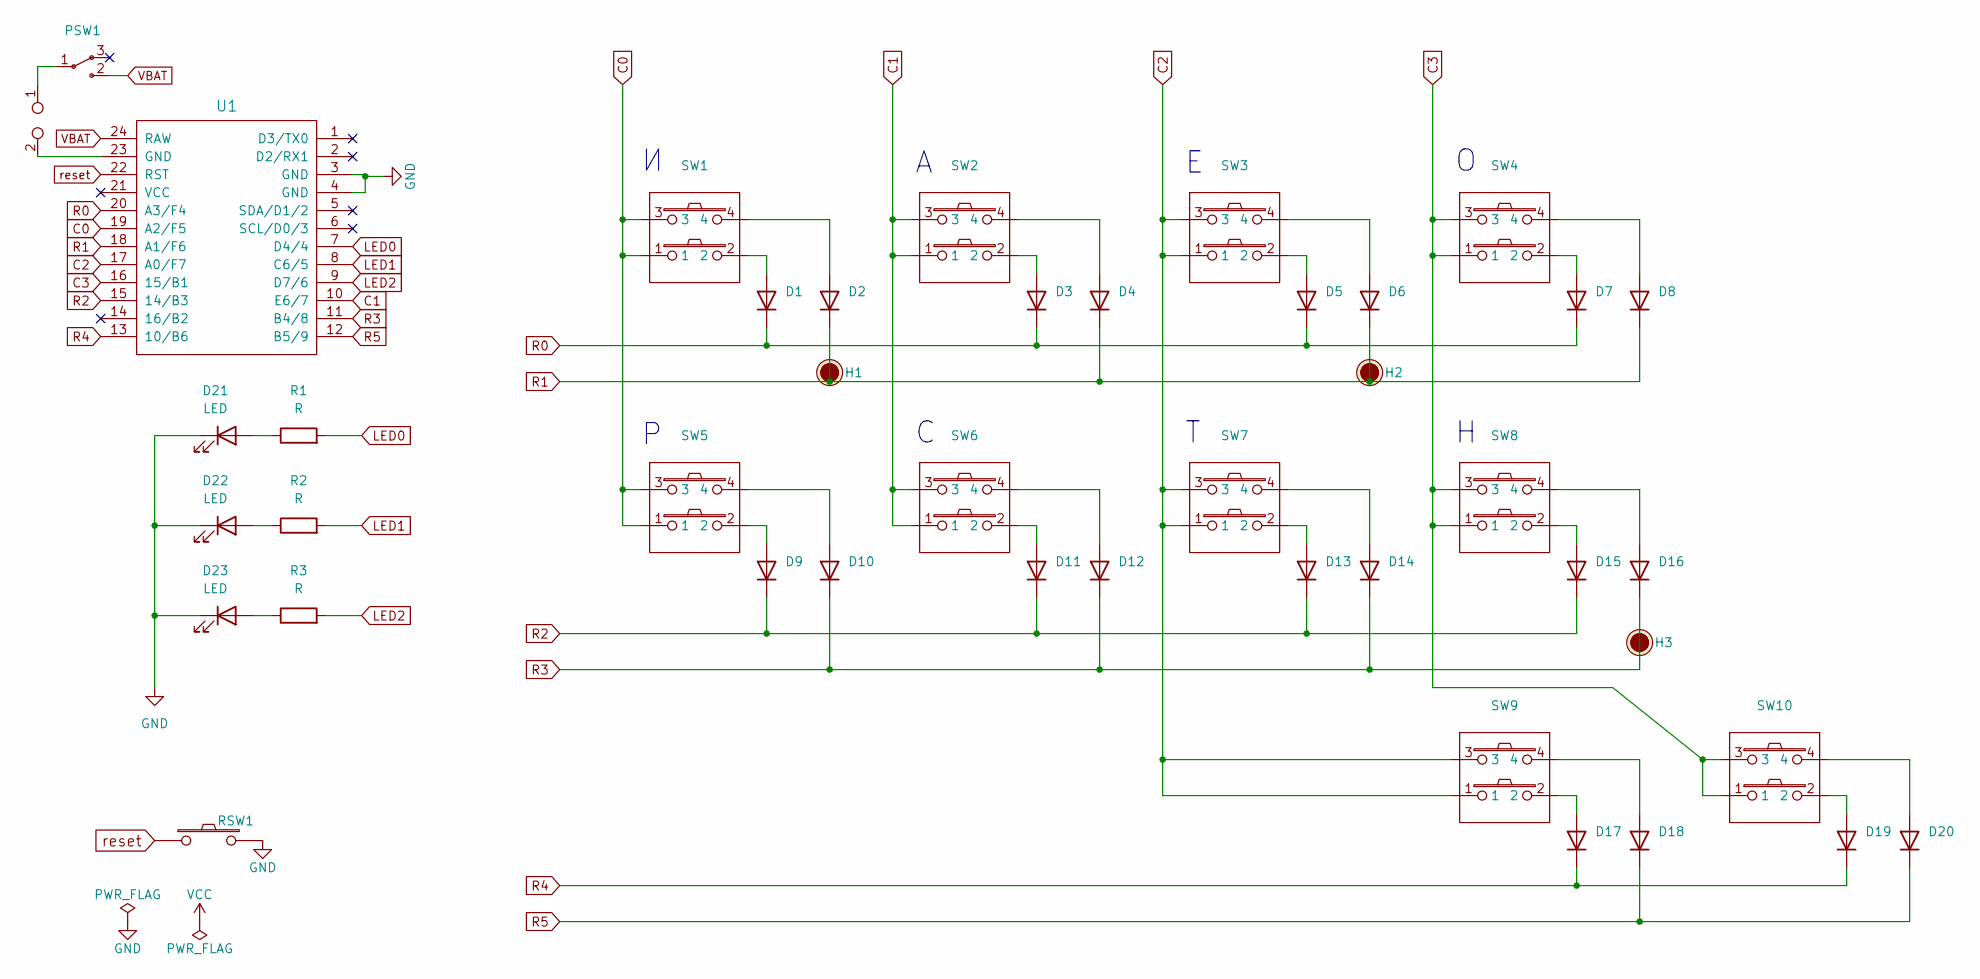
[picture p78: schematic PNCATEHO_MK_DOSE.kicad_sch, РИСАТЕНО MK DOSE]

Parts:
D1, D2, D3, D4, D5, D6, D7, D8, D9, D10, D11, D12, D13, D14, D15, D16, D17, D18, D19, D20: 1N4148W; D3_SMD
D21, D22, D23: LED; 0603-led_dual
H1, H2, H3: Hole
J1: TestPoint_2Pole; battery_conn_duplex
PSW1: bsi10h
R1, R2, R3: R; 0603-resistor_dual
RSW1: SW_PUSH; SW_3x4x2_2legs_duplex
SW1, SW2, SW3, SW4, SW5, SW6, SW7, SW8, SW9, SW10: MK-DOSE
U1: ProMicro_r; ProMicro_duplex_mirrored

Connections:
C0: SW1.1, SW1.3, SW5.1, SW5.3, U1.19 (A2/F5)
C1: SW2.1, SW2.3, SW6.1, SW6.3, U1.10 (E6/7)
C2: SW3.1, SW3.3, SW7.1, SW7.3, SW9.1, SW9.3, U1.17 (A0/F7)
C3: SW4.1, SW4.3, SW8.1, SW8.3, SW10.1, SW10.3, U1.16 (15/B1)
GND: D21.1 (K), D22.1 (K), D23.1 (K), RSW1.2, U1.3 (GND), U1.4 (GND)
LED0: R1.2, U1.7 (D4/4)
LED1: R2.2, U1.8 (C6/5)
LED2: R3.2, U1.9 (D7/6)
unnamed: D1.2 (A), SW1.2
unnamed: D2.2 (A), SW1.4
unnamed: D3.2 (A), SW2.2
unnamed: D4.2 (A), SW2.4
unnamed: D5.2 (A), SW3.2
unnamed: D6.2 (A), SW3.4
unnamed: D7.2 (A), SW4.2
unnamed: D8.2 (A), SW4.4
unnamed: D9.2 (A), SW5.2
unnamed: D10.2 (A), SW5.4
unnamed: D11.2 (A), SW6.2
unnamed: D12.2 (A), SW6.4
unnamed: D13.2 (A), SW7.2
unnamed: D14.2 (A), SW7.4
unnamed: D15.2 (A), SW8.2
unnamed: D16.2 (A), SW8.4
unnamed: D17.2 (A), SW9.2
unnamed: D18.2 (A), SW9.4
unnamed: D19.2 (A), SW10.2
unnamed: D20.2 (A), SW10.4
unnamed: D21.2 (A), R1.1
unnamed: D22.2 (A), R2.1
unnamed: D23.2 (A), R3.1
unnamed: J1.1, PSW1.1
unnamed: J1.2, U1.23 (GND)
R0: D1.1 (K), D3.1 (K), D5.1 (K), D7.1 (K), U1.20 (A3/F4)
R1: D2.1 (K), D4.1 (K), D6.1 (K), D8.1 (K), U1.18 (A1/F6)
R2: D9.1 (K), D11.1 (K), D13.1 (K), D15.1 (K), U1.15 (14/B3)
R3: D10.1 (K), D12.1 (K), D14.1 (K), D16.1 (K), U1.11 (B4/8)
R4: D17.1 (K), D19.1 (K), U1.13 (10/B6)
R5: D18.1 (K), D20.1 (K), U1.12 (B5/9)
VBAT: PSW1.2, U1.24 (RAW)
reset: RSW1.1, U1.22 (RST)

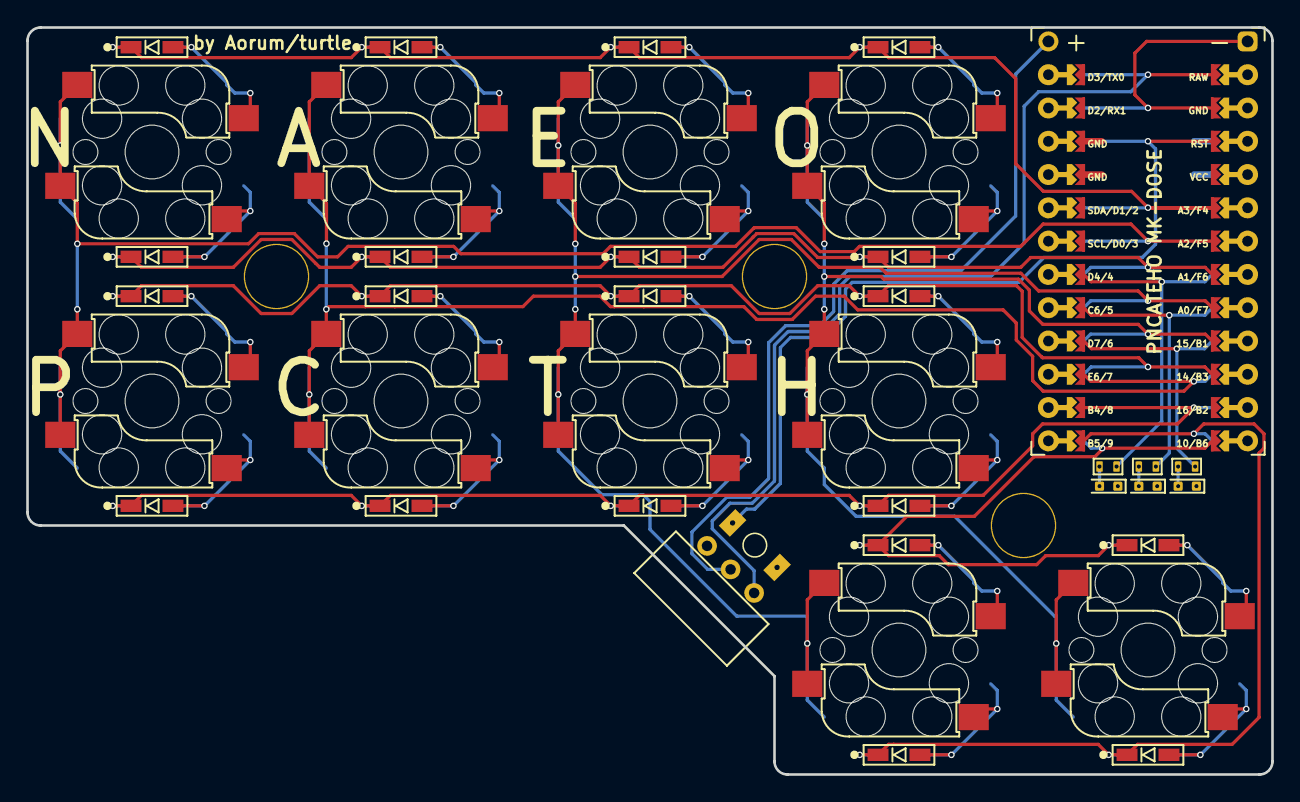
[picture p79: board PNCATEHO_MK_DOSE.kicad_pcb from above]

Board: 2 copper layers, 95.0 x 57.0 mm, 43 parts (0 on the bottom side), 41 nets.

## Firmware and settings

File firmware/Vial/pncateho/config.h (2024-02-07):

// Copyright 2023 Mayorov  (@FT256)
// SPDX-License-Identifier: GPL-2.0-or-later

#pragma once

/*
 * Feature disable options
 *  These options are also useful to firmware size reduction.
 */

#define BOOTMAGIC_LITE_ROW 0
#define BOOTMAGIC_LITE_COLUMN 1
 
#ifdef RGB_MATRIX_ENABLE
#   define RGB_MATRIX_LED_COUNT 10
#   define RGB_DISABLE_WHEN_USB_SUSPENDED // turn off effects when suspended
// #   define RGB_MATRIX_LED_PROCESS_LIMIT (RGB_MATRIX_LED_COUNT + 4) / 5 // limits the number of LEDs to process in an animation per task run (increases keyboard responsiveness)
// #   define RGB_MATRIX_LED_FLUSH_LIMIT 16 // limits in milliseconds how frequently an animation will update the LEDs. 16 (16ms) is equivalent to limiting to 60fps (increases keyboard responsiveness)
#    define RGB_MATRIX_MAXIMUM_BRIGHTNESS 255 // limits maximum brightness of LEDs to 150 out of 255. Higher may cause the controller to crash. 
#    define RGB_MATRIX_HUE_STEP 8
#    define RGB_MATRIX_SAT_STEP 8
#    define RGB_MATRIX_VAL_STEP 8
#    define RGB_MATRIX_SPD_STEP 10

/* Enable the animations you want/need.  You may need to enable only a small number of these because       *
 * they take up a lot of space.  Enable and confirm that you can still successfully compile your firmware. */
// RGB Matrix Animation modes. Explicitly enabled
// For full list of effects, see:
// https://docs.qmk.fm/#/feature_rgb_matrix?id=rgb-matrix-effects

#define ENABLE_RGB_MATRIX_ALPHAS_MODS
#define ENABLE_RGB_MATRIX_GRADIENT_UP_DOWN
#define ENABLE_RGB_MATRIX_GRADIENT_LEFT_RIGHT
#define ENABLE_RGB_MATRIX_BREATHING
#define ENABLE_RGB_MATRIX_BAND_SAT
#define ENABLE_RGB_MATRIX_BAND_VAL
#define ENABLE_RGB_MATRIX_BAND_PINWHEEL_SAT
#define ENABLE_RGB_MATRIX_BAND_PINWHEEL_VAL
#define ENABLE_RGB_MATRIX_BAND_SPIRAL_SAT
#define ENABLE_RGB_MATRIX_BAND_SPIRAL_VAL
#define ENABLE_RGB_MATRIX_CYCLE_ALL
#define ENABLE_RGB_MATRIX_CYCLE_LEFT_RIGHT
#define ENABLE_RGB_MATRIX_CYCLE_UP_DOWN
#define ENABLE_RGB_MATRIX_RAINBOW_MOVING_CHEVRON
#define ENABLE_RGB_MATRIX_CYCLE_OUT_IN
#define ENABLE_RGB_MATRIX_CYCLE_OUT_IN_DUAL
#define ENABLE_RGB_MATRIX_CYCLE_PINWHEEL
#define ENABLE_RGB_MATRIX_CYCLE_SPIRAL
#define ENABLE_RGB_MATRIX_DUAL_BEACON
#define ENABLE_RGB_MATRIX_RAINBOW_BEACON
#define ENABLE_RGB_MATRIX_RAINBOW_PINWHEELS
#define ENABLE_RGB_MATRIX_RAINDROPS
#define ENABLE_RGB_MATRIX_JELLYBEAN_RAINDROPS 
#define ENABLE_RGB_MATRIX_HUE_BREATHING
#define ENABLE_RGB_MATRIX_HUE_PENDULUM
#define ENABLE_RGB_MATRIX_HUE_WAVE
#define ENABLE_RGB_MATRIX_PIXEL_FRACTAL
#define ENABLE_RGB_MATRIX_PIXEL_FLOW
#define ENABLE_RGB_MATRIX_PIXEL_RAIN 
#endif

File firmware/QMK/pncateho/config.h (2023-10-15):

// #ifndef CONFIG_H
// #define CONFIG_H


/* USB Device descriptor parameter 
#define VENDOR_ID 0x4541
#define PRODUCT_ID 0x0002
#define DEVICE_VER 0x0002
#define MANUFACTURER Aroum
#define PRODUCT PNCATEHO
#define DESCRIPTION x - key chorded  keyboard
*/

/* key matrix size */
#define MATRIX_ROWS 2
#define MATRIX_COLS 5

/* Set 0 if debouncing isn't needed
#define DEBOUNCING_DELAY 5  */

#define DEBOUNCE 5




#ifdef RGBLIGHT_ENABLE
    #define RGBLED_NUM 10
    #define RGBLIGHT_EFFECT_BREATHING
    #define RGBLIGHT_EFFECT_RAINBOW_MOOD
    #define RGBLIGHT_EFFECT_RAINBOW_SWIRL
    #define RGBLIGHT_EFFECT_SNAKE
    #define RGBLIGHT_EFFECT_KNIGHT
    #define RGBLIGHT_EFFECT_CHRISTMAS
    #define RGBLIGHT_EFFECT_STATIC_GRADIENT
    #define RGBLIGHT_EFFECT_RGB_TEST
    #define RGBLIGHT_EFFECT_ALTERNATING
    #define RGBLIGHT_EFFECT_TWINKLE
    #define RGBLIGHT_LIMIT_VAL 120
    #define RGBLIGHT_HUE_STEP 10
    #define RGBLIGHT_SAT_STEP 17
    #define RGBLIGHT_VAL_STEP 17
    #define RGBLIGHT_LAYERS
    #define RGBLIGHT_MAX_LAYERS 5
    #define RGBLIGHT_LAYERS_OVERRIDE_RGB_OFF
    #define RGBLIGHT_LAYERS
    #define WS2812_DI_PIN B5
#endif

// #endif



/* #define UNUSED_PINS*/

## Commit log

2021-08-10 init commit
    [PNCATEHO_left.kicad_pcb, PNCATEHO_left.sch, shape.dxf]
2021-08-12 now double-sided PCB
    double-sided PCB
    add non RGB option
    update README.md
    remove gerber from code
    [PNCATEHO.kicad_pcb, PNCATEHO.sch, PNCATEHO_RGB.kicad_pcb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]
2021-12-04 add: case, plate, firmware
    [PNCATEHO.kicad_pcb, PNCATEHO.sch, PNCATEHO_RGB.kicad_pcb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]
2022-01-01 Added interactive BOM, fixed QMK config
    [PNCATEHO.kicad_pcb, PNCATEHO_RGB.kicad_pcb]
2022-08-18 rename folder
    [PNCATEHO.kicad_pcb]
2023-02-28 update pcb files to KiCAD 7.0
    [PNCATEHO.kicad_pcb, PNCATEHO.kicad_sch, PNCATEHO.sch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]
2023-10-15 v3
    * Power switch for wireless controllers(optional)
    * Two halves inscribed in 100x100 mm(optional)
    * Three mounting screws
    * One PCB for right and left versions
    [PNCATEHO.kicad_pcb, PNCATEHO.kicad_sch, PNCATEHO_RGB.kicad_pcb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]
2024-01-09 fix title
    [PNCATEHO_v3.kicad_pcb, PNCATEHO_v3.kicad_sch, PNCATEHO_v3_100x100.kicad_pcb]
2024-01-09 remove production dir, u[date readme for plate
    [bom.csv, designators.csv, positions.csv]
2025-05-06 v4
    * Added controller jumpers
    + No need to flip the controller anymore
    * Fixed RGB lighting on the right half
    * Increased case clearances by 0.2 mm for better FDM printing
    - Removed copper pour from the PCB
    [PNCATEHO_v3.kicad_pcb, PNCATEHO_v3.kicad_sch, PNCATEHO_v3_100x100.kicad_pcb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]
2025-05-23 Copy PNCATEHO v5 and MK_DOSE
    [PNCATEHO_MK_DOSE.kicad_pcb, PNCATEHO_MK_DOSE.kicad_sch, PNCATEHO_v5.kicad_pcb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]
2025-05-23 Project structure reorganization
    [PNCATEHO_MK_DOSE.kicad_pcb, PNCATEHO_MK_DOSE.kicad_sch, PNCATEHO_plate.kicad_pcb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]
2025-05-23 Add note for magnets
2025-07-10 Change led pin to TX0
    [PNCATEHO_v5.kicad_pcb, PNCATEHO_v5.kicad_sch]
2025-07-12 Added pin headers soldering helpers
2025-08-12 MK_DOSE case
    [PNCATEHO_MK_DOSE-case-bottom-left.step, PNCATEHO_MK_DOSE-case-bottom-right.step, PNCATEHO_MK_DOSE-case-top-cover-JP-katakana-left.step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]
2025-08-12 MK_DOSE case sources
2025-08-23 Change default Silicone Pad Diameter to 8mm
    [PNCATEHO_MK_DOSE-case-bottom-left.step, PNCATEHO_MK_DOSE-case-bottom-right.step, PNCATEHO_v5-bottom-case-left.step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]
2025-09-07 Parametrized cover height and lp variant exports
    [PNCATEHO_MK_DOSE-case-top-cover-JP-katakana-left-lp.step, PNCATEHO_MK_DOSE-case-top-cover-JP-katakana-right-lp.step, PNCATEHO_MK_DOSE-case-top-cover-blank-left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]
2026-05-25 Full project import from fork
    [C_0805_2012Metric.step, Crystal_SMD_3225-4Pin_3.2x2.5mm.step, D_0805_2012Metric.step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]
2026-06-06 Add firmware packages and update docs
    Add multiple firmware targets and KLE layouts (QMK, Vial, ZMK, RMK, MIDI, pra32-u and KLE JSON/PNG/PDF assets) including keymaps, configs, macros and info files for pncateho. Update README copy and eras table to emphasize PNCATEHO/RISATENO, expand wording in FAQ and intro, and fix links. Adjust doc/socket.md formatting and spacing. Add .DS_Store to .gitignore. Remove deprecated stepateno welcome module files and update glass/stone/light documentation accordingly.
    [stepateno.kicad_sch]
2026-06-06 Update Welcome era switch type in README
    Correct the Welcome era table entry to use PG1316S instead of ULP in README.md. This fixes an incorrect switch model shown in the project overview.

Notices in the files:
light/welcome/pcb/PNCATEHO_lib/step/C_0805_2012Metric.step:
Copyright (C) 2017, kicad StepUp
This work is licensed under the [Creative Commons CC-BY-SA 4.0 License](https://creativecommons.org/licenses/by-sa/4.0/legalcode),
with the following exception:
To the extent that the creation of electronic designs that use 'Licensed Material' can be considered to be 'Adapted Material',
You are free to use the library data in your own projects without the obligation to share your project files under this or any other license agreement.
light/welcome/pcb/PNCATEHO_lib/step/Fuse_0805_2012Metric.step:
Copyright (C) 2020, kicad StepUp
